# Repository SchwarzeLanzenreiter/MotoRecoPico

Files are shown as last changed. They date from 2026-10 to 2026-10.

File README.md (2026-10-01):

# MotoRecoPico

二輪車に積む CAN + GPS データロガー。**Raspberry Pi Pico 2 (RP2350)** を載せた自作基板で、
車両の CAN バスと GPS を microSD に記録する。記録したファイルは
[MotoRecoViewer](https://github.com/SchwarzeLanzenreiter/MotoRecoViewer) でそのまま開ける。

Raspberry Pi + HAT で動かしていた [MotoRecoLogger](https://github.com/SchwarzeLanzenreiter/MotoRecoLogger)
を、基板1枚に置き換えたもの。記録フォーマットは互換なので、過去のログも新しいログも同じツールで読める。

## リポジトリ構成

| ディレクトリ | 内容 |
|---|---|
| [`firmware/`](firmware/) | Pico 2 用ファームウェア（C / pico-sdk）。詳細は [firmware/README.md](firmware/README.md) |
| `cad/kicad/` | KiCad 10 プロジェクト、製造データ、生成・検査スクリプト |
| `cad/electronics/` | 旧 EAGLE 版（参考。現役は KiCad 側）|
| [`docs/`](docs/) | 設計ドキュメント。**[netlist.md](docs/netlist.md) が回路の正典** |

## ハードウェア

| 項目 | 内容 |
|---|---|
| 基板 | 4層、21 × 61 mm、部品 41点。リード部品は J1・Y1・Pico ヘッダのみ |
| MCU | Raspberry Pi Pico 2 (RP2350)。2×20 ソケットで交換可能。v4.2 で裏面実装 |
| CAN | Microchip MCP25625（コントローラ＋トランシーバ一体）を SPI1 で駆動 |
| GPS | YIC GT-502MGG-N。UART0 / 9600bps で NMEA を受ける |
| 保存 | microSD（Hirose DM3AT-SF-PEJM5）を SPI0 で駆動 |
| 車両I/F | TE MQS .63 8極。常時12V / IG / CAN High / CAN Low / GND の5本だけ使う |
| 電源 | 12V → AP63205 バックコンバータ → 5V。3.3V 系は Pico の 3V3(OUT) から |

**キーOFF 後も約 0.55 秒（実測）電源を保持する。** C13 が高側スイッチのゲート電荷を保つ仕組みで、
この猶予にファームウェアがログを閉じる。契約は [netlist.md](docs/netlist.md) §4.7。

設計の経緯（なぜ4層なのか、なぜこの配置なのか、各リビジョンで何を直したのか）は
[netlist.md](docs/netlist.md) と [hardware-design.md](docs/hardware-design.md) に残してある。
部品の購入先は [parts-sourcing.md](docs/parts-sourcing.md)。

## ファームウェア

- **単一ループ**で動く。割込みは CAN 受信と GPS UART の2つだけ
- CAN 受信は割込みでリングバッファへ退避。SD の書き込みが数百 ms 止まっても、
  コントローラの2段 FIFO を溢れさせない
- NMEA は自前でパース（Pi 版の gpsd の代替）。RTC が無いので GPS 時刻を単調時計に紐付ける
- FatFs R0.16 を同梱。SD の SPI ブロックドライバは自作
- ログの確定は **IG OFF 検出のみ**。車種依存を持ち込まないため、CAN 回転数は使わない
- タイムゾーンは microSD の隠しファイル `MOTORECO.CFG` で設定（再ビルド不要）
- ハードウェアに依存しない部分（NMEA・符号化・設定・IG 判定・時計）は
  **素の Pico 2 でも PC でもテストを実行できる**

ビルド方法・ログの読み方・トラブルシュートは [firmware/README.md](firmware/README.md) に。

## 記録フォーマット（`.dat`）

16バイト固定長レコードの連続。ヘッダも区切りも無く、すべてリトルエンディアン。

| オフセット | 型 | 内容 |
|---|---|---|
| 0 | `uint32` | ログ開始からの経過秒 |
| 4 | `uint16` | 同ミリ秒 |
| 6 | `uint16` | CAN ID（標準 11bit）|
| 8 | `uint8[8]` | ペイロード（DLC が 8 未満ならゼロ埋め）|

GPS は実在しない CAN ID に固定小数点で載せる。**`0x7FF`** が経度・緯度、
**`0x7FE`** が標高・速度。こうすると CAN と GPS が同じ1本の時系列に収まる。

> この形式は MotoRecoLogger（Pi 版）と MotoRecoViewer と**共有している契約**で、
> 変更すると3つのリポジトリすべてに影響する。

ファイル名は `YYYYMMDD_HHMMSS.dat`（キーOFF 時刻、ローカル時間）。GPS が測位するまでは
日付が分からないため `TMPnnnnn.DAT` で記録を始め、測位後に開始時刻の名前へ変える。

## 状態

- **実車で CAN・GPS ともに記録を確認済み**（2026-09）
- 基板は v4.2。実動作を確認したのは v4.1 の実基板（v4.2 は部品・ネット・GPIO 割当とも不変）
- 未確認: 記録した `.dat` を MotoRecoViewer で開く通しの確認

## 関連リポジトリ

- [MotoRecoLogger](https://github.com/SchwarzeLanzenreiter/MotoRecoLogger) — Raspberry Pi 版のロガーデーモン。本ファームウェアの移植元
- [MotoRecoViewer](https://github.com/SchwarzeLanzenreiter/MotoRecoViewer) — 記録した `.dat` を閲覧する Windows アプリ

## ライセンス

MIT License（[LICENSE](LICENSE)）。

同梱している ChaN FatFs は独自のライセンスに従う
（[firmware/third_party/fatfs/LICENSE.txt](firmware/third_party/fatfs/LICENSE.txt)）。

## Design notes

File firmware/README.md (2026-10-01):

# MotoRecoPico ファームウェア

Raspberry Pi 版ロガー（`MotoRecoLogger/mrlogger.c`）の Pico 2 (RP2350) 移植。
**`.dat` は Pi 版とバイナリ互換**で、MotoRecoViewer がそのまま開ける。

ピン割当・回路は [`../docs/netlist.md`](../docs/netlist.md) が正典。本書はソフト側だけを扱う。

## ビルド

pico-sdk と arm-none-eabi-gcc が必要。FatFs（R0.16）は
[`third_party/fatfs/`](third_party/fatfs/README.md) に同梱済み。

VS Code の Pico 拡張が入っている環境では、SDK もツールチェーンも `~/.pico-sdk` にある。
**`picotool_DIR` を渡すこと**（渡さないと SDK が picotool をソースから作ろうとし、
ホスト用 C コンパイラが無い環境では失敗する）:

```bash
cmake -B build -G Ninja -DPICO_BOARD=pico2 -Dpicotool_DIR=$HOME/.pico-sdk/picotool/2.2.0-a4/picotool
cmake --build build
```

`build/motorecopico.uf2` を BOOTSEL 起動した Pico にコピーする。

CAN バスなしでドライバを確かめたいときは `-DCAN_SELF_TEST=ON`。
MCP25625 をループバックにして、送信したフレームが戻るかを起動時に1回試す。

## テスト

ハードウェアに触らない部分（NMEA パーサ・レコード符号化・設定ファイル・IG 判定・壁時計）を検証する。
**実機（素の Pico 2 でよい。MotoRecoPico 基板は不要）でも PC でも走る。**

実機で走らせる場合 — `build/motorecopico_tests.uf2` を書き込み、USB シリアルを開く:

```
MotoRecoPico tests
checksum
GGA
...
<n> checks, 0 failures
ALL TESTS PASSED (0 failures).
```

**このテストはまだ一度も実行されていない**（開発機にホスト用 C コンパイラが無く、
Pico も接続されていないため）。コンパイルは両ビルドで通っている。最初に実機へ書き込んだ際、
失敗が出たらそれはテスト側の想定値の誤りかもしれない — 実装と突き合わせて判断すること。

実機で走らせる意味は結果だけではない。**`struct CANData` が arm で本当に16バイトに並ぶか**は
PC 上のテストでは確かめられない（`motoreco.h` の `static_assert` が実機ビルドで効く）。

PC で走らせる場合は `cd test && ./build.ps1`（MSVC）か `make`（gcc/clang）。

### 実機で確かめた数字

| 項目 | 実測 | 出所 |
|---|---|---|
| IG OFF 後の保持時間 | **約 0.55〜0.6秒** | 2026-09-04 の走行。`power still up 550ms` が最後の行で 600ms は書けなかった。§4.7 の「保証0.4秒・典型0.5秒」を裏付ける |
| 全 CAN のレコード数 | 約 1160/秒（約 18.5KB/秒）、33 ID | 実走ログ 1611秒の解析 |

シャットダウン処理（フラッシュ→sync→Close→リネーム）はこの 0.55秒に収める必要がある。
デバッグログ1行の書き込みは実測で数 ms 未満だった（生存ログの行がきっちり 50ms 刻みで並んだ）。

## 構成

| ファイル | 役割 |
|---|---|
| `src/main.c` | 初期化と単一ループ。CAN と GPS UART だけが割込み駆動 |
| `src/config.h` | ピン割当と全定数。設定ファイルの既定値もここ |
| `src/settings.c` | 設定ファイルのパース（純粋。PC でテスト可能）|
| `src/settings_file.c` | 同・FatFs 側（読み込み／既定値での生成／隠し属性）|
| `src/motoreco.h` | `struct CANData`。Pi 版と同一レイアウト（16バイト固定・LE）|
| `src/mcp25625.c` | CAN コントローラ。受信は割込みでリングバッファへ |
| `src/sd_spi.c` | SD の SPI ブロックドライバ |
| `src/diskio.c` / `src/ffconf.h` | FatFs との接続。`get_fattime()` は GPS 時刻を返す |
| `src/nmea.c` | GGA / RMC パーサ。gpsd の代わり |
| `src/wallclock.c` | GPS 時刻を単調時計に紐付けた壁時計 |
| `src/record.c` | `.dat` レコードの生成と GPS の固定小数点符号化 |
| `src/logger.c` | ファイルのライフサイクル、`f_sync`、デバッグログ |
| `src/led.c` | 緑LED の点滅パターン |
| `src/power.c` | IG OFF 判定の状態機械（純粋。PC でテスト可能）|

## Pi 版との違い

| | Raspberry Pi 版 | Pico 版 |
|---|---|---|
| CAN | SocketCAN (`can0`) | MCP25625 を SPI1 で直接。受信は割込み |
| GPS | gpsd | UART0 の NMEA を自前でパース |
| 保存 | ext4 上の `fopen`/`fwrite` | FatFs + 自作 SD SPI ドライバ |
| 時刻 | NTP 同期済みの system clock | GPS 時刻（RTC もバックアップも無い）|
| キーON/OFF | GPIO 27 を3回デバウンス | **GP28 の IG 検出**。0.55秒の猶予で確定する |
| 他プロセス連携 | System V 共有メモリ | 無し（Pico に相当物が無い）|
| デバッグログ | `canlogger.log` | `motoreco.log` ＋ USB シリアル |

## ログファイルの扱い

```
電源ON（＝IG ON）      TMPnnnnn.DAT を作って即記録開始
最初の GPS 測位        閉じて「開始時刻」の名前にリネームし、追記で開き直す
IG OFF（キーOFF）      フラッシュ → sync → Close → 「終了時刻」にリネーム → アイドル
異常断電               直前の f_sync までが確実に残る（最大1秒分の損失）
```

## ログの確定は IG OFF ただ1つ

**トリガは IG OFF だけ。** 以前は CAN の回転数低下でも確定していたが、CAN ID と
デコード式が車種ごとに違い、閾値も1台の実走データ由来だった。**イグニッション線は
どのバイクでも同じことを言う**ので、車種依存を持ち込まずに済むこちらへ一本化した。

デバッグログを `trigger:` で grep すれば確定の記録が出る:

```
[20260904 154302.233] trigger: ignition off (65mV). log closed and renamed as '20260904_154302.dat'
```

結果は成否だけでなく**何が起きたか**を出す（`logger_finalize_text()`）:

| 結果 | 意味 |
|---|---|
| `log closed and renamed as '...'` | 同期してリネームまで完了 |
| `log synced but not renamed, no gps time yet` | データは安全。GPS 未測位で名前が付けられない |
| `no log was open` | カード無し等 |
| `the card refused` | 書き込み失敗 |

**キーONのままエンジンが止まってもログは閉じない**（信号待ちのエンスト、休憩でエンジンだけ
切る等）。データ保全は毎秒の `f_sync` が担保し、確定は IG OFF で行われる。
回転数そのものは、これまでどおり CAN フレームとして `.dat` に記録される。

## IG OFF 検出（GP28）

**基板は IGN OFF 後 0.4秒（typ 0.5秒）だけ生き続ける**（C13 が Q2 のゲート電荷を保持し、
R1 経由でゆっくり放電するため）。この猶予でログを確定させるのがファームウェアの責務で、
契約は [`docs/netlist.md`](../docs/netlist.md) §4.7 に定義されている。

| 契約 | 実装 |
|---|---|
| GP28 を 50ms 以下の周期でポーリング | **10ms 周期のタイマ割込み**（`IG_POLL_INTERVAL_MS`）|
| 0.35V を下回ったら フラッシュ→Close→リネーム→アイドル | `logger_shutdown()`。**sync を最優先**し、リネームは後 |
| 猶予は保証 0.4秒（SD ストール最悪 250ms 込み）| 検出に使うのは 20ms（`IG_OFF_SAMPLES` 2回一致）|

**メインループではなくタイマ割込みで読む理由**は、SD の書き込みが数百 ms メインループを
止めることがあるためです。そこで検出まで遅れると猶予を食い潰します。
割込みは検出だけを行い、実際のファイル操作はメインループが担当します（FatFs は再入不可）。

### GP28 は電圧計ではない（v3 での変更）

**この基板では電池電圧は測れません。** v3 で R15(10k) が Q1 のベースノードに接続され、
そのノードは Q1 のベース・エミッタ接合によって**約0.65V にクランプ**されます。
つまり読めるのは **IG ON（≈650mV）/ OFF（0V）だけ**です。
0.65V はデジタル入力の VIH（約2V）未満なので、**ADC で読む必要があります**。

| 状態 | GP28 |
|---|---|
| IG ON | 約 650mV |
| IG OFF | 0mV |
| 閾値 | `IG_OFF_MV` 350mV / 復帰 `IG_ON_MV` 500mV |

status 行の `ig:` はこの**生のピン電圧**で、電池電圧ではありません:

```
status: rx:412033 records:398211 ig:651mV(on) | gps fix:1 ...
```

### 保持時間の実測（診断用・既定 OFF）

IG OFF 後、電源が尽きるまで 50ms ごとにログを書き続ける機能がある。
**カードに残った最後の行が実測値**で、2026-09-04 の走行で測った結果が以下:

```
[20260904 154302.233] trigger: ignition off (65mV). log closed and renamed as '20260904_154302.dat'
[20260904 154302.264] power still up 50ms after ignition off
[20260904 154302.314] power still up 100ms after ignition off
...
[20260904 154302.764] power still up 550ms after ignition off   ← ここで途切れた
```

**保持時間は約 0.55〜0.6秒**で、§4.7 の「保証0.4秒」に対し余裕がある。測定は済んだので
`config.h` の `IG_OFF_SURVIVAL_LOG` は **既定 0**。C13 や負荷を変えて測り直したくなったら
1 に戻す。電源が落ちかけている最中にデバッグログへ書き続けるため、その1ファイルが
chkdsk を要する形で壊れる可能性がある（**トリップログはこの時点で既に閉じて同期済み**）。

### 動作

- **一度 IG ON を観測するまで発火しない**（`armed`）。USB 給電のベンチで GP28 が 0V のまま
  でも誤ってシャットダウンしない
- **IG が戻ったら新しいログを開く**（USB 給電中にキーを戻した場合など）。閉じたファイルは
  閉じたまま、次のトリップは別ファイルになる
- アイドル中は **LED 消灯**（`LED_IDLE`）。「カード異常＝高速点滅」と紛らわしくないように
- アイドル中は 5秒ごとのカード再マウントも止める（せっかく閉じたログを開き直さないため）

## 設定ファイル `MOTORECO.CFG`

SDカードのルートに置く**隠しファイル**。無ければ起動時に既定値で自動生成する。
`#` で始まる行はコメント。テキストエディタで編集できる。

```ini
# MotoRecoPico settings
#
# Lines starting with '#' are comments. Edit with any text editor.
# This file is hidden; enable "show hidden files" to see it.
#
# timezone: offset from UTC, used for the .dat file names and the debug log.
#           whole hours (+8, -5) or with minutes (+5:30).
timezone = +9
```

| キー | 内容 | 既定 |
|---|---|---|
| `timezone` | UTC からのオフセット。`+9` / `-5` / `+5:30` / `+5.5` を受け付ける。`.dat` のファイル名とデバッグログの時刻に効く | `+9`（JST）|

- `key = value` でも `key value` でも通る。キーは**大文字小文字を区別しない**
- 読めない行は**その行だけ**無視してデバッグログに残す。ファイル全体を捨てたりはしない
- 正常時のログ: `settings: timezone +09:00`
- カードを差し替えると、その**カードの設定ファイルが読み直される**（マウントのたびに読む）

### 廃止された `vehicle` キー

以前はエンジン回転数のデコード規則（車種）を選ぶ `vehicle` キーがあった。
回転数によるログ確定をやめたので不要になっている。**古いファームで書かれたカードには
この行が残っている**ため、パーサは `vehicle` を「廃止済み」として黙って読み飛ばす。
手で消さなくても、起動のたびに警告が出ることはない。

## ピン割当（基板 v4.1）

正典は [`docs/netlist.md`](../docs/netlist.md) 3.7節。`src/config.h` がこれに追従する。

| 機能 | GPIO | 備考 |
|---|---|---|
| microSD | GP2/3/4/5 | **SPI0** SCK/MOSI/MISO/CS |
| SD カード検出 | GP7 | 外部プルアップ R13 |
| GPS UART0 | GP0（TX）/ GP1（RX）| GP1 にモジュールの TXD（オレンジ）|
| GPS PPS | GP6 | 未使用（入力のまま）|
| LED 緑 | GP8 | Low で点灯 |
| CAN MCP25625 | GP10/11/12/13 | **SPI1** SCK/MOSI/MISO/CS |
| CAN INT / STBY / RESET | GP9 / GP20 / GP21 | |
| IG 検出 | GP28 (ADC2) | 回転で変わらず。**ON/OFF のみ**で電池電圧は測れない |

**GP14〜GP19・GP22・GP26・GP27 は基板上で GND に落ちている。絶対に出力にしないこと。**

v4 からの差分は Pico の 180° 回転によるもので、**SPI インスタンスも入れ替わっている**
（SD が SPI1→**SPI0**、CAN が SPI0→**SPI1**）。ピンだけ直して SPI を直し忘れる事故を防ぐため、
`sd_spi.c` と `mcp25625.c` に「そのピンが本当にそのインスタンスの SCK/TX/RX か」を
`_Static_assert` で検査してある（RP2350 は 8ピンごとにインスタンス、4ピンごとに機能が巡回する）。

**stdio を UART に出してはいけない。** GP0/GP1 は SDK の stdio UART の既定ピンでもあるため、
有効にすると printf が GPS モジュールの受信端子に流れ込む。デバッグ出力は USB CDC のみ。

## LED（緑・GP8、Low で点灯）

| 表示 | 意味 |
|---|---|
| 点灯 | 記録中 |
| 1Hz 点滅 | 記録中だが GPS 未測位 |
| 高速点滅 | カードが使えない（応答なし／マウント失敗／書き込みエラー）。5秒ごとに再試行中 |
| 消灯 | IG OFF を検出してログを閉じた後（通常は直後に電源が落ちる）|

## GPS の状態ログ

測位に時間がかかるとき、原因は「配線・ボーレートが違って一切受信していない」「アンテナが空を見ていない」
「単にコールドスタート中」のどれかで、**どれも「未測位」としか見えない**。区別できるよう、
受信機自身の見え方をログに出す。

未測位の間は `GPS_REPORT_INTERVAL_MS`（既定10秒）ごとに:

```
gps searching after 30s: quality:0 mode:1D sats used:0 view:9 tracked:4 best snr:28 hdop:0.0 sentences:301 bad:0
```

読み方:

| 症状 | 出力 | 意味 |
|---|---|---|
| 何も受信していない | `gps silent: nothing received on uart0 in 30s...` | 配線・電源。モジュールは測位前から喋るので、無音は受信の問題ではない |
| 受信しているが壊れている | `sentences:0 bad:250` が増え続ける | ボーレート違い（文字化けでチェックサム不一致）|
| `view:0 tracked:0` のまま | 衛星が1個も見えない | アンテナ面が空を向いていない、金属ケース内、モジュール不良 |
| `view:9 tracked:1 best snr:15` | 見えてはいるが信号が弱い | 遮蔽（ビル・屋内・タンク下）。SNR 30以上が数個ないと測位しない |
| `view:9 tracked:5 snr:30+` で待ち | 正常な取得中 | あと数十秒待てば入る（下記のコールドスタート）|

測位した瞬間と失った瞬間にも1行ずつ出る（`gps fixed after 42s: ...` / `gps fix lost after ...`）。
最初の1文を受信した時点でも `gps talking: first sentence '$GNGGA' at 9600 baud` を出すので、
**配線とボーレートが合っているかは起動直後に確定できる**。

### 実機で確定した配線（2026-08-14）

**ボーレートは 9600bps**（`GPS_UART_BAUD` の既定値どおり）。線色と J3 パッドの対応:

| J3 パッド | シルク | 繋ぐ線 | 色 |
|---|---|---|---|
| 1 | V | VCC | 赤 |
| 2 | G | GND | 黒 |
| 3 | T | **RXD** | **緑** |
| 4 | R | **TXD** | **オレンジ** |
| 5 | P | PPS | 茶 |

**シルクの T / R は基板側から見た名前で、モジュールのピン名とは逆になる。**
UART は交差するので、`T`（基板が送信）にはモジュールの **RXD（緑）** が付く。
「TXD（オレンジ）を T に」と読んで配線すると出力どうしが衝突し、1バイトも受信できない
（実際にこれが起きた）。正典は [`docs/netlist.md`](../docs/netlist.md) 3.5節。

### 測位が遅いこと自体の原因

**J3 はバックアップ電源を持たない**（`docs/netlist.md` の J3 は VCC / GND / TXD / RXD / PPS の5線のみ）。
つまり**キーOFF のたびに軌道暦を失い、毎回コールドスタートになる**。
一般的な受信機のコールドスタートは晴天・見晴らしの良い場所で 30〜45秒、
条件が悪ければ数分かかる。ホットスタートなら1〜2秒で入るので、この差は大きい。

改善するならハードウェア側の変更になる:
- GT-502MGG-N にバックアップ端子があるなら、常時12V系からそこへ給電する（データシート 2.1節を要確認）
- あるいは J3.VCC を常時電源にする（受信機が待機電流を食い続けるためバッテリー上がりとの兼ね合い）

**現状のログはこの判断材料を出すためのもの**で、`gps fixed after Ns` の N が毎回30〜45秒なら
コールドスタートそのもの、毎回数分なら遮蔽かアンテナの問題、という切り分けができる。

## カード検出（GP7）の扱い

**カード検出ピン（GP7）は判断材料であって判断者ではない。** カードの有無は「SPI で応答するか」で決める
（[`sd_spi.c`](src/sd_spi.c) の `sd_init()` は検出線を見ずに必ず試す）。理由は3つ:

- 検出スイッチはソケットで**最も小さいパッド2枚（9番と10番）**に載っており、はんだ不良の確率が高い
- 接点が「挿入で閉」なのか「挿入で開」なのかは **DM3AT の図面に明記がない**（`SD_CD_INSERTED_LEVEL` は仮定）
- 二輪の振動でチャタれば、正常なカードを切り離してしまう

`SD_CD_INSERTED_LEVEL` を間違えていても**記録は普通に動く**。失うのは「走行中の抜去を早期に検出する」機能だけで、
それも実際に抜かれれば次の書き込み失敗で検出される。

走行中の抜去チェックは、**一度でも「検出線が挿入と言っている状態で実際にカードが応答した」場合にのみ**有効になる
（`sd_detect_reliable()`）。食い違ったまま動いた場合は起動時に一度だけ警告を出す:

```
note: card detect (GP7) reads empty with a working card. ignoring it.
      check pad 9/10 solder, or flip SD_CD_INSERTED_LEVEL
```

## データ量の目安（同じ実走ログより）

全 CAN で **約 1160 レコード/秒（約 18.5 KB/秒）**、33 種類の ID。
27分の走行で 30MB。受信リング 4096 レコードはこのレートで **約 3.5 秒分**にあたり、
SD カードの書き込みが数百 ms 詰まっても溢れない。

## 実機で最初に確認すること

1. USB シリアルに `MotoRecoPico starting` → `logging to '...'` → `can controller ready` が出るか
2. CAN が1フレームも来ない場合: `config.h` の `CAN_BITRATE`（既定 500kbps）と、
   終端抵抗 R8（`docs/netlist.md` の「CAN 終端は常時有効」）を疑う
3. カードが使えない場合、USB シリアルのメッセージで切り分ける:
   - `no card: the slot reads empty and nothing answered on the card spi` → SPI 配線（MISO/MOSI/CS）、
     カードの挿し込み不足、3V3 の供給
   - `a card is in the slot but no log file could be opened...` → **まず exFAT を疑う**。
     32GB超のカードは工場出荷時 exFAT で、`FF_FS_EXFAT 0` のため弾かれる。FAT32 で再フォーマット
   - `note: card detect (GP7) reads empty with a working card` → 記録は動いている。
     パッド 9/10 のはんだと `SD_CD_INSERTED_LEVEL` の極性を後で確認すればよい
4. GPS のボーレート（`GPS_UART_BAUD`、既定 9600）
5. キーOFF で `trigger: ignition off (...)` が出て、ファイル名が終了時刻になっているか
6. 記録した `.dat` を MotoRecoViewer で開き、Pi 版のログと同じように描けるか

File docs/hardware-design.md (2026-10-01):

# MotoRecoPico ハードウェア設計仕様

Raspberry Pi Pico 2 ベース CAN ロガー（二輪車搭載）

- 対象: 車両12V電源のみ、MQS 8極コネクタ直結、MicroSD 基板実装
- 基板: 4層、21 × 61 mm。チップ部品は 1608（JLCPCB 実装）

> **回路の詳細（部品表・ネットリスト・電源アーキテクチャ・ピン割当）は
> [netlist.md](netlist.md) が正典。** 本書はコネクタ／フットプリントの一次資料からの
> 導出根拠と基板レイアウトのみを扱う。
>
> 旧版にあった LM2596 / GPS用LDO / ラッチング電源 / 赤LED / GPSスルーホールの
> 記述は設計変更により無効。削除済み。

---

## 1. 部品構成（確定分）

| 部品 | 型番 | パッケージ | 備考 |
|---|---|---|---|
| MCU | Raspberry Pi Pico 2 (RP2350) | 2×20 2.54mm ヘッダ | ソケット実装で交換可能に |
| CAN | MCP25625T-E/SS | SSOP-28 (0.65mm) | コントローラ＋トランシーバ一体 |
| GPS | GT-502MGG-N | 外付け（1.5m 先バラ5線） | 片面 SMD パッドに直付け |
| 保存 | Hirose DM3AT-SF-PEJM5 | SMD ライトアングル | プッシュプッシュ式、カード検出付 |
| 車両I/F | TE 1-967658-1 | MQS .63 8極 2列 4mm ライトアングル TH | 車両カプラー直結 |
| 降圧 | **Diodes AP63205WU-7**（v4） | TSOT-26 + L/C 4点 | 3.8〜32V入力 / 5V固定 2A 同期整流。最背は L1 の 3mm |
| 高側スイッチ | **Diodes ZXMP6A17E6Q** | SOT-26 | −60V / −3A / AEC-Q101 |

### MQS コネクタ ピン割当（ユーザー指定）

| ピン | 信号 |
|---|---|
| 3 | IG ON 時 12V |
| 4 | GND |
| 5 | CAN Low |
| 6 | CAN High |
| 8 | 12V 常時 |

未使用: 1, 2, 7

### MQS コネクタ フットプリント（図面 967658 Rev.C3 より確定）

原点はコネクタ前面基準線上の中心 ¢。+X は右、+Y は基板端（嵌合方向）。
穴は基準線から Y マイナス方向（基板内側）へ。

| ピン | X [mm] | Y [mm] | 列 |
|---|---|---|---|
| 1 | +7.0 | −3.76 | 前列（下段コンタクト） |
| 2 | +3.0 | −3.76 | 前列 |
| 3 | −1.0 | −3.76 | 前列 |
| 4 | −5.0 | −3.76 | 前列 |
| 5 | +5.0 | −6.30 | 後列（上段コンタクト） |
| 6 | +1.0 | −6.30 | 後列 |
| 7 | −3.0 | −6.30 | 後列 |
| 8 | −7.0 | −6.30 | 後列 |

| 項目 | 値 |
|---|---|
| 穴径 | ⌀1.0mm 以上（8ヶ所）→ ドリル 1.1mm、パッド ⌀1.8mm 推奨 |
| 列内ピッチ | 4.0 ±0.1mm |
| 列間ピッチ | 2.54 ±0.1mm |
| 列間の水平オフセット | 2.0mm（千鳥配置） |
| 基準線→前列 | 3.76mm（= 6.3 − 2.54） |
| 基準線→後列 | 6.30 −0.1mm |
| ハウジング幅 | max 19.6mm |
| ハウジング全高 | 18.1 ±0.15mm |
| テール突出量 | 3 ±0.25mm |
| 位置度公差 | ⌀0.3 (8ヶ所) |

**ピン番号の導出根拠**: 嵌合面視では下段が左から 1・2・3・4、上段が左から 5・6・7・8。
断面図 G-M より、上段コンタクトのテールは嵌合面から遠い側（後列）、下段は近い側（前列）に降りる
（上段テールの垂直部が下段コンタクトの水平部と干渉しないため、必然的にこうなる）。
嵌合面視の左右は基板上面視と反転するため、上表の X 座標になる。

材質: ハウジング PBT-GF20 (Ultradur B4300-G4) 黒 / コンタクト CuFe2 錫めっき
相手側ハウジング: AMP 1534229（8極）　製品仕様書: 108-18568

図面の注記 7 に「この領域は全周シール面（Ra 0.7µm）」とあり、
**相手側ハウジングと組んだ状態ではシール構造を持つ**。当初「MQS は非防水」と記載したが誤りだった。
ただしケース貫通部のシールは別途必要。

---

## 6.1 基板レイアウト

外形 **21 × 61 mm（12.8cm²）**、**4層**。設計データは `cad/kicad/` の KiCad 10 プロジェクト。

| 面 | 部品 |
|---|---|
| 表 | 26点。**J1（v4で移動）**、U2、J2、1608 チップ23点すべて。**v4.2 で Pico が裏面に移り、J1 以外は全て低背で露出** |
| 裏（Pico側）| 15点。**U3(Pico ソケット、v4.2)**、Y1、J3、バック一式（U4/L1/C14-C16）と SOT/SOD/SMA（**1608 は無し**）。Pico の下の最背は 3mm |

### 層構成

| 層 | 用途 | 実配線長 |
|---|---|---|
| F.Cu | 信号 | 227mm |
| In1.Cu | **GND プレーン** | 158mm |
| In2.Cu | **3V3 プレーン** | 145mm |
| B.Cu | 信号 | 196mm |

**2層は二度試し、二度とも採らなかった。** v1 では 0.127mm（工程下限）を要したうえ
GND ベタが8分断・7浮き。v2 で部品が3点減った際に再試行したが、配線は通っても
**サーマルスポークが届かない GND パッドが 2〜6点残り**（5シード×ギャップ3種の全組合せ）、
サーマル接続という v2 の目的と両立しなかった。4層は 0.15mm・スポーク全数到達で成立する。
基板代は5枚で $2.10 → $7.10（+$5.00、送料込み総額で +17%）。

**内層にも信号が乗っている。** ルータには内層をプレーンとして渡したが、
Freerouting は必要に応じてその上も通す。
それでも In1 の GND 銅箔は **1領域が全体の100%**（v4.2: 972.2mm²、分断ゼロ。In2 の 3V3 も 1 領域 881.1mm²）で、
プレーンとしては分断されていない。この配線密度でしか 0.15mm 線幅が成立しないため、
分断されない範囲での内層使用は許容している。

**外層のベタは配線後に流す。** 配線前に F.Cu / B.Cu へ GND を流し込むと、
Freerouting が信号層を使いきれず未配線が残った。GND を運ぶのは内層プレーンなので、
外層は配線が終わってからベタにしている。

**1608 チップは全数（23点）を表面に集約**してある（v3。実装とリワークを片面に限定するため）。
それより大きい部品は両面に分かれる。

### 外形寸法が決まる理由

**長さ61mm は幾何的な下限に近い。** MQS の穴は Pico のヘッダー穴列と X 方向で 1.89mm しか
離れず、⌀1.8mm パッドでは隙間 0.09mm となり製造不可能。よって MQS はヘッダー格子の
外側に自分の帯を必要とする。

MQS ハウジングは基板上に 8.0mm せり出す。ユーザー指定によりヘッダーとの隙間は
**0.57mm** としてある。v4.2 で Pico ソケットが裏面に移ったため、MQS のテール（裏面ではんだ付け）と
ソケット本体が同じ面で 0.1mm まで近づく。**MQS を先にはんだ付けし、ソケットを後から立てる組立順**が前提。

**幅21mm は Pico のフットプリント幅そのもの。** ヘッダー穴列が x=1.61 / 19.39 にあるため、
使える領域は列の間の 15.2mm しかない。側面発光LEDと GPS パッドは長辺に置けず、
LED は短辺（y=61）へ、GPS パッドは裏面中央へ回した。

| 辺 | 実装 |
|---|---|
| 短辺 y=0 | J1（**表面**（v4）、嵌合口が基板外を向く。穴パターンは v3.1 の鏡像）|
| 短辺 y=61 | J2 MicroSD（表面、挿抜口が基板端の内側約1mm）、D6 サイドビューLED（裏面）、**Pico の USB ポート（v4.1 で y=61 端へ、v4.2 で裏面側・ソケット高 +8.5mm の位置）** |

**LED・カードスロット・USB が同じ短辺に集まるため、ケースの開口はこの端面に集約できる。**
y=0 端は MQS カプラのみ。

**Pico は裏面に載せてある（v4.2）。** 面反転はフットプリントの x 鏡像なので穴は1つも動かず、
ピン1〜20 の列が左（x=1.61）に、21〜40 が右に入れ替わるだけ。v4.1 の GPIO 割当は y 方向の
近さで決めてあり鏡像で保たれるため、**再割当もファームウェア変更も無い**。狙いは表面を
J1 以外すべて低背部品（U2・J2・1608 チップ）にして、Pico を外さずに実装・リワーク・
プロービングできるようにすること。裏面の電源ポケット・Y1・J3 は Pico の下（ソケット高 8.5mm、
部品最背 3mm）に入る。**J3 の GPS 配線は Pico を抜いてはんだ付けする。**

**Pico は 180° 回転してある（v4.1）。** v4 で J1 が表面に来た結果、USB コネクタが
18.1mm の MQS ハウジングの 0.6mm 隣を向き、ケーブルが物理的に挿せなかった。
2×20 ヘッダー格子は 180° 回転対称なので**穴は 1 つも動かず**、各穴に入るピンが
対角（k ↔ k+20）に入れ替わるだけ。GND ピン 8 本は対称位置どうしが共に GND のため
バレルの役割も不変。ただし信号ピンの物理位置は全て裏返るため、
**GPIO 割当は回転後の距離で再導出した**（SPI0↔SPI1 の役割交換が鍵。
正規の表は netlist.md §3.7。ファームウェアのピン定義変更が必要）。

### 配置で守った設計上の要件

**U2 を 90° 回転してある。** 回転前は SSOP-28 の2列が長辺を向き、28ピンすべてが
幅 3.1mm の側方通路へ脱出しようとしていた。物理的に通らない。

**U2 のデカップリングは IC の左右（脱出領域の外）に置いた。** 上下に置くと
28ピンの扇形展開を塞ぐ。チップは 90° 立てて側方の隙間に収めている。

**裏面の大物2点（Y1・J3）は 90° 回転して右側に縦積み。** 寝かせると幅12mm 前後で
15.2mm の帯を横断し、裏面が分断されて縦方向に何も通らなくなる。

**Y1（水晶）は裏面。** HC-49/S はスルーホール品なので、差し込む面＝本体が乗る面。
v4.1 までは Pico が表面を占有するため裏面から挿していた。v4.2 で Pico も裏面に来たが、
HC-49/S の高さ（3.5〜4.7mm）はソケット高 8.5mm の下に収まるのでそのまま。パッドは両面にあるのでビアは不要。

**C7/C8（水晶負荷）は表面で Y1 の両バレルを挟む明示配置（v3）。**
Y1 のスルーホールが XTAL ネットを表面へ運ぶため、コンデンサはビアなしでバレル直結できる。
v2 では左端ゾーン任せで 11.1 / 9.0mm 離れ、XTAL1 が In1 プレーンの中を 8.5mm 通っていた。
v4.2 実測: C7 2.24mm / C8 2.77mm、XTAL1 9.7mm（ビア0・内層0）/ XTAL2 14.6mm（ビア0・内層0）。
ゾーン任せでは他ゾーンのスピルに枠を奪われるため EXPLICIT で固定してある。
C8 の回転は 270°（90° だとピン1が遠い側を向く）。

**電源部品は電気の流れ順に一列。** J1 → F1 → D1 → Q2 → U4(バック) を、給電ピンの位置から
素直につながる順序で裏面に並べてある。**v4 で J1 の面反転に伴い列全体を左右鏡像化**した
（12V の入口が x17.5 → x3.5 に移ったため。左から右へ F1 → D1 → Q2、バックは直下）。

| 区間 | ピン間距離 |
|---|---|
| V12_RAW（J1.8 → F1.1）| 3.47mm |
| V12_FUSED（F1.2 → D1.2）| 1.85mm |
| V12P（D1.1 → Q2.4）| 3.40mm（v4.2、Q2 立て置き）|
| V12_SW（Q2 → U4.VIN）| 6.40mm |
| **合計** | **15.12mm**（v4.2。v4 は 14.83mm）|
| SW ノード（U4.SW → L1）| 3.99mm（v4.2、L1 回転。v4 は 2.09mm）|
| 入力コンデンサ（U4.VIN ↔ C14）| 2.90mm |
| 出力コンデンサ（L1 ↔ C15）| 3.07mm |
| ブートストラップ（U4.BST ↔ C16）| 4.03mm |

見直し前は同じ経路が **36.1mm** あった。12V が J1 の右端（x=17.5）から入るのに
F1 が 17mm 下の中央にあり、そこから左端 → 上 → 右へ戻る「コの字」を描いていた
（第1区間だけで 17.4mm）。DC 100mA 程度なので機能上の問題ではないが、
入力側の電流ループを締めるのと、レイアウトを追える状態にしておくために直した。

**Q2 は U4 と同じ手はんだ用ランドで 90° 立てて配置（v4.2）。** v4.1 の標準 SOT-23-6 ランドは
パッドが短く、実基板でゲートリードの未はんだが起きた。2.0×0.65mm パッドにすると幅 6mm になり
F1/D1 の列に入らないため、右列に立てて S/G を D1 側、ドレインを基板端側に向けてある。
パッド番号は JEDEC 順のままなので、G=3 / S=4 のビルド毎 assert はそのまま効いている。

**L1 はパッドを外側へ 1mm 延長した自作ランドで 90° 回転（v4.2）。** 標準ランドは 4×4 本体の外に
こて先を置く銅箔がなく、U4 の SW パッドとも近接していた。延長ランド（`L_4030_HandSolder`）を
±y 向きに置き、SW 側パッドを U4 の SW 列の横（4.0mm）、V5 側を直下の C15（3.1mm）に繋いでいる。

**裏面左端の電源スタックは Pico 左列パッドから 2.5mm 離してある（v4.2）。** 面反転で CAN の
SPI 4 本が左列から出て U2 上段右端の SPI ピンへ向かうため、左端に 1.3mm しか残さない詰め方では
CAN_MISO が 20 シード中 19 で未配線になった。L1 左端 x4.9、D2/Q1/D3 左端 x4.0 に寄せている。

**バック一式（U4・L1・C14〜C16）は U1 が空けた裏面ポケット（y13〜21）に収めた（v4）。**
v4 では U4 と L1 を SW パッド同士が向き合う回転で明示配置した（逆向きだと SW ノードが 8.5mm に伸びる）。
C14（入力 10µF/50V）は U4 の VIN 列の右隣 — 初回は U4 の手はんだ用コートヤード内に
置いてしまい DRC が短絡を検出したため、ブロック全体を 2.4mm 左に詰めて確保した。
v4.2 では Q2 の立て置きと L1 の回転に合わせて、U4 を 1mm 下げ、C14 を Q2 の下、C16 を U4 の下、
C15 を L1 の V5 パッド直下に組み替えてある（いずれも `mrp_brd.py` の EXPLICIT で固定）。

**C2 は右フランクに単独の枠を持つ。** チップがまだ 1005 だった頃、耐圧の都合で
C2 だけを 1608 に上げた。すると自動配置が面積の大きい順に詰めるため C2 が分圧抵抗の
ゾーンの左端を取り、**R1〜R4 が 2.75mm 右へずれた**。それだけで SD_CD が J2 の脇を
抜ける通路を失い、どのルータ設定でも1本残った（`-oit` と `-mp` を6通り試して全て1本）。
C2 に専用枠を与えて分圧抵抗の列を元に戻したところ、1回目で未配線0になった。

その後チップは全数 1608 になり C2 は特別な大きさではなくなったが、
**この枠は検証済みの配置なので残してある**。

**R8（CAN 終端 120Ω）は U2 の南側、CANH/CANL が出るパッドの直下。**
当初これを U2 の西側（x 2.9〜5.6）に置いていたところ、U2 の北西角から
Pico 左列へ回り込む唯一の通路を塞ぎ、CAN_RESET が最後まで配線できなかった。
本来ここにあるべき部品で、移して未配線 0 になった。

### 検証済み項目

| 項目 | 結果 |
|---|---|
| 部品配置 | 41点、表26 / 裏15（v4.2: Pico が裏面）|
| チップ部品（1608）| 23点すべて表面（自動検査を C1608 まで拡大）|
| 同一面での部品重なり | なし |
| 他部品の穴の上に本体が乗っていないか | なし（自動検査）|
| 基板外形からのはみ出し | なし（J1 のみ設計どおり y=0 辺を越える）|
| 回路図とのネット一致 | 40ネット すべて一致 |
| 配線 | 全数完了。328トラック / ビア182本（うち GND 137本）。XTAL 内層0はシード選定で自動保証（xtal_check）|
| DRC 違反 | 0件 |
| 未接続パッド | 0個 |
| 浮き銅片（ビアもパッドも無いベタ領域）| 0個（全6領域を実測）|
| 電源チェーン長 | 14.83mm（v1 初版 36.1mm）|

**GND パッドは全数サーマル接続（v2）。** スポーク 0.4mm / ギャップ 0.3mm / 最小スポーク数 1。
v1 のベタ直結は手はんだ時の熱逃げが酷く、実基板で許容できないと判断して改めた。
スポークが全パッドに到達していることは DRC の未接続0で担保している。

配線は Freerouting で実施。GND は F.Cu / In1.Cu / B.Cu の3層に流し、
スティッチングビアで4層を結合してある。スティッチングビアは全パッド・全ビアとの
間隔に加えて **ドリル穴どうしの間隔 0.25mm** も満たすよう配置前に検査している
（同ネットどうしはクリアランス規則が消えるが、**ドリル間隔規則は残る**。
これを見落として GND ビアを障害物から外し、配線ビアの穴に食い込ませたことがある）。

**スティッチングビアは、他ネットのスルーホールから 2.2mm の堀（moat）を保つ（v4.1）。**
貫通ビアは内層プレーン両方にクリアランスの空洞を開けるため、1mm 格子のビア群が
他ネットの PTH パッドを囲むと、そのパッドがプレーンから受けるべきサーマルスポークを
全方向で塞ぐことがある。v4.1 の Pico 回転で 3V3 ピン（パッド36、In2 プレーンから給電）が
J2 の GND パッド近傍圏に入り、ビアの檻に包囲されて**全 8 シードで未接続 1** という
決定論的な失敗になった。ネットを持つ非 GND の PTH パッドの周囲 2.2mm を除外することで、
パッドのサーマル空洞の外側に 0.5mm 以上のフィルの環が常に残り、スポークが成立する。

製造データは `cad/kicad/fab/`。ガーバーは4層分（`.gtl` / `.g1` / `.g2` / `.gbl`）を
出力し、`MotoRecoPico-gerber.zip` にまとめてある。ドリルは PTH / NPTH 分割。

---

## 7. 参考資料

- [MCP25625 データシート (DS20005282B)](https://akizukidenshi.com/goodsaffix/mcp25625.pdf) — ピン配置 Table 1-1 (p.4)、参考回路 Figure 1-2 (p.5)
- [GT-502MGG データシート](https://akizukidenshi.com/goodsaffix/GT-502MGG.pdf) — ピン説明 2.1 節 (p.7)、DC特性 1.3 節 (p.6)
- [DM3AT-SF-PEJM5 2D図面 ADC-325165-00-01](https://www.hirose.com/ja/product/p/CL0609-0031-0-00) — 推奨基板パターン（実装面側）
- [M78AR05-0.5 データシート](https://akizukidenshi.com/goodsaffix/m78a.pdf) — 機構寸法 p.3、Note 6/7 p.2
- [LP812-010(T) データシート](https://akizukidenshi.com/goodsaffix/lp812-010(t).pdf) — 推奨はんだ付けパターン p.3
- [Raspberry Pi Pico 2 データシート](https://datasheets.raspberrypi.com/pico/pico-2-datasheet.pdf) — 3V3(OUT) 負荷上限、VSYS 給電方法
- [TE 1-967658-1 製品ページ](https://www.te.com/en/product-1-967658-1.html)
- [ZXMP6A17E6Q データシート](https://www.diodes.com/datasheet/download/ZXMP6A17E6Q.pdf)

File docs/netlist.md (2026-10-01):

# MotoRecoPico 部品表・ネットリスト

[hardware-design.md](hardware-design.md) の設計を、リファレンス記号と定数まで落としたもの。
回路図はこの内容をそのまま描画する。

**小型化のため大幅に簡素化した版。部品 58点 → 38点（v2 で 35点）。リファレンス記号は振り直した。**

v4.2（2026-08-23、v4.1 実基板の手はんだ経験を受けた改訂）:
- **Pico を裏面へ**（面を反転。穴位置・GPIO 割当・ファームウェアは不変。§4.11）
- **Q2 を U4 と同じ手はんだ用ランド**（パッド 2.0×0.65mm）に変更し、90° 立てて配置
- **L1 のパッドを外側へ 1mm 延長**した自作ランドにし、90° 回転して U4 の SW パッドから離す
- 部品・定数は完全不変

v4.1（2026-08-14）:
- **Pico を面はそのまま 180° 回転**（USB ポートが microSD 側 y=61 端を向く。§4.10）
- **GPIO を回転後の位置で再割当**（SD=SPI0 GP2〜5、CAN=SPI1 GP10〜13、GPS=UART0 GP0/1。
  **ファームウェアのピン定義変更が必要**。IG_SENSE は GP28 のまま）
- 穴位置は 1 つも変わらない（2×20 グリッドは 180° 回転対称。部品構成も完全不変）

v4（2026-08-14）:
- **5V 電源を M78AR05（SIP、10.2mm高）→ AP63205WU-7（TSOT-26 同期整流バック＋L/C 4点、最背3mm）に**（§4.9）
- **J1 を表面実装に反転**（車両カプラが Pico 側から刺さる。穴パターンは鏡像化）
- **GPS シルクの T/R を修正**（v1 で逆だった。パッド3=R、パッド4=T）
- 副次効果: 最低入力 3.8V となり**クランキング時リセットの残課題が解消**

v3.1（2026-08-13、**重要な不具合修正**）:
- **Q2 のパッド対応が実部品と鏡像だった問題を修正**（v1〜v3 全てに影響。§4.8）

v3（2026-08-09、ソフト電源OFF ほか）:
- **IGN OFF 遅延を追加**（C13: Q2 ゲート遅延 約0.4〜0.5s、R15: GP28 への IG 検知。§4.7）
- **C7/C8 を Y1 の直近に移設**（2.2/2.8mm。XTAL の内層通過を解消）
- **C6・C11 を表面へ移動し、1608 チップ23点を全数表面に集約**

v2（2026-08-08、v1 実基板の実装経験を受けた改訂）:
- **IG 電圧センシングを廃止**（R5・D4・C12 と GP28 接続を削除。IG 検出スイッチは存続）
- **GND パッドをベタ直結 → サーマル接続に**（手はんだ性。スポーク 0.4mm / ギャップ 0.3mm）
- 2層化を試行したが不成立（下記 §4.6）。**4層を継続**

v1 の主な変更:
- 降圧を LM2596 + 外付け4点 → **M78AR05-0.5**（インダクタ・コンデンサ内蔵）1点に
- GPS 用 LDO を廃止し **Pico の 3V3(OUT) から供給**
- ラッチング電源を廃止し **IG 信号(J1.3)で駆動する高側スイッチ**に
- 12V センスを1系統に統合、ラジアル部品を全廃
- U1 の入力コンデンサ C1 を削除（入力上限 32V→28V、D2 を SMAJ16A に）
- CAN 終端をスプリット（R8+R9+C9+JP1）から **120Ω 1本**に。**D5 (PESD1CAN) も廃止**
- Pico の GPIO 割当を基板配置に合わせて再割当（CAN=SPI0、SD=SPI1、GPS=UART0）

> **この文書が正典。** KiCad の回路図と基板はこの内容から生成している。
> 生成物と食い違いを見つけた場合は、この文書の側を実データと突き合わせて直すこと。

---

## 1. 部品表（BOM）

### 1.1 コネクタ・モジュール

| 記号 | 部品 | 型番 | パッケージ | 備考 |
|---|---|---|---|---|
| J1 | 車両I/Fコネクタ | TE 1-967658-1 | MQS .63 8極 RA THT | Mouser。**表面実装（v4）** |
| J2 | MicroSDソケット | Hirose DM3AT-SF-PEJM5 | SMD RA | 秋月 102395 |
| J3 | GPS配線パッド | GT-502MGG-N 用 | **SMD パッド × 5（片面）** | スルーホール無し |
| U4 | 降圧DCDC | **Diodes AP63205WU-7** | TSOT-26 | 3.8〜32V入力 / 5V固定 2A 同期整流。裏面実装（v4）|
| U2 | CANコントローラ | Microchip MCP25625T-E/SS | SSOP-28 | 秋月 112663 |
| U3 | MCU モジュール | Raspberry Pi Pico 2 | 2×20 ソケット | 表面実装 |

### 1.2 半導体

| 記号 | 部品 | 型番 | パッケージ | 目的 |
|---|---|---|---|---|
| Q1 | NPN | MMBT3904 | SOT-23 | IG検出でQ2ゲートを引き下げ |
| Q2 | Pch MOSFET | **Diodes ZXMP6A17E6Q** | SOT-26（**v4.2: U4 と同じ手はんだ用ランド**）| 高側スイッチ。−60V / −3A / AEC-Q101 |
| D1 | ショットキー | **B5819W（1A/40V）** LCSC C8598 | **SOD-123** | 逆接保護（直列）。JLC Basic |
| D2 | TVS | **SMAJ16A（400W）** | **SMA** | 入力サージのクランプ。**クランプ26.0V < U1の28V上限** |
| D3 | ショットキー | **B5819W（1A/40V）** LCSC C8598 | **SOD-123** | VSYS給電。USBとのダイオードOR。JLC Basic |
| D6 | LED 緑（側面発光）| KODENSHI LP812-010(T) | サイドビュー 2812 | 秋月 116854。基板端。**唯一の表示** |

**CAN バスの ESD 保護素子は無い。** MCP25625 自身のバス耐圧（±14V）と ESD 耐性に依存する。
車両ハーネス直結でサージが入る経路であることは意識しておくこと。

### 1.3 抵抗（全て **1608** = 1.6×0.8mm / 0603）

| 記号 | 値 | 目的 |
|---|---|---|
| R1 | 100k | Q2 ゲート → ソース プルアップ（既定OFF） |
| R2 | 100k | Q2 ゲート → Q1 コレクタ（**Vgs = 電源の1/2 に制限**） |
| R3 | 100k | IG → Q1 ベース。ベース電流制限（サージ時も 1mA 未満）|
| R4 | 22k | Q1 ベース → GND。IG 浮遊時にベースを確実に落とす |
| R6 | 10k | MCP25625 RESET プルアップ |
| R7 | 10k | MCP25625 **TxnRTS 3本の共通**プルアップ |
| R8 | **120Ω** | CAN 終端。CANH–CANL 間に1本 |
| R10 | 10k | SD CD_DAT3(CS) プルアップ |
| R11 | 10k | SD DAT0(MISO) プルアップ |
| R12 | 10k | SD **DAT1/DAT2 共通**プルアップ |
| R13 | 10k | SD カード検出 プルアップ |
| R14 | 1k | LED 電流制限（5Vから約2.0mA）|
| R15 | 10k | **v3** IG検知。Q1 ベースノード → GP28 (ADC2) の直列保護 |

### 1.4 コンデンサ（全て **1608** = 1.6×0.8mm / 0603）

100nF は全数 **50V** 品。1608 なら 50V が JLCPCB の Basic 部品にあるため
（1005 だと 16V しか無く、C2 だけ別扱いにする必要があった）。

| 記号 | 値 | 目的 |
|---|---|---|
| C2 | 100nF / 50V | **V12P（常時12V）のバイパス。D2 のサージ電流ループをローカルに閉じる** |
| C3 | 100nF | MCP25625 VIO |
| C4 | 100nF | MCP25625 VDD |
| C5 | 100nF | MCP25625 VDDA |
| C6 | 10µF | MCP25625 VDDA バルク |
| C7 | 22pF | 水晶 負荷容量 |
| C8 | 22pF | 水晶 負荷容量 |
| C10 | 100nF | SD VDD |
| C11 | 10µF | SD バルク（書き込みピーク）|
| C13 | 10µF / **25V** | **v3** Q2 ゲート–ソース間（R1 と並列）。IGN OFF 遅延 約0.4〜0.5s |
| C14 | 10µF / **50V**（**3216**）| **v4** バック入力。クランプ26Vを直接見るため50V必須 |
| C15 | 22µF / 16V（**2012**）| **v4** バック出力（V5 バルク）|
| C16 | 100nF / 50V（**2012**）| **v4** ブートストラップ（BST–SW間）。1608片面規則を守るため2012 |

### 1.5 その他

| 記号 | 部品 | パッケージ | 備考 |
|---|---|---|---|
| F1 | PTC ヒューズ 1A hold | 1206 | U1 データシートの推奨（5V品は1Aスローブロー）|
| Y1 | 水晶 16MHz | HC-49S | **裏面実装** |
| L1 | インダクタ 6.8µH | 4030（4×4×3mm）| **v4** バック用。ASPI-4030S-6R8M 等、飽和 ≥1.5A。**v4.2: パッドを外側に 1mm 延長した自作ランド** |

**合計 41点。リード部品は J1・Y1・Pico ヘッダのみ。** 表面の背高部品は J1（18.1mm、v4 で表面へ）のみ。裏面は v4.2 で Pico（ソケット 8.5mm ＋ 本体）が乗り、その下の部品の最背は L1 の 3mm。
（v2 で R5・D4・C12 削除、v3 で C13・R15 追加、v4 で U1 → U4/L1/C14/C15/C16。§4.6〜§4.9 参照）

### CAN 終端は常時有効

R8 の 120Ω が CANH–CANL 間に固定で入る。切り離す手段は無い。

**二輪車の CAN バスは通常すでに両端が終端されている。** そこへ本機を割り込ませると
バス全体が 120Ω ∥ 120Ω = 60Ω（既存2本と合わせて 40Ω）になり、通信が成立しない可能性がある。
バス端に単独で接続する場合や、ベンチ試験でのみ妥当な構成。
実車で通信できない場合は、まず R8 を外して確認すること。

### ~~U1 入力コンデンサを削除したことによる定格変更~~（v4 で U1 廃止・記録として残す）

M78AR05 の入力上限は **32V → 28V** になる（データシート Note 7 の
「入力に 22µF/50V があれば 32V まで許容」という条件が外れるため）。
モジュールは内部にフィルタコンデンサを持つので、動作そのものには外付けは不要。

これに合わせて **D2 を SMAJ18A から SMAJ16A に変更**した。

| | SMAJ18A | SMAJ16A |
|---|---|---|
| スタンドオフ | 18V | 16V（充電電圧14.4Vより上）|
| **クランプ電圧** | 29.2V（**28V超過**）| **26.0V** ✓ |

**SMAJ18A に戻してはいけない。** クランプ 29.2V が U1 の入力上限 28V を超える。

---

## 2. 電源アーキテクチャ

```
J1.8 (常時12V) ─ F1(1A PTC) ─ D1(SOD-123) ─┬─ D2(SMAJ16A TVS)
                                            ├─ C2(100nF)
                                            ├─ R1(100k) ─┐
                                            │            │
                                            └─ Q2.S      │
                                                 Q2.G ───┤
                                                 Q2.D    │
                                                  │   R2(100k)
                                                  │      │
                                                  │   Q1.C
J1.3 (IG信号) ─ R3(100k) ─┬─ Q1.B                       Q1.E ─ GND
                          ├─ R4(22k) ─ GND
                          └─ R15(10k) ─ U3.GP28 (ADC2。IG検知、v3)

（v3）C13(10µF) が Q2 の G–S 間に入り、IGN OFF 後も Q2 が約0.4〜0.5s 導通を保つ

Q2.D ─┬─ C14(10µF/50V) ─ GND
       ├─ U4.EN
       └─ U4.VIN ⇒ U4.SW ─ L1(6.8µH) ─┬─ V5 ─┬─ U2.VDDA (MCP25625)
（AP63205: BST–SW間に C16、V5 に C15/22µF と U4.FB）│
                                                  ├─ D3 ─ U3.VSYS (Picoへ。USBとOR)
                                                  └─ R14 ─ D6 LED緑

U3.3V3OUT ─ V3V3 ─┬─ U2.VIO / U2.VDD
                   ├─ J2 (MicroSD)
                   ├─ J3.VCC (GPS 50mA)
                   └─ 各プルアップ
```

**IGN OFF 後、電源は約0.4〜0.5秒だけ保持される（v3）。** C13 が Q2 のゲート放電を
R1 経由に限定するため。ファームウェアは GP28 で IG 消失を検知し、この時間内に
フラッシュ → Close → リネームを完了させる（契約の詳細は §4.7）。
ハードウェアのラッチは無く、ファームウェアが暴走しても電源は物理的に落ちる。

**3番ピンの負荷は 98µA のみ**（100k+22k）。信号線から電流は取らない。

### 電流見積り

| 負荷 | 電流 | 5V換算 |
|---|---|---|
| MCP25625 VDDA（送信時最大）| 70mA @5V | 70mA |
| Pico 本体 20mA / GPS 50mA / MCP25625 VDD・VIO 10mA / SD書込ピーク100mA | 180mA @3.3V | 132mA |
| **合計** | | **約202mA** |

U1 は 500mA 定格なので 2.5倍の余裕。3V3(OUT) の外部負荷は 160mA で推奨上限 300mA 内。

---

## 3. ネットリスト

### 3.1 電源

| ネット | 接続 |
|---|---|
| `V12_RAW` | J1.8, F1.1 |
| `V12_FUSED` | F1.2, D1.A |
| `V12P` | D1.K, D2.K, C2.1, R1.1, Q2.S, C13.2 |
| `V12_SW` | Q2.D, U4.VIN, U4.EN, C14.1 |
| `V5` | L1.2, C15.1, U4.FB, U2.VDDA, C5.1, C6.1, D3.A, R14.1 |
| `SW_5V` | U4.SW, L1.1, C16.1 |
| `BST_5V` | U4.BST, C16.2 |
| `VSYS` | D3.K, U3.VSYS |
| `V3V3` | U3.3V3OUT, U2.VIO, C3.1, U2.VDD, C4.1, J2.VDD, C10.1, C11.1, J3.VCC, R6.2, R7.2, R10.2, R11.2, R12.2, R13.2 |

**GND**: J1.4, D2.A, C2.2, C3.2, C4.2, C5.2, C6.2, C7.2, C8.2,
C10.2, C11.2, C14.2, C15.2, U2.GND, U2.VSS, R4.2, Q1.E, U4.GND,
U3.GND1〜GND7, U3.AGND, J2.VSS, **J2.TR**, J2.L1, J2.L2, J2.L3, J2.BR, J3.GND

### 3.2 高側スイッチ／IG検出

| ネット | 接続 |
|---|---|
| `IG_RAW` | J1.3, R3.1 |
| `Q1_B` | R3.2, R4.1, Q1.B, R15.1 |
| `IG_SENSE` | R15.2, U3.GP28_ADC2 |
| `Q2_G` | R1.2, R2.1, Q2.G, C13.1 |
| `Q1_C` | R2.2, Q1.C |

### 3.3 CAN

| ネット | 接続 |
|---|---|
| `CANH` | J1.6, U2.CANH, R8.1 |
| `CANL` | J1.5, U2.CANL, R8.2 |
| `TXCAN` | U2.TXCAN, U2.TXD |
| `RXCAN` | U2.RXCAN, U2.RXD |
| `CAN_SCK` | U3.GP10, U2.SCK |
| `CAN_MOSI` | U3.GP11, U2.SI |
| `CAN_MISO` | U3.GP12, U2.SO |
| `CAN_CS` | U3.GP13, U2.CS |
| `CAN_INT` | U3.GP9, U2.INT |
| `CAN_STBY` | U3.GP20, U2.STBY |
| `CAN_RESET` | U3.GP21, U2.RESET, R6.1 |
| `XTAL1` | U2.OSC1, Y1.1, C7.1 |
| `XTAL2` | U2.OSC2, Y1.2, C8.1 |
| `TXNRTS` | U2.TX0RTS, U2.TX1RTS, U2.TX2RTS, R7.1 |

`TXCAN`/`RXCAN` はコントローラ部とトランシーバ部を基板上で繋ぐ配線。**忘れると一切通信できない。**

`TXNRTS` は未使用の入力3本を1本のプルアップにまとめたもの。MCP25625 の TxnRTS は
入力専用なので短絡の危険はないが、抵抗1本を介して誤設定時の保護を残している。

### 3.4 MicroSD

| ネット | 接続 |
|---|---|
| `SD_CS` | U3.GP5, J2.CD_DAT3, R10.1 |
| `SD_MOSI` | U3.GP3, J2.CMD |
| `SD_SCK` | U3.GP2, J2.CLK |
| `SD_MISO` | U3.GP4, J2.DAT0, R11.1 |
| `SD_DAT12` | J2.DAT1, J2.DAT2, R12.1 |
| `SD_CD` | U3.GP7, **J2.TL**, R13.1 |

`SD_MOSI` のプルアップは削除（MCU が常時駆動するため不要）。
`SD_DAT12` は SPI で未使用の2本を1本のプルアップにまとめたもの。

**カード検出は J2.TL（KiCad 公式フットプリントのパッド 9）。確定済み。**
当初は TR/BR を検出スイッチと推定していたが誤りだった。KiCad 公式の
`microSD_HC_Hirose_DM3AT-SF-PEJM5` フットプリントと自作フットプリントは
14パッド中13パッドが 0.001mm 単位で一致し、公式側は検出スイッチ対を
パッド 9・10 と番号付けしている（本書の TL・L2 に対応）。
シンボル `Connector:Micro_SD_Card_Det_Hirose_DM3AT` も pin 9 = `DET_B`、
pin 10 = `DET_A` と明示しており、2つの独立した資料で裏付けが取れた。
TR・L1・L3・BR はカバーの GND 脚。

旧版はスイッチの両端（TL と L2）をともに GND に落とし、検出信号を GND 脚である
TR から取っていたため、**カードの有無に関わらず「挿入済み」と読める状態だった。**

### 3.5 GPS・表示（LED 1個）

| ネット | 接続 |
|---|---|
| `GPS_RX` | U3.GP1, **J3 パッド4**（GPS モジュールの **TXD** を繋ぐ）|
| `GPS_TX` | U3.GP0, **J3 パッド3**（GPS モジュールの **RXD** を繋ぐ）|
| `GPS_PPS` | U3.GP6, J3 パッド5 |
| `LED_A` | R14.2, D6.A |
| `LED_STATUS` | D6.K, U3.GP8 |

### J3 の結線（実機で確定、2026-08-14）

GT-502MGG-N は 1.5m のバラ5線で出ている。**線色はデータシートに記載が無く、実機で確定した。**

| J3 パッド | シルク | ネット | Pico | 繋ぐ線 | 色 | 向き |
|---|---|---|---|---|---|---|
| 1 | V | `V3V3` | 3V3(OUT) | VCC | **赤** | — |
| 2 | G | `GND` | GND | GND | **黒** | — |
| 3 | R | `GPS_TX` | GP0 (UART0 TX)＜v4.1。旧 GP16＞ | **RXD** | **緑** | Pico → モジュール |
| 4 | T | `GPS_RX` | GP1 (UART0 RX)＜v4.1。旧 GP17＞ | **TXD** | **オレンジ** | モジュール → Pico |
| 5 | P | `GPS_PPS` | GP6＜v4.1。旧 GP18＞ | PPS | **茶** | モジュール → Pico |

> **v4 でシルクをモジュール側の名前に改めた（並びは V G R T P）。**
> `R` にはモジュールの RXD（緑）、`T` にはモジュールの TXD（オレンジ）と、
> **線のラベルとシルクが一致する**ように直読みで配線できる。
> v1 のシルクは基板側視点（パッド3=T / パッド4=R）で、「TXD（オレンジ）を T に」と
> 読んで出力どうしが衝突する誤配線が実際に発生した（2026-08-14）。
> ネットの割当自体は v1 から正しい。

**LED は 5V からのローサイド駆動。GPIO を Low にして点灯（論理反転）。**
3.3V では緑の VF（typ 3.0V）に対し余裕が 0.3V しかなく成立しない。

**表示は緑1個のみ。** エラーや状態の区別は点滅パターンで表現する
（例: 常時点灯=ログ中、1Hz点滅=GPS未測位、高速点滅=SDエラー）。
赤LED（D7）と R15 は削除し、GP5 は予備に戻した。

### 3.6 未接続（意図的）

| 部品 | ピン | 理由 |
|---|---|---|
| J1 | 1, 2, 7 | 車両側で未使用 |
| U2 | 2, 25 (NC) | メーカー指定の未接続ピン |
| U2 | 11 Rx1BF, 12 Rx0BF, 22 CLKOUT | 出力。SPIで代替可能なため開放（出力なのでフローティング可）|
| U3 | GP14〜GP19, GP22, GP26, GP27 | 予備（v4.1 で再割当後）|
| U3 | RUN, ADC_VREF, 3V3_EN, VBUS | 未使用 |

**U2 の TxnRTS は入力なので開放禁止**（R7 でプルアップ）。Rx0BF/Rx1BF は出力なので開放可。

**ADC_VREF は未接続で正常。** Pico 基板上でフィルタ済み 3V3 に内部接続されている。

回路図には未接続 21ピンすべてに No-Connect を明示してある（ERC 通過済み）。

### 3.7 Pico GPIO 割当（v4.1）

**基板配置に合わせて割り当ててある。** 論理的な整理で決めた当初案は物理配置の逆で、
CAN の SPI が microSD 側の端に載って配線不能になった（v1 で距離基準に再割当して解決）。
**v4.1 で Pico を 180° 回転**したため各ピンが対角位置（ピン k ↔ k+20）へ移り、
同じ距離基準で全面的に再割当した。**SPI0 と SPI1 の役割交換**
（SD=SPI0、CAN=SPI1）が、回転後の位置で合法かつ最近傍になる組み合わせの鍵。

| ブロック | ヘッダピン | GPIO | ペリフェラル |
|---|---|---|---|
| microSD（右列、J2 接点の真横）| 4,5,6,7 | GP2〜GP5 | **SPI0** SCK/TX/RX/CSn |
| 　同上 | 10 | GP7 | CD |
| CAN（右列、U2 の脇）| 14,15,16,17 | GP10〜GP13 | **SPI1** SCK/TX/RX/CSn |
| 　同上 | 12 | GP9 | INT |
| 　同上（左列、U2 の反対フランク）| 26,27 | GP20, GP21 | STBY / RESET |
| GPS（右列最下段、J3 の直上）| 1,2 | GP0, GP1 | **UART0** TX/RX |
| 　同上 | 9 | GP6 | PPS |
| LED（右列）| 11 | GP8 | GPIO（ローサイド、Low で点灯）|
| IG 検知（左列）| 34 | GP28 | **ADC2**（v4.1 でも不変。デジタル入力では読めない — §4.7）|

**ファームウェアはこの割当に従うこと。** v4 以前のファームからの差分:
SD が SPI1→**SPI0**、CAN が SPI0→**SPI1** に入れ替わり、UART0 が GP16/17→**GP0/1**、
CD/INT/STBY/RESET/PPS/LED の GPIO 番号も上表に変更。**GP28 の ADC 設定だけは無変更。**
基板側の検査: `mrp_brd.py` がビルド毎に全 17 ピンの「パッド→ネット」対応・
GND 8 穴・USB 端の向きを assert している。

---

## 4. 削除した部品と理由

| 旧記号 | 部品 | 削除理由 |
|---|---|---|
| L1, C3, C4, D3 | 100µH、220µF、100nF、SS34 | M78AR05 が内蔵 |
| U2, C7, C8 | AMS1117-3.3 と入出力容量 | GPS を Pico の 3V3 から供給 |
| Q1, R1, R2, R3, D4, R9 | ラッチング電源（BAT54C 等）| IG 直結スイッチに変更 |
| R6, R7, R8, D8, C6 | 12V センス2系統目 | IG ライン電圧の1系統に統合 |
| D12 | 5.6V ツェナー | M78AR05 が短絡保護・サーマルシャットダウン・1A出力制限を内蔵 |
| C1 | 22µF/50V 電解 | ユーザー判断で削除。入力上限が32V→28Vになるため D2 を SMAJ16A に変更 |
| D13 | 12V ツェナー | Q2 ゲートを 100k/100k 分圧にして Vgs を電源の1/2に制限 |
| R12, R13 | TxnRTS プルアップ2本 | 3ピンを1本のプルアップに統合 |
| R16, R18 | SD の CMD と DAT1/DAT2 プルアップ | CMD は不要、DAT1/DAT2 は1本に統合 |
| R9, C9, JP1 | CAN スプリット終端（60Ω×2 + 4.7nF + 切離しジャンパ）| ユーザー判断で 120Ω 1本に簡素化 |
| D5 | PESD1CAN（CAN用TVS）| ユーザー判断で削除。**結線も誤っていた**（下記）|

### D5 の結線誤り（削除により解消）

Nexperia データシート Rev.04 の Table 2 では、PESD1CAN の
**pin 3 が common cathode**、pin 1・2 が保護対象ラインである
（特性表の脚注も "Measured from pin 1 to 3 or 2 to 3"、Fig 8 の応用回路も
CANH→1・CANL→2・3→SPLIT）。

旧設計は **pin 2 を GND、pin 3 を CANL** に繋いでいた。共通端子とライン端子が
入れ替わっており、CANH–CANL 間に保護素子が直列に入って GND へ抜ける経路が無い状態だった。
部品ごと削除したため、この誤りは解消している。

### D1/D3 の型番とパッケージの不整合（B5819W に変更して解消）

**SS14 は SMA（DO-214AC）にしか存在しない。** 基板のランドは SOD-123 なので、
旧記述の「SS14 または B140」のうち SS14 を発注すると物理的に載らなかった。
JLCPCB の在庫も SS14 は SMA のみ（C2480）。

**B5819W（LCSC C8598）に変更した。** 40V / 1A の SOD-123 で、旧記述の要求
「1A/40V・SOD-123」をそのまま満たす。順方向電圧は 1A で 0.6V max、実使用の
約100mA では 0.3V 程度なので、クランキング時の電圧降下の見積り（下記「残課題」）は
変わらない。JLCPCB の Basic 部品でもあるため、フィーダー費も不要になる。

### チップ部品を全数 1005 → 1608 に変更

きっかけは C2 の耐圧だった。C2 は V12P に載って D2 のクランプ電圧 26V まで上がるが、
JLCPCB の Basic 部品にある 100nF 0402 は **16V 品しかない**。
当初は C2 だけ 1608 に上げて対処した。

その後、**チップ21点すべてを 1608 にしても成立するか**を実測して確認し、採用した
（詳細は [study-1608-chips.md](study-1608-chips.md)）。

| | 1005 | **1608（採用）** |
|---|---|---|
| チップ合計占有面積 | 37.8mm² | 91.0mm² |
| 板サイズ | 21×61mm | **変わらず** |
| 未配線 / DRC / 未接続 | 0 / 0 / 0 | **0 / 0 / 0** |
| デカップリング距離 合計 | 101.0mm | **84.7mm** |

面積が2.4倍になってもレイアウトは成立し、**バイパスコンデンサはむしろ IC に近くなった**。
加えて 100nF が全数 50V になり、手はんだ・リワークも容易になる。
C2 だけを例外扱いする処理は不要になった。

### JP1 の機能不全（削除により解消）

旧記述では「CAN終端の切離し。既定は閉」としていたが、実回路では JP1 は C9 と直列に
入っているだけで、開いても R8+R9 の 120Ω はバス間に残った。文書どおりの機能を持っていなかった。

---

## 4.5 JLCPCB 実装用の部品区分

実装を依頼するのは**表面実装 34点のみ**。スルーホールの
**J1・U1・U3・Y1** は手付けで、`fab/MotoRecoPico-bom-tht.csv` に分けてある。

| 区分 | 点数 | 部品 |
|---|---|---|
| **Basic**（フィーダー費 $0）| 26 | 抵抗13点、コンデンサ10点（全て 1608）、Q1、**D1/D3** |
| **Extended**（$3/点）| 6 | D2、D4、F1、J2、Q2、U2 |
| **JLC 在庫なし** | 2 | D6（サイドビューLED）、J3（GPSモジュール）— 手付けまたは支給 |

**1608 化で C2 が Extended から Basic に移った**（1608 の 100nF は 50V が Basic）。

Basic 品の LCSC 番号（すべて 0603 / 1608）:

| 値 | LCSC |
|---|---|
| 100kΩ | C25803 |
| 22kΩ | C31850 |
| 10kΩ | C25804 |
| 120Ω | C22787 |
| 1kΩ | C21190 |
| 100nF 50V | C14663 |
| 22pF 50V | C1653 |
| 10µF 10V | C19702 |
| MMBT3904 | C20526 |
| B5819W | C8598 |

**Basic 化できなかったものの理由**

| 部品 | 理由 |
|---|---|
| Q2 | Basic の Pch は AO3401A（SOT-23-3 / 30V / **Vgs ±12V**）。ゲートは 100k/100k 分圧で Vgs = V12P/2 なので、D2 クランプ時 **13V となり定格超過**。パッケージも違う |
| U2 | Basic には MCP2515（SOIC-18）+ TJA1051（SOIC-8）の2チップ構成しかない。SOIC-18 は 300mil 幅で**基板を10mm前後伸ばす**必要があり、$3 のために再設計する価値がない。MCP25625-E/SS（**C184944**）は Extended で在庫あり |
| D2 | Basic の TVS は P6SMB6.8CA（SMB / 6.8V）のみ。16V スタンドオフの SMA 品なし |
| D4 | Basic は ZMM3V3（**LL-34 MELF**）のみ。SOD-123 のツェナーなし。LL-34 に変えれば Basic 化可能 |
| F1・J2 | Basic にリセッタブルヒューズもコネクタも**1点もない** |
| ~~C2~~ | 全チップの 1608 化で Basic に移動。**解消済み** |

照合に使った Basic リストはコミュニティ公開のスナップショット（691点）で、
JLC 現行の「Basic & Promotional Extended」は 1,586点。
上記 Extended の一部は現在フィーダー費が無料になっている可能性があるため、
発注画面でバッジを確認すること。

---

## 4.6 v2 改訂の記録（2026-08-08）

v1 実基板の手はんだ実装を受けた2点の変更と、それに伴う再検証。

### IG 電圧センシングの廃止

Pico の ADC（GP28）による IG ライン電圧測定をやめた。削除したのは
**ADC のためだけに存在していた部品**: D4（ADC 保護ツェナー）、C12（ADC フィルタ）、
R5（ADC タップと Q1 ベースの分離抵抗）。

**IG 検出スイッチ（キーONで電源投入）は存続。** Q1 のベースは R3/R4 の分圧点に直結した:
- R3（100k）がベース電流を制限（IG は TVS 非搭載の線だが、100V サージでもベースへは 1mA 未満）
- R4（22k）が IG 浮遊時にベースを GND へ落とす
- 14V 時のベース駆動 約100µA に対し、Q2 ゲート負荷は約70µA。hFE 3 以上で飽和し、
  MMBT3904（hFE 30〜300）に対し余裕2桁

**失った機能**: 電圧ログと、充電電圧低下（14.4V→12.6V）によるエンジン停止検知。
キーOFF 前のログ閉鎖はバス情報か逐次フラッシュ設計で担保すること（§2 参照）。

### GND パッドのサーマル接続化

v1 は全 GND パッドがベタ直結で、手はんだ時に熱がプレーンへ逃げて作業性が悪かった
（設計時に想定し文書化していたトレードオフだが、実基板で許容できないと判断）。
v2 は**全ゾーンをサーマル接続（スポーク 0.4mm / ギャップ 0.3mm、最小スポーク数 1）**にした。

スポーク 0.4mm の許容電流はこの基板の最大ピン電流（約200mA）に対し十分。

### 2層化の試行と不成立

部品が3点減ったため 2層で成立するか実測で確認した。結果は**不成立**。

| 条件 | 結果 |
|---|---|
| 2層 / 0.15mm | 未配線3本（CAN_SCK・CAN_MOSI・LED_A、20回全て）|
| 2層 / 0.127mm（工程下限）| **配線は全数通る**が、GND のサーマルスポークが届かないパッドが**2〜6点**残る（5シード × ギャップ 0.3/0.25/0.2 の全組合せ）|
| **4層 / 0.15mm** | **1回目で成立**。違反0・未接続0・浮き銅片0 |

2層でスポークが届かないのは、外層ベタが配線で細切れになりパッド周囲に銅が残らないため。
v1 で「サーマルにすると Pico の GND ピンが繋がらない」と記録した問題そのもので、
部品を減らしても解消しなかった。**ベタ直結に戻せば 2層は成立する**が、
今回の変更目的（手はんだ性）と矛盾するため採らず、4層を継続する。

なお配置起因の教訓を1件追加: R5 削除後、分圧の R3/R4 が自動配置で行を跨いで離れ、
その2パッド間（Q1_B）だけが 20回全てで配線不能になった。ゾーン内の詰め順を
`R1,R3,R4,R2` に変えて隣接させることで解消（`mrp_brd.py` にコメントあり）。

---

## 4.7 v3 改訂の記録（2026-08-09）

### IGN OFF 遅延（ソフト電源OFF）

v2 では IG OFF から数ミリ秒で断電し、ログを閉じる猶予が無かった。
v3 は2部品で「**保証0.4秒・典型0.5秒**」の猶予を作る。

**C13（10µF/25V、Q2 の G–S 間 = R1 と完全並列）**
IG OFF で Q1 が切れた後、ゲートは R1(100k) 経由でしか放電できない。
Vgs は −7V から τ = R1×C13 で減衰し、|Vgs| > 3.5V の間 Q2 は導通を保つ。
MLCC の DC バイアス減衰（実効 6〜7µF）込みで t = 0.69τ ≈ **0.4〜0.5s**。

| 副作用 | 評価 |
|---|---|
| 電源ON遅延 ≈ 0.2〜0.3s | 起動シーケンスに埋没。実害なし |
| キー接点チャタリング | RC が吸収（改善）|
| Q2 のリニア領域通過 | 遷移時 ≤1W を 0.1〜0.3s。SOT-26 の過渡熱で許容 |

**フェイルセーフ**: ラッチング電源と違い、ファームウェアが暴走しても物理的に断電する。
電池を空にするモードが存在しない。

**R15（10k、Q1 ベースノード → GP28）**
Q1 のベースは自身の B-E 接合で**常に約0.7V 以下にクランプ**される
（サージも R3 100k が制限）ため、ツェナー・分圧・フィルタが一切不要。
IG ON で約0.65V、OFF で 0V。

> **必ず ADC で読むこと（閾値 0.35V 推奨）。** 0.7V は VIH（約2V）未満なので
> デジタル入力では読めない。読めるのは ON/OFF のみで、v1 の電池電圧ロギングは戻らない。

### ファームウェア契約

1. GP28 (ADC2) を **50ms 以下の周期**でポーリング
2. 0.35V を下回ったら: フラッシュ → Close → リネーム → アイドル
3. 使える時間は**保証 0.4秒**（SD の書き込みストール最悪値 〜250ms 込みで収まる）
4. 猶予を伸ばす場合は C13 を並列追加（10µF ごとに約 +0.4s）。**R1 は変えない**
   （Vgs 分圧比が崩れ、ロードダンプ時のゲートが ±20V 定格に近づく）

### C7/C8 を Y1 の直近へ移設

v2 の実測で C7/C8 が水晶から 11.1 / 9.0mm 離れ、**XTAL1 が In1（GND プレーン層）の
中を 8.5mm 通っていた**。機能上は許容（周波数偏差は数十ppm、CAN 許容の 1/100）だが、
16MHz の恒常アグレッサがプレーンに溝を掘る形は EMI 上筋が悪い。

Y1 はスルーホールで表面にもランドがあるため、表面の Y1 両バレルの左右
（x13.15 / x16.85）に**明示配置**した。結果:

| | v2 | **v3** |
|---|---|---|
| C7 ↔ Y1 | 11.12mm | **2.24mm** |
| C8 ↔ Y1 | 8.96mm | **2.77mm** |
| XTAL1 | 21.2mm・内層 8.5mm | **9.7mm・ビア0・内層0** |
| XTAL2 | 17.1mm・ビア1 | 10.5mm・ビア1・内層0 |

ゾーン任せでは C6 のスピルに枠を奪われ2回失敗したため、EXPLICIT 配置にしてある
（`mrp_brd.py` 参照。C8 は回転 270° — 90° だとピン1が遠い側を向き 4.1mm になる）。

### C6・C11 の表面移動（1608 の片面集約）

裏面に残っていた 1608 の2点を表面ゾーンへ編入し、**1608 チップ 23点が全数表面**になった。
「チップ全数表面」の自動検査も C1608 まで拡大済み。裏面は SOT/SOD/SMA/THT のみ。

| | v2 | v3 |
|---|---|---|
| C6 ↔ U2.VDDA | 11.52mm（裏面・ビア経由）| **3.85mm（同一面）** |
| C11 ↔ J2.VDD | 4.55mm(裏面・ビア経由) | 7.36mm（同一面）|

C11 は数値上悪化したが、SD の高周波分は C10（4.74mm）と In2 の 3V3 プレーンが受け持ち、
バルクの 10µF は数mm の差に鈍感なので許容した。

---

## 4.8 v3.1: Q2 フットプリントの G/S 鏡像不具合の修正（2026-08-13）

**v1〜v3 のすべてで、Q2（ZXMP6A17E6Q）のパッド対応が実部品と鏡像になっていた。**
EAGLE ライブラリ作成時に混入した誤りで、v1 実基板のベンチ試験で発覚した。

### データシートとの照合

Diodes DS36685 Rev 3-2 p.1「Pin Out - Top View」（2026-08-13 に PDF を直接検証）:

| ピン | 1 | 2 | **3** | **4** | 5 | 6 |
|---|---|---|---|---|---|---|
| 実部品 | D | D | **G** | **S** | D | D |
| 旧ライブラリ（誤）| G | D | D | D | D | S |

G/S ペアの位置が鏡像のため、**実部品をどの向きで載せても成立しない**:

| 取り付け向き | 何が起きるか | ベンチでの症状 |
|---|---|---|
| 向きA | 共通ドレイン金属が V12P・V12_SW・Q2_G を短絡 | **IG と無関係に V12_SW = 13.8V（常時ON）** |
| 向きB（Aの180°）| G が V12P、S が分圧ノードに載り FET は永久 OFF | **V12_SW が一切上がらない** |

両症状とも v1 基板で実測され、この照合で根本原因が確定した。

### 修正内容（v3.1）

- `mrp_design.py` の PADMAP に SOT26 の振替を追加（G→3、S→4、D→1,2,5,6）
- カスタムシンボル `MotoRecoPico:ZXMP6A17E6Q` のピン番号を同じ対応に振り直し
- `mrp_brd.py` に**恒久検査**を追加: Q2 のパッド→ネット対応がデータシートと
  一致しなければビルドが失敗する
- 再配線・全検証済み（DRC 0/0、38ネット一致、XTAL 内層0、C7/C8 ≤2.8mm 維持）。
  副産物として 12V チェーンが 13.81 → **12.53mm** に短縮（S パッドが D1 側に移ったため）

### v1 実基板の応急処置（記録）

G/S の2本だけ入れ替えれば成立する。マーキング読める向き（ドット左下）で**右端の2本**が
G（手前）/S（奥）。この端を U1 側に向けて D の4本を通常はんだ、G/S の2本は足を浮かせ、
部品S → V12P パッド（D1 カソードと導通が鳴る側）、部品G → もう一方のパッドへ
クロスジャンパ。動作確認: IG ON/OFF で Q2_G が 7V ⇔ 13.8V、V12_SW が 13.8V ⇔ 0V。

## 4.9 v4 改訂の記録（2026-08-14）

### 5V 電源の小型化: M78AR05 → AP63205WU-7

U1（SIP-3、高さ10.2mm、定格500mA）は負荷 約200mA に対して過大で、基板2番目の背高部品だった。
AP63205WU-7（TSOT-26、3.8〜32V→5V固定、2A同期整流、1.1MHz、スペクトラム拡散EMI対策、Iq 22µA）
＋ L1/C14/C15/C16 に置換。**ピン配置（1=FB 2=EN 3=VIN 4=GND 5=SW 6=BST）は KiCad 公式
シンボルと DS41326 p.1 の両方で照合**（Q2 の教訓）。ビルド毎の自動検査も追加済み。

| 実測 | 値 |
|---|---|
| SW ノード（U4.5↔L1.1）| 2.09mm |
| 入力コンデンサ（U4.3↔C14.1）| 3.04mm |
| ブートストラップ（U4.6↔C16.2）| 4.00mm |
| 12V チェーン合計 | 14.83mm |

**最低入力 3.8V** により、クランキング時リセットの残課題が構造的に解消。
入力上限 32V はクランプ 26V に対し余裕 6V。

### J1 の表面実装化

車両カプラの差し込みを基板の反対側（Pico 側）に変更。MQS の千鳥格子は左右非対称のため、
面反転で**穴パターンごと鏡像化**した（12V 入口が x17.5 → x3.5 に移動）。
これに伴い電源列（F1→D1→Q2→バック）も左右鏡像に組み替え、流れ順を維持した。
ピン→ネット対応はフットプリントに追従するため自動的に正しい。
**筐体の前提が反転**: 表面 = J1 18.1mm + Pico、裏面 = 最背 3mm。

### GPS シルクの T/R 修正

v1 のシルクは パッド3=T / パッド4=R だったが、パッド3には Pico の UART TX が配線されており、
モジュール視点では R（モジュールの RXD 線を繋ぐ）が正しい。実機での配線時に発覚。
mrp_fp.py の生成文字列を "VGTRP" → "VGRTP" に修正した。

### 配線シードの XTAL ガード

v4 の再配線で、シードによっては XTAL2 が In1（GND プレーン）内を 5〜7mm 通ることが判明。
xtal_check.py を新設し、**シード選定ループが「XTAL 両ネット内層0・ビア≤1」を
満たさない解を自動棄却**するようにした（try_thermal.ps1 に組込み）。

---

## 4.10 v4.1 改訂の記録（2026-08-14）

**変更は Pico の向きと GPIO 割当のみ。部品構成・定数・穴位置は完全に不変。**

### Pico の 180° 回転（面はそのまま）

v4 で J1 が表面に来た結果、Pico の USB コネクタが 18.1mm の MQS ハウジングの
0.6mm 隣（y=0 側）を向き、USB ケーブルが挿せなかった。ユーザー要望により
表裏は変えず上下 180° 回転し、**USB を microSD・LED と同じ y=61 端**へ向けた。

回転が安価に済む理由（2つの対称性）:
- 2×20 ヘッダー格子は 180° 回転対称 → **穴は1つも動かない**（v4 ドリルファイルと
  座標一致を確認済み）。各穴に入るピンが対角（k ↔ k+20）に入れ替わるだけ
- GND ピン（3/8/13/18 ↔ 23/28/33/38）は対称位置どうしが共に GND →
  全 GND バレルの役割も不変

### GPIO の再割当（ファームウェア変更が必要）

ピン位置が全て裏返るため、v1 と同じ「距離＋RP2350 ピン多重化の合法性」基準で
再導出した。**SPI0 ↔ SPI1 の役割交換**が、回転後の位置で最近傍かつ合法になる鍵。
正規の対応表は §3.7。要点: **SD=SPI0 (GP2〜5)、CAN=SPI1 (GP10〜13)、
GPS=UART0 (GP0/1)、IG_SENSE=GP28 (ADC2) は不変。**
`mrp_brd.py` がビルド毎に USB 端の向き・GND 8穴・全17ペリフェラルピンを assert する。

### スティッチングビアの moat 規則（副産物の恒久修正）

回転後、3V3 ピン（パッド36、In2 プレーンから給電される唯一の穴）が J2 の
GND パッド近傍圏に入り、1mm 格子の GND スティッチングビアに四方を包囲されて
**In2 のサーマルスポークが全方向で塞がれ、全8シードで未接続1**という決定論的
失敗になった。gnd_stitch.py に「**ネットを持つ非 GND のスルーホールから 2.2mm
以内にはステッチを置かない**」moat 規則を追加して解消。以後の全リビジョンに効く。

### 検証結果

- Freerouting 全数配線、DRC 違反0・未接続0（seed 3、サーマルギャップ 0.3mm）
- compare_net 40/40 一致（回路図はネット定義から自動追従）
- XTAL1 10.2mm（ビア0・内層0）/ XTAL2 10.4mm（ビア1・内層0）、C7 2.24 / C8 2.77mm 維持
- In1 GND プレーン 1領域 100%（992.3mm²）、In2 3V3 プレーン 1領域、浮き銅0
- 電源チェーン 14.83mm・バックループ各距離は v4 と同値（部品無変更）
- 317トラック / ビア186本（うち GND 149本）

### 組立後の受入チェック（v4.1 実基板、2026-08-14）

初回通電で **IG 開放のまま 5V が出た**。Q2 のゲート（パッド3）を GND 基準で測ると 0V。
原因は **Q2 ゲートリードの未はんだ（浮き）**。PMOS はゲートが浮くと漏れ電流と
容量結合で ON 側に寄り、テスターの入力抵抗が浮いたリードを 0V に引いて見えていた
（パッド側は R1 経由で V12P）。再はんだで正常化。

設計で検出できない組立不良なので、完成後は必ず次を確認する:

| 条件 | 期待値 |
|---|---|
| IG 開放、V12_RAW=12V | Q2 ゲート＝ソース（≈ V12P、差 0.1V 以内）、**V12_SW ≈ 0V、5V 出ない** |
| IG に 12V | Q2 ゲート ≈ V12P/2、V12_SW ≈ V12P、5V 出る |
| IG を切る | 0.4〜0.5s 後に 5V が落ちる（C13 の遅延） |

ゲートが 0V まで落ちている場合は短絡ではなく**ゲート浮き**もまず疑うこと
（Q1 完全短絡でも R1/R2 分圧で V12P/2 止まりで、0V にはならない）。

---

## 4.11 v4.2 改訂の記録（2026-08-23）

**v4.1 実基板の手はんだ経験を受けた改訂。部品・定数・ネット・GPIO 割当は完全に不変。**

### Pico を裏面へ

面反転はフットプリントを x=10.5 で鏡像化するだけなので、**穴は1つも動かず**、
ピン1〜20 の列が左（x=1.61）、21〜40 が右に入れ替わる。v4.1 の GPIO 割当は
y 方向の近さで選んであり（U2 も J2 も x 対称）、鏡像でも距離関係は保たれるため
**再割当なし＝ファームウェア変更なし**。USB は引き続き y=61 端。
GPS（J3、裏面右 x15）だけは GP0/1 が左列に移って約 13mm 離れるが、9600bps の
UART 3本で問題にならず、J3 を動かすより配線の左レーンを空けておく方を優先した。

効果: 表面は J1 以外すべて低背部品（U2・J2・1608 チップ 23点）になり、
**実装・リワーク・プロービングが Pico を外さずにできる**。
裏面の電源ポケット・Y1・J3 は Pico の下（ソケット高 8.5mm）に入る。
**J3 の GPS 配線はんだ付けは Pico を抜いて行う**こと。

### Q2 の手はんだ用ランド

v4.1 の SOT-23-6 標準ランド（1.3×0.6mm）はパッドが短く、ゲートリードの未はんだ
（§4.10 受入チェック）を招いた。**U4 と同一の TSOT-23-6_HandSoldering
（2.0×0.65mm、外側に 0.6mm 長い）** に変更。幅 6mm になり F1/D1 の列に
収まらないため、右列に 90° 立てて配置（S/G が D1 側の列、ドレインが基板端側）。
パッド番号は JEDEC 順のまま → `PADMAP['SOT26']` と **G=3 / S=4 のビルド毎 assert はそのまま有効**。

### L1 の自作ランド

ASPI-4030S の標準ランド（1.1×3.4mm、外縁 2.05）は 4×4 本体の外に銅箔がほぼ無く、
U4 の SW パッドとも近接していた。`mrp_fp.py` で**各パッドを外側へ 1.0mm 延長**
（2.1×3.4mm、外縁 3.05）した `L_4030_HandSolder` を生成し、**90° 回転**して
パッドが ±y を向くようにした。SW 側パッドは U4 の SW 列の横（4.1mm）、V5 側は
その下の C15 に直結（3.1mm）。

### 裏面ポケットの組み替え

Q2 の立て置きと L1 の回転で幅を取るため、U4 を 1mm 下げ、C14 を Q2 の下、
C16 を U4 の下、C15 を L1 の V5 パッド直下に並べ替え、D2・Q1・D3 のゾーンを
3〜4mm 下へずらした。配置は全て `mrp_brd.py` の EXPLICIT／ZONES に記録。

**R15 は CAN 終端バンドの左端（x≈3.2、Q1 の真裏）へ。** v4.1 では左列にあった GP28 に
寄せて x≈10〜12.8 に置いていたが、そこは U2.OSC2（10.8, 29.5）→ Y1.2（15.0, 32.6）の
直線上で、最初の 8 シードは XTAL2 が In1 プレーンに潜るか未配線が残るかで全滅した。
GP28 は面反転で右列（x19.39）に移り中央に置く理由が消えたので、左端へ退避して
XTAL2 の表面通路を空けた（IG_SENSE は DC の ADC 線なので基板を一度横切っても問題ない）。

**裏面左端の電源スタック（L1・C15・D2・Q1・D3）は Pico 左列パッドから 2.5mm 離す。**
面反転で CAN の SPI 4 本は**左列**（パッド14〜17、y17〜25）から出るのに、U2 の SPI ピンは
上段の**右端**（x≈13〜14.7）にある。表側は U2 上の 1608 デカップリング列が壁、裏側は
左端スタックが隙間 0.5mm の縦壁になり、Pico パッドとの間に 1.3mm しか残らず
**CAN_MISO が 20 シード中 19 で未配線**になった。スタック全体を 1.2mm 右へ寄せて
（L1 左端 x4.9、D2/Q1/D3 左端 x4.0）2.5mm のレーンを確保した。

| 区間 | v4.1 | **v4.2** |
|---|---|---|
| 電源チェーン合計（J1.8 → U4.VIN）| 14.83mm | 15.12mm |
| SW ノード（U4.SW ↔ L1）| 2.09mm | 3.99mm |
| 入力コンデンサ（U4.VIN ↔ C14）| 3.04mm | 2.90mm |
| 出力コンデンサ（L1 ↔ C15）| 4.10mm | 3.07mm |
| ブートストラップ（U4.BST ↔ C16）| 4.00mm | 4.03mm |

SW ノードは 2mm 伸びたが、1.1MHz・0.2A の用途では許容（パッドが広がった分、
はんだ付け品質のほうが効く）。

### 回路図の手配置レイアウトへの刷新（2026-08-26）

見づらさの指摘を受け、回路図の生成を `gen_ksch3.py`（1ブロック1列＋帯状自動配線）から
**`gen_ksch4.py`（全部品・全配線を手書き座標で配置）** に置き換えた。採った作法は
定石どおり: 信号は左→右（J1 → 電源部 → MCU → SD/GPS/LED）、電位は上→下
（12V レール上・GND シンボル下向き）、高側スイッチは縦描き、プルアップ・パスコンは
縦置き、ブロック内は実配線・ブロック間はラベル、電源シンボルの `#PWR` 参照名は非表示。
**結線の正しさはレイアウトに依存しない**: 生成毎に内部のショート/接続検査が走り、
さらに kicad-cli のネットリスト → compare_net で mrp_design.NETS と 40/40 一致、
ERC は既知の U3 ピンタイプ注記 1 件のみであることを確認済み。A3 1枚。

### 検証結果

- Freerouting 全数配線、DRC 違反0・未接続0（seed 8／12、サーマルギャップ 0.3mm。
  最初の 20 シードは R15 と左端スタックの問題で全滅 → 上記2点の修正後に成立）
- compare_net 40/40 一致、ERC は既知の U3 ピンタイプ注記 1 件のみ
- U3 の 40 穴の座標は v4 / v4.1 と完全一致（ドリルファイル比較）
- XTAL1 9.7mm（ビア0・内層0）/ XTAL2 14.6mm（**ビア0**・内層0）、C7 2.24 / C8 2.77mm 維持
- In1 GND プレーン 1領域 100%（972.2mm²）、In2 3V3 プレーン 1領域（881.1mm²）、浮き銅0
  （island_check にパッド接触判定を追加 — U3 パッド3 に繋がる 0.3mm² のスポーク断片を誤検出していた）
- 電源チェーン 15.12mm、SW 3.99 / 入力 2.90 / 出力 3.07 / BST 4.03mm
- 328トラック / ビア182本（うち GND 137本）。内層の信号: In1 158mm / In2 145mm
  （v4.1 の 120 / 50mm から増。Pico 裏面化で左右列の役割が入れ替わり、配線が厳しくなったぶん
  ルータが内層を使った。プレーンはどちらも 1 領域 100% で分断なし）
- 製造データ: BOM 38 SMT + 3 THT（J1・U3・Y1）、CPL 38、クロスチェック一致。
  **BOM は毎回回路図から再生成する**（fab_all.ps1）。手で追記した行（`Ver4.1`）は消えるので、
  JLC 用の注記は別ファイルに

---

## 5. 残課題

| 項目 | 内容 |
|---|---|
| 車両3番ピン | 98µA の負荷で問題ないか、車種の回路図で確認 |
| CAN 終端 | R8 の 120Ω は常時有効。既に終端されたバスに割り込むと通信不良の恐れ（上記「CAN 終端は常時有効」参照）|
| 負方向サージ | D1（B5819W）の逆耐圧は 40V。D2 は D1 の後ろにあり入力側の負サージを見ない。ISO 7637-2 相当まで見るなら D1 の高耐圧化か D2 の双方向化＋前置が必要 |

**判断済み**（リスクを認識したうえで現状のまま進めるもの）

| 項目 | 判断 |
|---|---|
| **F1 の耐圧 16V** | 1206 で 1.1A hold の PPTC は **16V が上限**（他は 6V・8V）。しかも F1 は **D2（TVS）より前段**（J1.8 → F1 → D1 → D2）にあり、車両側サージをクランプされずに直接受ける唯一の部品。24V/30V 品は 1812 などサイズアップが必要で基板変更を伴うため、**ユーザー判断で 16V のまま進める**（2026-07-31）。Littelfuse **1206L110/16WR** を想定 |

**解決済み**（旧・残課題）

| 項目 | 結果 |
|---|---|
| **J3 のシルク T / R** | **v4 で解消。** シルクをモジュール側視点（パッド3=R / パッド4=T、並び V G R T P）に改め、線のラベルと直読みで一致するようにした（3.5節参照）。v1 基板は基板側視点のため引き続き注意 |
| **GPS 線色** | 実機で確定（2026-08-14）。**赤=VCC / 黒=GND / オレンジ=TXD / 緑=RXD / 茶=PPS**。J3 への割当は 3.5節の表を参照 |
| **GPS のボーレート** | 実機で確定（2026-08-14）。**9600bps**。ファームの既定値どおり |
| クランキング時の電圧降下 | **v4 で解消。** AP63205 の最低入力は 3.8V。F1+D1 の約0.4V を引いても、電池が 4.2V まで落ちない限り 5V 系は動き続ける（〜5.6V 以下では出力が入力に追従）|
| DM3AT 補助パッドの役割 | KiCad 公式フットプリントとシンボルで確定。検出スイッチは TL・L2（公式のパッド 9・10）|
| DM3AT パターン禁止領域 | KiCad 公式フットプリントが禁止領域5個を保持しており、DRC で検証済み |
| ケース | v4.2 時点: 表面 = J1（18.1mm）のみ（U2・J2・1608 チップは露出）、裏面 = Pico（ソケット 8.5mm ＋ 本体、USB は y=61 端）とその下の部品（最背 3mm）。開口は y=61 端面に SD（表面）・USB（裏面）・LED を集約、y=0 端は MQS のみ |

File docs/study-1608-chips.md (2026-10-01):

# 検討: チップ部品を 1005 → 1608 にした場合

> **2026-07-31 採用済み。** 本書は判断の根拠を残すための記録。
> 現行設計はチップ21点すべてが 1608。`mrp_design.py` の既定が `CHIP='1608'`。

現行設計は 20点のチップ（抵抗13・コンデンサ7）を **1005（0402インチ）**で実装している。
これを **1608（0603インチ）**にしたときに成立するかを、実際にパイプラインを回して確認した。

**結論: 成立する。** 板サイズ 21×61mm のまま、全数配置・全数配線・DRC違反0・未接続0。
デカップリング距離はむしろ短くなる。

## 実測比較

| 項目 | 1005（現行） | **1608** |
|---|---|---|
| チップ点数 | 20 | 20 |
| 1点あたりキープアウト | 1.91 × 0.99 mm | 3.01 × 1.51 mm |
| 合計占有面積 | 37.8 mm² | **91.0 mm²**（+53.2） |
| 板サイズ | 21 × 61 mm | **21 × 61 mm**（変更なし） |
| 全数配置 | ○ | **○** |
| 未配線 | 0 | **0**（1回目で成立） |
| DRC 違反 / 未接続 | 0 / 0 | **0 / 0** |
| In1.Cu GND プレーン | 1領域 100% | 1領域 100% |
| 配線長 | 694 mm | 664 mm |
| ビア | 233 | 248 |
| ゾーンからのはみ出し | 2点 | 9点 |

## デカップリング距離（パッド間、同一ネット）

**面積が増えたのに、むしろ改善している。**
自動配置がパックし直した結果で、1608 の系統的な優位ではないが、少なくとも悪化しない。

| コンデンサ | 用途 | 1005 | **1608** |
|---|---|---|---|
| C3 | MCP25625 VIO | 8.88 mm | 8.69 mm |
| C4 | MCP25625 VDD | 5.80 mm | 4.45 mm |
| C5 | MCP25625 VDDA | 11.68 mm | **5.66 mm** |
| C6 | VDDA バルク（裏面） | 11.52 mm | 11.52 mm |
| C10 | microSD VDD | 8.18 mm | 6.50 mm |
| C11 | microSD バルク（裏面） | 4.55 mm | 4.55 mm |
| C7 | 水晶負荷（裏面 Y1） | 11.40 mm | 11.12 mm |
| C8 | 水晶負荷（裏面 Y1） | 9.90 mm | 8.96 mm |
| C12 | ADC フィルタ | 20.37 mm | **14.52 mm** |
| C2 | V12P バイパス | 8.74 mm | 8.74 mm |
| **合計** | | **101.01 mm** | **84.72 mm** |

なお「ゾーンからのはみ出し」は 2点 → 9点に増えるが、
これは自動配置が定義した矩形からどれだけ離れたかという内部指標にすぎず、
実際の電気的な距離は上表のとおり改善している。**この指標は誤解を招くため判断に使わないこと。**

## JLCPCB 部品区分への影響

**1608 化すると Basic 部品の状況が良くなる。**

| 値 | 1005 の Basic | 1608 の Basic |
|---|---|---|
| 100kΩ | C25741 | C25803 |
| 22kΩ | C25768 | C31850 |
| 10kΩ | C25744 | C25804 |
| 120Ω | C25079 | C22787 |
| 1kΩ | C11702 | C21190 |
| 22pF | C1555（50V） | C1653（50V） |
| **100nF** | C1525（**16V のみ**） | C14663（**50V**） |

全値が 1608 でも Basic にある。しかも **100nF が 50V になる**ため、
C2 のためだけに 1608 へ上げた例外処理（`mrp_design.py` の `PKG_OVERRIDE`）が不要になる。

## 手実装のしやすさ

1608 は 1.6 × 0.8mm、1005 は 1.0 × 0.5mm。面積で 2.4倍、辺長で 1.6倍。
**手はんだ・リワークの容易さは大きく違う。** JLCPCB に実装を任せる前提なら差は無いが、
自分で直す可能性を考えるなら 1608 が有利。

## 実施する場合の手順

`mrp_design.py` に環境変数のスイッチを入れてある。

```
MRP_CHIP=1608  →  R_0603_1608Metric / C_0603_1608Metric（既定）
MRP_CHIP=1005  →  R_0402_1005Metric / C_0402_1005Metric（比較用）
```

**実施済みの付随変更**

- `mrp_design.py` の C2 用 `PKG_OVERRIDE` は `CHIP=='1005'` のときだけ効くようにした
  （1608 なら全 100nF が 50V なので不要）
- `netlist.md` §1.3 / §1.4 / §4.5、`hardware-design.md` の記述を 1608 に更新
- `mrp_brd.py` の `eagle_pkg(r) == 'C1005'` は **EAGLE 側のパッケージ名**なのでそのまま。
  1608 に変わるのは KiCad フットプリントだけで、「チップは全数表面」の検査は生きている

## 採用後の実測値（1608 の最終盤面）

| 項目 | 値 |
|---|---|
| 未配線 | 0（1回目で成立）|
| DRC 違反 / 未接続 | 0 / 0 |
| 配線 | 329トラック / ビア251本（うち GND 207本）|
| 層別配線長 | F.Cu 232 / In1 158 / In2 108 / B.Cu 170 mm |
| In1.Cu GND プレーン | 1領域が100%（992.3mm² / 次点 3.0mm²）|
| 浮き銅片 | 0（全6領域） |
| 回路図とのネット一致 | 38/38 |
| 電源チェーン長 | 13.81mm（変化なし）|

---

## 検討中に判明した問題: 配線結果が再現しない

`mrp_brd.py` で基板を作り直すと、**ネット内のピンの並び順が変わる**。
KiCad の DSN 出力はパッドの内部順序をそのまま書き出しており、
その順序は毎回生成し直される UUID に依存するため。

同一の配置（38点すべて座標・回転・面が一致することを確認済み）から作った
2つの DSN はサイズこそ同じ 58,074 バイトだが、24行が異なり、その中身は
`(pins U3-19 R13-1 J2-9)` のようなピンの並びだけだった。

**この違いで Freerouting の結果が変わる。** 検証済みの盤面は1回目で未配線0だったが、
同じ配置を作り直したものは4回連続で SD_CS が2本残った。

対策として、**配線済みの基板ファイルそのものを成果物として保持すること**。
`mrp_brd.py` から作り直せば同じ結果になる、と考えてはいけない。
今回の検討でも一度上書きしてしまい、バックアップ
（`MotoRecoPico_backup_20260731-1400`）から復旧している。

---

*2026-07-31 実測。現行の出荷データは 1005 のまま変更していない。*

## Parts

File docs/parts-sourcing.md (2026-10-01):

# 部品調達先（全41点・手はんだ前提）

全部品を手はんだする前提の購入先一覧。リンクは**実在を確認したページのみ**記載する。
空欄は「そのベンダーで確認できなかった」という意味で、無いとは限らない。

designator は41点（v4）。値が同じものをまとめると **25品目**。
**v2 で R5・D4・C12 削除**、**v3 で C13/R15 追加**、**v4（2026-08-14）で U1（M78AR05）を廃止し U4/L1/C14/C15/C16 を追加**した。
D4 の行は既に買った在庫の記録として残す。

---

## 先に結論: 秋月＋マルツの2社で全部揃う

**マルツエレックは DigiKey の国内唯一の正規代理店**で、DigiKey 取扱いの
**600万点以上を1個から、DigiKey と同価格で**買える。送料は全国一律 ¥240
（**¥3,000 以上で無料**）、国内発送・国内決済。

つまり **下表の DigiKey 欄にあるものは、ほぼそのままマルツで買える**。
海外発注・国際送料・通関を避けたいなら、

> **秋月電子（国内在庫の安い部品）＋ マルツ（DigiKey 経由の海外部品）**

の2社で完結する。マルツの型番検索はこの形式:

```
https://www.marutsu.co.jp/GoodsListNavi.jsp?q=＜型番＞
```

マルツは[秋月電子通商の製品も一部取り扱っている](https://www.marutsu.co.jp/MakerCategoryList.jsp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)が、
品揃えは秋月本体に及ばない。

---

## 1. 抵抗（1608 / 0603、全13点・5品目）

| 値 | 使用箇所 | 秋月電子 | マルツ / Mouser / DigiKey |
|---|---|---|---|
| **100kΩ** ×3 | R1, R2, R3 | [1/10W 100個入（130357）](https://akizukidenshi.com/catalog/g/g130357/) | `RC0603FR-07100KL` 等 |
| **22kΩ** ×1 | R4 | ✗（小分けなし） | `RC0603FR-0722KL` 等 |
| **10kΩ** ×7 | R6, R7, R10-R13, **R15** | [1/10W 100個入（130355）](https://akizukidenshi.com/catalog/g/g130355/) | `RC0603FR-0710KL` 等 |
| **120Ω** ×1 | R8（CAN終端） | △ [5000個リール ¥980（130332）](https://akizukidenshi.com/catalog/g/g130332/) | `RC0603FR-07120RL` 等 |
| **1kΩ** ×1 | R14 | △ [5000個リール ¥980（114122）](https://akizukidenshi.com/catalog/g/g114122/) | `RC0603FR-071KL` 等 |

**秋月の1608小分けは 10kΩ と 100kΩ しか無い。** 22kΩ・120Ω・1kΩ は5000個リール（¥980）に
なるので、この3点はマルツで単品購入する方が現実的（Yageo RC0603 系が1本 ¥5〜10）。

どうしても秋月1社で済ませたいなら
[1608 チップ抵抗サンプルブック E24（115657）](https://akizukidenshi.com/catalog/g/g115657/)
が E24 全値 各50本入りで ¥8,900。5品目のためだけには高い。

## 2. コンデンサ（1608 / 0603、全10点・3品目）

| 値 | 使用箇所 | 秋月電子 | マルツ / Mouser / DigiKey |
|---|---|---|---|
| **100nF / 50V** ×5 | C2, C3, C4, C5, C10 | **[0.1µF 100V X7R（114559）](https://akizukidenshi.com/catalog/g/g114559/)** ← 推奨 | `CC0603KRX7R9BB104` 等 |
| | | [0.1µF 50V X8L（116143）](https://akizukidenshi.com/catalog/g/g116143/) も可 | |
| **22pF / 50V** ×2 | C7, C8（水晶負荷） | [22pF 50V CH 40個入（P-11626）](https://www.akizukidenshi.com/catalog/g/gP-11626/) | `CC0603JRNPO9BN220` 等 |
| **10µF** ×3 | C6（V5）, C11（3V3）, **C13（G–S間・要25V）** | [10µF 35V X5R（113161）](https://akizukidenshi.com/catalog/g/g113161/) / [10µF 16V X5R（117202）](https://akizukidenshi.com/catalog/g/g117202/) | [GRM188R61E106KA73D（Mouser）](https://www.mouser.com/ProductDetail/Murata-Electronics/GRM188R61E106KA73D?qs=5aG0NVq1C4z8ebxPkQZf9A%3D%3D) / [同（DigiKey）](https://www.digikey.com/en/products/detail/murata-electronics/GRM188R61E106KA73D/9867922) |

> **秋月の [0.1µF 50V「F特性」（113374）](https://akizukidenshi.com/catalog/g/g113374/) は買わないこと。**
> JIS の F 特性は Y5V 相当で、温度で **+22%／−82%** も動く。デカップリングには使えない。
> **X7R か X8L** を選ぶこと。上表の 114559（100V X7R）が耐圧にも余裕があって一番安全。

> 22pF（P-11626）は調査時点で**在庫切れ表示**だった。入手できない場合は
> C0G / NP0 特性の 1608 22pF なら何でもよい。

> **C13 は 25V 以上を選ぶこと（v3）。** ロードダンプ時に |Vgs| が最大約13V かかるため
> 16V 品（117202）は不可。秋月なら 35V 品（113161）、海外なら GRM188R61E106（25V）。
> C6・C11 も同じ 35V/25V 品で統一すれば1品目で済む。

## 3. 半導体・ダイオード（7品目）

| Ref | 部品 | 秋月電子 | **マルツ** | Mouser | DigiKey |
|---|---|---|---|---|---|
| **D1, D3** | ショットキー 40V/1A **SOD-123** | ✗（後述） | [`1N5819HW-7-F` で検索](https://www.marutsu.co.jp/GoodsListNavi.jsp?q=1N5819HW-7-F) | [1N5819HW-7-F](https://www.mouser.com/ProductDetail/Diodes-Incorporated/1N5819HW-7-F?qs=NQ47qNm99eDyWTEd07miYA%3D%3D) | [1N5819HW-7-F](https://www.digikey.com/product-detail/en/1N5819HW-7-F/1N5819HW-FDICT-ND/815283) |
| **D2** | SMAJ16A（SMA / 400W） | ✗ | **[SMAJ16A（Littelfuse）](https://www.marutsu.co.jp/pc/i/2079887/)** | `SMAJ16A` で検索 | [SMAJ16A](https://www.digikey.com/en/products/detail/littelfuse-inc/SMAJ16A/762278) |
| ~~D4~~ | ツェナー 3.3V（**v2で廃止**・購入不要） | △ [UDZV3.6B **3.6V**（107435）](https://akizukidenshi.com/catalog/g/g107435/) | [`BZT52C3V3` で検索](https://www.marutsu.co.jp/GoodsListNavi.jsp?q=BZT52C3V3) | [BZT52C3V3-HF](https://www.mouser.com/ProductDetail/Comchip-Technology/BZT52C3V3-HF?qs=sPbYRqrBIVmXM9SVNdMgcA%3D%3D) | [BZT52C3V3-7-F](https://www.digikey.com/en/products/detail/diodes-incorporated/BZT52C3V3-7-F/717854) |
| **D6** | サイドビュー緑LED | **[LP812-010(T)（116854）](https://akizukidenshi.com/catalog/g/g116854/)** ← ここだけ | ✗ | ✗ | ✗ |
| **F1** | PPTC 1A hold 1206 | ✗ | [`1206L110/16WR` で検索](https://www.marutsu.co.jp/GoodsListNavi.jsp?q=1206L110) | `1206L110` で検索 | [1206L110/16WR](https://www.digikey.com/en/products/detail/littelfuse-inc/1206L110-16WR/3997167) |
| **Q1** | MMBT3904 SOT-23 | [20個入 ¥100（105969）](https://akizukidenshi.com/catalog/g/g105969/) | [`MMBT3904` で検索](https://www.marutsu.co.jp/GoodsListNavi.jsp?q=MMBT3904) | [onsemi MMBT3904](https://www.mouser.com/ProductDetail/onsemi/MMBT3904?qs=UMEuL5FsraCg3xKjS4uBJQ%3D%3D) | [onsemi MMBT3904](https://www.digikey.com/en/products/detail/onsemi/MMBT3904/458868) |
| **Q2** | ZXMP6A17E6Q SOT-23-6 | ✗ | [`ZXMP6A17E6QTA` で検索](https://www.marutsu.co.jp/GoodsListNavi.jsp?q=ZXMP6A17E6QTA) | [ZXMP6A17E6QTA](https://www.mouser.com/ProductDetail/Diodes-Incorporated/ZXMP6A17E6QTA?qs=JtunSoW0QGE6mLYIV79weA%3D%3D) | [ZXMP6A17E6QTA](https://www.digikey.com/en/products/detail/diodes-incorporated/ZXMP6A17E6QTA/4810942) |

## 4. IC・モジュール（3品目）

| Ref | 部品 | 秋月電子 | **マルツ** | Mouser / DigiKey |
|---|---|---|---|---|
| ~~U1~~ | M78AR05-0.5（**v4で廃止**・購入不要） | [¥580（107179）](https://akizukidenshi.com/catalog/g/g107179/) | — | — |
| **U4** | **AP63205WU-7**（TSOT-26、5V/2A バック） | ✗ | [`AP63205WU-7` で検索](https://www.marutsu.co.jp/GoodsListNavi.jsp?q=AP63205WU-7) | [Mouser](https://www.mouser.com/ProductDetail/Diodes-Incorporated/AP63205WU-7?qs=u16ybLDytRZtkj8PzdWCOw%3D%3D) / [DigiKey](https://www.digikey.com/en/products/detail/diodes-incorporated/AP63205WU-7/9858424) |
| **L1** | 6.8µH 4030 飽和≥1.5A | ✗ | [`ASPI-4030S-6R8M` で検索](https://www.marutsu.co.jp/GoodsListNavi.jsp?q=ASPI-4030S-6R8M) | [ASPI-4030S-6R8M-T（Mouser）](https://www.mouser.com/ProductDetail/ABRACON/ASPI-4030S-6R8M-T?qs=BLmuIjeT3qE8jeo8oUT4Iw%3D%3D) |
| **C14** | 10µF/**50V** 3216(1206) X7R | ✗ | `GRM31CR71H106KA12` で検索 | 同型番で検索（Murata 1206 50V）|
| **C15** | 22µF/16V 2012(0805) | ✗ | `GRM21BR61C226ME44` で検索 | 同型番で検索 |
| **C16** | 100nF/50V 2012(0805) | ✗ | `0805 100nF 50V X7R` で検索 | 任意メーカー可 |
| **U2** | MCP25625T-E/SS（SSOP-28） | **[¥400（112663）](https://akizukidenshi.com/catalog/g/g112663/)** ← 最安 | [`MCP25625` で検索](https://www.marutsu.co.jp/GoodsListNavi.jsp?q=MCP25625) | [Mouser](https://www.mouser.com/ProductDetail/Microchip-Technology/MCP25625T-E-SS?qs=YlpJWyuQ3PP8xO0AA8P3ZQ%3D%3D) / [DigiKey](https://www.digikey.com/en/products/detail/microchip-technology/MCP25625T-E-SS/4860100) |
| **U3** | Raspberry Pi Pico 2 | [Pico 2（129604）](https://akizukidenshi.com/catalog/g/g129604/) / [**Pico 2 H**（ヘッダ実装済、130982）](https://akizukidenshi.com/catalog/g/g130982/) | [`Raspberry Pi Pico 2` で検索](https://www.marutsu.co.jp/GoodsListNavi.jsp?q=Raspberry+Pi+Pico+2) | — |

**U2 は秋月が ¥400 で最安**（DigiKey は $3.38＝約¥500）。回路図の型番 `MCP25625T-E/SS`
と完全一致する。

## 5. コネクタ・その他（4品目）

| Ref | 部品 | 秋月電子 | **マルツ** | Mouser / DigiKey |
|---|---|---|---|---|
| **J1** | TE 1-967658-1（MQS 8極 RA） | ✗ | [`1-967658-1` で検索](https://www.marutsu.co.jp/GoodsListNavi.jsp?q=1-967658-1) | △ [DigiKey Marketplace](https://www.digikey.be/en/products/detail/te-connectivity-amp-connectors/1-967658-1/10478177) ／ [TE 公式](https://www.te.com/en/product-1-967658-1.html) |
| **J2** | DM3AT-SF-PEJM5（microSD） | ✗ | **[ヒロセ DM3AT-SF-PEJM5](https://www.marutsu.co.jp/pc/i/2571574/)**（[別ページ](https://www.marutsu.co.jp/pc/i/238416/)） | [Mouser](https://www.mouser.com/ProductDetail/Hirose-Connector/DM3AT-SF-PEJM5?qs=LZSZKJVF+2WTDKp+R7IYAQ%3D%3D) / [DigiKey](https://www.digikey.com/en/products/detail/hirose-electric-co-ltd/DM3AT-SF-PEJM5/2533565) |
| **J3** | GT-502MGG-N（GPS） | **[¥3,180（117980）](https://akizukidenshi.com/catalog/g/g117980/)** | [`GT-502MGG-N` で検索](https://www.marutsu.co.jp/GoodsListNavi.jsp?q=GT-502MGG-N) | [DigiKey](https://www.digikey.jp/ja/products/detail/yic/GT-502MGG-N/16499054) |
| **Y1** | 16MHz HC-49/S（THT） | [クリスタル 16MHz（108671）](https://akizukidenshi.com/catalog/g/g108671/) | [`16MHz HC-49` で検索](https://www.marutsu.co.jp/GoodsListNavi.jsp?q=16MHz+HC-49) | — |

**J1（MQS コネクタ）が一番入手しにくい。** DigiKey では Marketplace（第三者出品）扱いで、
在庫・納期が通常在庫品と異なる。マルツ・RS コンポーネンツでも型番検索する価値がある。
**発注前に必ず在庫を確認すること。**

## 6. BOM に無いが必要なもの

**Pico をソケット実装する設計**なので、基板側にメスのピンソケットが要る。

| 必要なもの | 数量 | 秋月電子 |
|---|---|---|
| 1×20 メスピンソケット（2.54mm） | 2本 | [分割ロングピンソケット 1×42（105779）](https://akizukidenshi.com/catalog/g/g105779/) を切って使う |
| Pico 側のオスピンヘッダ | 2本 | [Pico 2 H（130982）](https://akizukidenshi.com/catalog/g/g130982/) なら実装済みなので不要 |

---

## 買ってはいけないもの

### D1/D3 に SS14

秋月にも [SS14（113240）](https://akizukidenshi.com/catalog/g/g113240/) があるが、
これは **SMA（DO-214AC）**で、基板のランドは **SOD-123**。物理的に載らない。
**1N5819HW-7-F**（Diodes Inc、40V/1A、SOD-123）を買うこと。

### C2-C5/C10/C12 に「F特性」の 0.1µF

上記のとおり Y5V 相当。**X7R か X8L** を選ぶこと。

### F1 に 6V / 8V 品

`1206L110` 系には 6V（1206L110SLYR）と 8V（1206L110THYR）もある。
12V 車載では使えない。**1206L110/16WR** を指定すること。
秋月の PICOSMDC110S-2 も 6V。

---

## 補足

### F1 の耐圧 16V は許容済み

1206 で 1.1A hold の PPTC は **16V が上限**。しかも F1 は **D2（TVS）より前段**
（J1.8 → F1 → D1 → D2）にあり、車両側サージをクランプされずに直接受ける唯一の部品。
24V/30V 品は 1812 などサイズアップが必要で基板変更を伴うため、
**ユーザー判断で 16V のまま進める**（2026-07-31）。

### ~~D4 を秋月で買う場合は 3.6V になる~~（v2 で D4 廃止）

v2 で IG 電圧センシングごと削除したため D4 は不要になった。
以下は v1 の記録: 秋月の SOD-123 ツェナーは 3.6V と 5.1V で 3.3V が無く、
ADC 絶対最大定格（VDD+0.3 = 3.6V）に対し余裕ゼロの代用だった。

### Y1 の負荷容量

C7/C8 が 22pF なので、**負荷容量 CL = 16〜20pF** の水晶を選ぶこと。
秋月の 108671 は CL=20pF で適合する。CL=12pF や 32pF の品を買わないこと。

### 手はんだの難所

| 部品 | 難度 |
|---|---|
| **U2 MCP25625（SSOP-28、0.65mmピッチ）** | 最難関。フラックスと引きはんだ推奨 |
| **J2 microSD コネクタ** | 端子が細かく、シェル脚は熱容量が大きい |
| **D6 サイドビューLED** | 基板端（y=61）に置くため位置決めがシビア |
| **J3 GPS パッド** | 5パッドに先バラ線を直付け |
| U3 のソケット | 40穴。数が多いだけで v2 では難所ではない |

**v2 で GND パッドは全数サーマル接続に変更した**（スポーク 0.4mm / ギャップ 0.3mm）。
v1 のベタ直結（GND ピンだけ異様に熱を食う）は解消済み。通常のこて先温度で作業できる。

---

*2026-07-31 時点。価格・在庫は変動するため発注時に各ページで確認すること。*

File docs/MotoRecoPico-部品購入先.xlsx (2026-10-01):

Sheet: 購入先一覧
MotoRecoPico 部品購入先一覧
全41点（v4: 5V電源をAP63205化）を値でまとめて25品目＋ソケット。リンクは実在を確認したページのみ。空欄＝そのベンダーで確認できなかった（無いとは限らない）。
マルツは DigiKey の国内唯一の正規代理店。DigiKey 全品を1個から同価格で買え、送料は全国一律 ¥240（¥3,000以上で無料）。秋月＋マルツの2社で全部揃う。
分類 | 型番 / 値 | パッケージ | 数量 | 使用箇所 | 秋月電子 | マルツ | Mouser | DigiKey | 備考 | 発注済
抵抗 | 100kΩ 1/10W | 1608 (0603) | 3 | R1, R2, R3 | 100個入 ¥150 (130357) (https://akizukidenshi.com/catalog/g/g130357/) | RC0603FR-07100KL (https://www.marutsu.co.jp/GoodsListNavi.jsp?q=RC0603FR-07100KL)
抵抗 | 22kΩ 1/10W | 1608 (0603) | 1 | R4 | 小分けなし | RC0603FR-0722KL (https://www.marutsu.co.jp/GoodsListNavi.jsp?q=RC0603FR-0722KL) |  |  | 秋月は1608の22kΩを小分けで扱っていない
抵抗 | 10kΩ 1/10W | 1608 (0603) | 7 | R6, R7, R10-R13, R15 (IG検知) | 100個入 ¥150 (130355) (https://akizukidenshi.com/catalog/g/g130355/) | RC0603FR-0710KL (https://www.marutsu.co.jp/GoodsListNavi.jsp?q=RC0603FR-0710KL)
抵抗 | 120Ω 1/10W | 1608 (0603) | 1 | R8 (CAN終端) | 5000個リール ¥980 (130332) (https://akizukidenshi.com/catalog/g/g130332/) | RC0603FR-07120RL (https://www.marutsu.co.jp/GoodsListNavi.jsp?q=RC0603FR-07120RL) |  |  | 秋月はリールのみ。1本だけ要るのでマルツ推奨
抵抗 | 1kΩ 1/10W | 1608 (0603) | 1 | R14 | 5000個リール ¥980 (114122) (https://akizukidenshi.com/catalog/g/g114122/) | RC0603FR-071KL (https://www.marutsu.co.jp/GoodsListNavi.jsp?q=RC0603FR-071KL) |  |  | 秋月はリールのみ。1本だけ要るのでマルツ推奨
コンデンサ | 100nF / 50V以上 X7R | 1608 (0603) | 5 | C2-C5, C10 | 0.1µF 100V X7R (114559) (https://akizukidenshi.com/catalog/g/g114559/) | CC0603KRX7R9BB104 (https://www.marutsu.co.jp/GoodsListNavi.jsp?q=CC0603KRX7R9BB104) |  |  | ★F特性(113374)は買わないこと。Y5V相当で-82%変動する
コンデンサ | 22pF / 50V C0G(NP0) | 1608 (0603) | 2 | C7, C8 (水晶負荷) | 40個入 ¥100 (P-11626) (https://www.akizukidenshi.com/catalog/g/gP-11626/) | CC0603JRNPO9BN220 (https://www.marutsu.co.jp/GoodsListNavi.jsp?q=CC0603JRNPO9BN220) |  |  | 調査時点で秋月は在庫切れ表示
コンデンサ | 10µF / 25V以上 | 1608 (0603) | 3 | C6, C11, C13 (Q2ゲート遅延) | 35V (113161) / 16V (117202) (https://akizukidenshi.com/catalog/g/g113161/) | GRM188R61E106KA73D (https://www.marutsu.co.jp/GoodsListNavi.jsp?q=GRM188R61E106KA73D) | GRM188R61E106KA73D (https://www.mouser.com/ProductDetail/Murata-Electronics/GRM188R61E106KA73D?qs=5aG0NVq1C4z8ebxPkQZf9A%3D%3D) | GRM188R61E106KA73D (https://www.digikey.com/en/products/detail/murata-electronics/GRM188R61E106KA73D/9867922) | C13はロードダンプ時に約13Vかかるため25V以上必須。3点とも25V/35V品で統一が楽
ダイオード | B5819W (40V/1A ショットキー) | SOD-123 | 2 | D1, D3 | 取扱いなし | 1N5819HW-7-F (https://www.marutsu.co.jp/GoodsListNavi.jsp?q=1N5819HW-7-F) | 1N5819HW-7-F (https://www.mouser.com/ProductDetail/Diodes-Incorporated/1N5819HW-7-F?qs=NQ47qNm99eDyWTEd07miYA%3D%3D) | 1N5819HW-7-F (https://www.digikey.com/product-detail/en/1N5819HW-7-F/1N5819HW-FDICT-ND/815283) | ★秋月のSS14はSMAパッケージで載らない
ダイオード | SMAJ16A (TVS 400W) | SMA (DO-214AC) | 1 | D2 | 取扱いなし | Littelfuse SMAJ16A (https://www.marutsu.co.jp/pc/i/2079887/) | SMAJ16A (https://www.mouser.com/) | Littelfuse SMAJ16A (https://www.digikey.com/en/products/detail/littelfuse-inc/SMAJ16A/762278)
LED | LP812-010(T) 緑 サイドビュー | 2.8×1.2mm | 1 | D6 | 10個入 ¥100 (116854) (https://akizukidenshi.com/catalog/g/g116854/) | 取扱いなし |  |  | ★秋月でしか買えない
回路保護 | PPTC 1.1A hold 16V | 1206 | 1 | F1 | 取扱いなし | 1206L110/16WR (https://www.marutsu.co.jp/GoodsListNavi.jsp?q=1206L110) | 1206L110/16WR (https://www.mouser.com/) | 1206L110/16WR (https://www.digikey.com/en/products/detail/littelfuse-inc/1206L110-16WR/3997167) | ★6V品(SLYR)・8V品(THYR)と間違えないこと
トランジスタ | MMBT3904 (NPN) | SOT-23 | 1 | Q1 | 20個入 ¥100 (105969) (https://akizukidenshi.com/catalog/g/g105969/) | MMBT3904 (https://www.marutsu.co.jp/GoodsListNavi.jsp?q=MMBT3904) | onsemi MMBT3904 (https://www.mouser.com/ProductDetail/onsemi/MMBT3904?qs=UMEuL5FsraCg3xKjS4uBJQ%3D%3D) | onsemi MMBT3904 (https://www.digikey.com/en/products/detail/onsemi/MMBT3904/458868)
MOSFET | ZXMP6A17E6Q (Pch -60V) | SOT-23-6 | 1 | Q2 (高側SW) | 取扱いなし | ZXMP6A17E6QTA (https://www.marutsu.co.jp/GoodsListNavi.jsp?q=ZXMP6A17E6QTA) | ZXMP6A17E6QTA (https://www.mouser.com/ProductDetail/Diodes-Incorporated/ZXMP6A17E6QTA?qs=JtunSoW0QGE6mLYIV79weA%3D%3D) | ZXMP6A17E6QTA (https://www.digikey.com/en/products/detail/diodes-incorporated/ZXMP6A17E6QTA/4810942)
電源IC | AP63205WU-7 (5V固定 2A バック) | TSOT-26 | 1 | U4 (v4) | 取扱いなし | AP63205WU-7 (https://www.marutsu.co.jp/GoodsListNavi.jsp?q=AP63205WU-7) | AP63205WU-7 (https://www.mouser.com/ProductDetail/Diodes-Incorporated/AP63205WU-7?qs=u16ybLDytRZtkj8PzdWCOw%3D%3D) | AP63205WU-7 (https://www.digikey.com/en/products/detail/diodes-incorporated/AP63205WU-7/9858424) | v4でM78AR05を置換。最低入力3.8Vでクランキング問題も解消
インダクタ | 6.8µH 4030 飽和≥1.5A | 4×4×3mm | 1 | L1 (v4) | 取扱いなし | ASPI-4030S-6R8M (https://www.marutsu.co.jp/GoodsListNavi.jsp?q=ASPI-4030S-6R8M) | ASPI-4030S-6R8M-T (https://www.mouser.com/ProductDetail/ABRACON/ASPI-4030S-6R8M-T?qs=BLmuIjeT3qE8jeo8oUT4Iw%3D%3D) |  | シールド品推奨。基板裏面の最背部品(3mm)
コンデンサ | 10µF / 50V X7R | 3216 (1206) | 1 | C14 バック入力 (v4) | 取扱いなし | GRM31CR71H106KA12 (https://www.marutsu.co.jp/GoodsListNavi.jsp?q=GRM31CR71H106KA12) | 810-CNA5L171H106K160 (https://www.mouser.jp/en/ProductDetail/TDK/CNA5L1X7R1H106K160AE?qs=Y0Uzf4wQF3kvAkifwkQiJA%3D%3D) |  | ★入力はクランプ26Vを直接見るため50V必須。25V品不可
コンデンサ | 22µF / 16V | 2012 (0805) | 1 | C15 バック出力 (v4) | 取扱いなし | GRM21BR61C226ME44 (https://www.marutsu.co.jp/GoodsListNavi.jsp?q=GRM21BR61C226ME44) | 81-GXT21BR61C226ME3L (https://www.mouser.jp/en/ProductDetail/Murata/GXT21BR61C226ME13L?qs=d0WKAl%252BL4Kb74FO4906dbA%3D%3D)
コンデンサ | 100nF / 50V X7R | 2012 (0805) | 1 | C16 ブートストラップ (v4) | 取扱いなし | 0805 100nF 50V (https://www.marutsu.co.jp/GoodsListNavi.jsp?q=GRM21BR71H104KA01) | 581-KAF21BR71H104KM (https://www.mouser.jp/en/ProductDetail/KYOCERA-AVX/KAF21BR71H104KM?qs=Jm2GQyTW%2FbhmrEcuwq3xrw%3D%3D) |  | 1608でなく2012なのは「1608全数表面」規則のため（裏面実装）
IC | MCP25625T-E/SS (CAN) | SSOP-28 0.65mm | 1 | U2 | ¥400 (112663) (https://akizukidenshi.com/catalog/g/g112663/) | MCP25625 (https://www.marutsu.co.jp/GoodsListNavi.jsp?q=MCP25625) | MCP25625T-E/SS (https://www.mouser.com/ProductDetail/Microchip-Technology/MCP25625T-E-SS?qs=YlpJWyuQ3PP8xO0AA8P3ZQ%3D%3D) | MCP25625T-E/SS (https://www.digikey.com/en/products/detail/microchip-technology/MCP25625T-E-SS/4860100) | ★秋月が最安（DigiKeyは$3.38）。手はんだ最難関
マイコン | Raspberry Pi Pico 2 | 2×20 2.54mm | 1 | U3 | Pico 2 H ヘッダ実装済 (130982) (https://akizukidenshi.com/catalog/g/g130982/) | Raspberry Pi Pico 2 (https://www.marutsu.co.jp/GoodsListNavi.jsp?q=Raspberry+Pi+Pico+2) |  |  | ヘッダ無しは (129604)。H版なら自分でヘッダを付けずに済む
コネクタ | TE 1-967658-1 (MQS 8極 RA) | THT ライトアングル | 1 | J1 (車両I/F) | 取扱いなし | 1-967658-1 (https://www.marutsu.co.jp/GoodsListNavi.jsp?q=1-967658-1) | 1-967658-1 (https://www.mouser.jp/en/ProductDetail/TE-Connectivity-AMP/1-967658-1?qs=6Z%252BHCgJKjncTVf7nPH%2FL8g%3D%3D) | DigiKey Marketplace (https://www.digikey.be/en/products/detail/te-connectivity-amp-connectors/1-967658-1/10478177) | ★最も入手しにくい。DigiKeyは第三者出品。発注前に在庫確認
コネクタ | DM3AT-SF-PEJM5 (microSD) | SMD ライトアングル | 1 | J2 | 取扱いなし | ヒロセ DM3AT-SF-PEJM5 (https://www.marutsu.co.jp/pc/i/2571574/) | DM3AT-SF-PEJM5 (https://www.mouser.com/ProductDetail/Hirose-Connector/DM3AT-SF-PEJM5?qs=LZSZKJVF+2WTDKp+R7IYAQ%3D%3D) | DM3AT-SF-PEJM5 (https://www.digikey.com/en/products/detail/hirose-electric-co-ltd/DM3AT-SF-PEJM5/2533565)
モジュール | GT-502MGG-N (GPS) | 先バラ5線 | 1 | J3 | ¥3,180 (117980) (https://akizukidenshi.com/catalog/g/g117980/) | GT-502MGG-N (https://www.marutsu.co.jp/GoodsListNavi.jsp?q=GT-502MGG-N) |  | YIC GT-502MGG-N (https://www.digikey.jp/ja/products/detail/yic/GT-502MGG-N/16499054) | 秋月が最安
水晶 | 16MHz HC-49/S CL=16〜20pF | THT | 1 | Y1 | CL=20pF (108671) (https://akizukidenshi.com/catalog/g/g108671/) | 16MHz HC-49 (https://www.marutsu.co.jp/GoodsListNavi.jsp?q=16MHz+HC-49) |  |  | ★CL=12pFや32pFの品は不可（C7/C8が22pFのため）
【BOM外】 | 1×20 メスピンソケット 2.54mm | THT | 2 | U3 のソケット | 分割ロングピンソケット 1×42 (105779) (https://akizukidenshi.com/catalog/g/g105779/) |  |  |  | Pico をソケット実装する設計のため基板側に必要。1×42を切って使う
 |  | 合計 | 43 | 点（BOM 38点 + ソケット2本）

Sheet: 注意事項
発注・実装時の注意
区分 | 項目 | 内容
買ってはいけない | D1/D3 に SS14 | 秋月のSS14(113240)はSMA(DO-214AC)。基板のランドはSOD-123なので物理的に載らない。1N5819HW-7-F（40V/1A・SOD-123）を買うこと。
買ってはいけない | C2-C5/C10/C12 に「F特性」の0.1µF | 秋月の0.1µF 50V F特性(113374)はJISのF特性＝Y5V相当で、温度により+22%/-82%変動する。デカップリングには使えない。X7R か X8L を選ぶこと。
買ってはいけない | F1 に 6V / 8V 品 | 1206L110系には6V(1206L110SLYR)と8V(1206L110THYR)もある。12V車載では使えない。1206L110/16WR を指定すること。秋月のPICOSMDC110S-2も6V。
仕様の判断 | F1 の耐圧16Vは許容済み | 1206で1.1A holdのPPTCは16Vが上限。しかもF1はD2(TVS)より前段(J1.8→F1→D1→D2)にあり、車両側サージをクランプされずに直接受ける唯一の部品。24V/30V品は1812などサイズアップが必要で基板変更を伴うため、ユーザー判断で16Vのまま進める（2026-07-31）。
v3変更 | C13（10µF/25V）と R15（10k）が増えた | v3（2026-08-09）でIGN OFF遅延を追加。C13はQ2のゲート–ソース間で25V以上必須、R15はQ1ベース→GP28のIG検知用。10µFは3点、10kΩは7点になった。
v2変更 | R5・D4・C12 は購入不要 | v2（2026-08-08）でIG電圧センシングを廃止し、R5（10k 1点）、D4（3.3Vツェナー）、C12（100nF 1点）を削除した。10kΩは6点、100nFは5点に減っている。
仕様の判断 | Y1 の負荷容量 | C7/C8が22pFなので負荷容量CL=16〜20pFの水晶を選ぶこと。秋月の108671はCL=20pFで適合。CL=12pFや32pFの品は不可。
入手性 | J1（MQSコネクタ）が最難関 | DigiKeyではMarketplace（第三者出品）扱いで在庫・納期が通常在庫品と異なる。マルツ・RSコンポーネンツでも型番検索する価値がある。代替の効かない部品なので発注前に必ず在庫を確認すること。
入手性 | 秋月でしか買えないもの | D6（LP812-010(T) サイドビューLED）はKODENSHIの国内向け品で海外流通が無い。J3（GT-502MGG-N）はDigiKeyにもあるが秋月が最安（¥3,180）。
入手性 | 秋月の1608抵抗は小分けが限られる | 10kΩ(130355)と100kΩ(130357)は100個入 ¥150 があるが、22kΩ・120Ω・1kΩは5000個リール(¥980)しかない。この3点はマルツで単品購入する方が現実的。
手はんだ | U2 MCP25625（SSOP-28 0.65mmピッチ） | 最難関。フラックスと引きはんだを推奨。
手はんだ | J2 microSDコネクタ | 端子が細かく、シェル脚は熱容量が大きい。
手はんだ | D6 サイドビューLED | 基板端（y=61）に置くため位置決めがシビア。
v2変更 | GNDパッドはサーマル接続になった | v2で全ゾーンをサーマル接続（スポーク0.4mm/ギャップ0.3mm）に変更。v1のベタ直結（GNDピンだけ異様に熱を食う）は解消済みで、通常のこて先温度で作業できる。
BOM外 | Picoのソケットが要る | Picoをソケット実装する設計なので、基板側に1×20メスピンソケットが2本必要。分割ロングピンソケット1×42(105779)を切って使う。Pico側のオスヘッダはPico 2 H(130982)を買えば実装済みで不要。

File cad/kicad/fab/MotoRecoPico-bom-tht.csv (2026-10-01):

Designator | Comment | Footprint | Qty
J1 | 1-967658-1 | MotoRecoPico:MQS-8-RA-1-967658-1 | 1
U3 | Pico 2 | Module:RaspberryPi_Pico_Common_THT | 1
Y1 | 16MHz | Crystal:Crystal_HC49-4H_Vertical | 1

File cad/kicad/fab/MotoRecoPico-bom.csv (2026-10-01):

Designator | Comment | Footprint | Qty
C2 | 100nF/50V | Capacitor_SMD:C_0603_1608Metric | 1
C3 | 100nF | Capacitor_SMD:C_0603_1608Metric | 1
C4 | 100nF | Capacitor_SMD:C_0603_1608Metric | 1
C5 | 100nF | Capacitor_SMD:C_0603_1608Metric | 1
C6 | 10uF | Capacitor_SMD:C_0603_1608Metric | 1
C7 | 22pF | Capacitor_SMD:C_0603_1608Metric | 1
C8 | 22pF | Capacitor_SMD:C_0603_1608Metric | 1
C10 | 100nF | Capacitor_SMD:C_0603_1608Metric | 1
C11 | 10uF | Capacitor_SMD:C_0603_1608Metric | 1
C13 | 10uF/25V | Capacitor_SMD:C_0603_1608Metric | 1
C14 | 10uF/50V | Capacitor_SMD:C_1206_3216Metric | 1
C15 | 22uF/16V | Capacitor_SMD:C_0805_2012Metric | 1
C16 | 100nF/50V | Capacitor_SMD:C_0805_2012Metric | 1
D1 | B5819W | Diode_SMD:D_SOD-123 | 1
D2 | SMAJ16A | Diode_SMD:D_SMA | 1
D3 | B5819W | Diode_SMD:D_SOD-123 | 1
D6 | GREEN | MotoRecoPico:LED-SideView-2.8x1.2 | 1
F1 | 1A hold | Fuse:Fuse_1206_3216Metric | 1
J2 | DM3AT-SF-PEJM5 | Connector_Card:microSD_HC_Hirose_DM3AT-SF-PEJM5 | 1
J3 | GT-502MGG-N | MotoRecoPico:GPS-5P-SMD-2.54 | 1
L1 | 6.8uH | MotoRecoPico:L_4030_HandSolder | 1
Q1 | MMBT3904 | Package_TO_SOT_SMD:SOT-23 | 1
Q2 | ZXMP6A17E6Q | Package_TO_SOT_SMD:TSOT-23-6_HandSoldering | 1
R1 | 100k | Resistor_SMD:R_0603_1608Metric | 1
R2 | 100k | Resistor_SMD:R_0603_1608Metric | 1
R3 | 100k | Resistor_SMD:R_0603_1608Metric | 1
R4 | 22k | Resistor_SMD:R_0603_1608Metric | 1
R6 | 10k | Resistor_SMD:R_0603_1608Metric | 1
R7 | 10k | Resistor_SMD:R_0603_1608Metric | 1
R8 | 120 | Resistor_SMD:R_0603_1608Metric | 1
R10 | 10k | Resistor_SMD:R_0603_1608Metric | 1
R11 | 10k | Resistor_SMD:R_0603_1608Metric | 1
R12 | 10k | Resistor_SMD:R_0603_1608Metric | 1
R13 | 10k | Resistor_SMD:R_0603_1608Metric | 1
R14 | 1k | Resistor_SMD:R_0603_1608Metric | 1
R15 | 10k | Resistor_SMD:R_0603_1608Metric | 1
U2 | MCP25625 | Package_SO:SSOP-28_5.3x10.2mm_P0.65mm | 1
U4 | AP63205WU-7 | Package_TO_SOT_SMD:TSOT-23-6_HandSoldering | 1

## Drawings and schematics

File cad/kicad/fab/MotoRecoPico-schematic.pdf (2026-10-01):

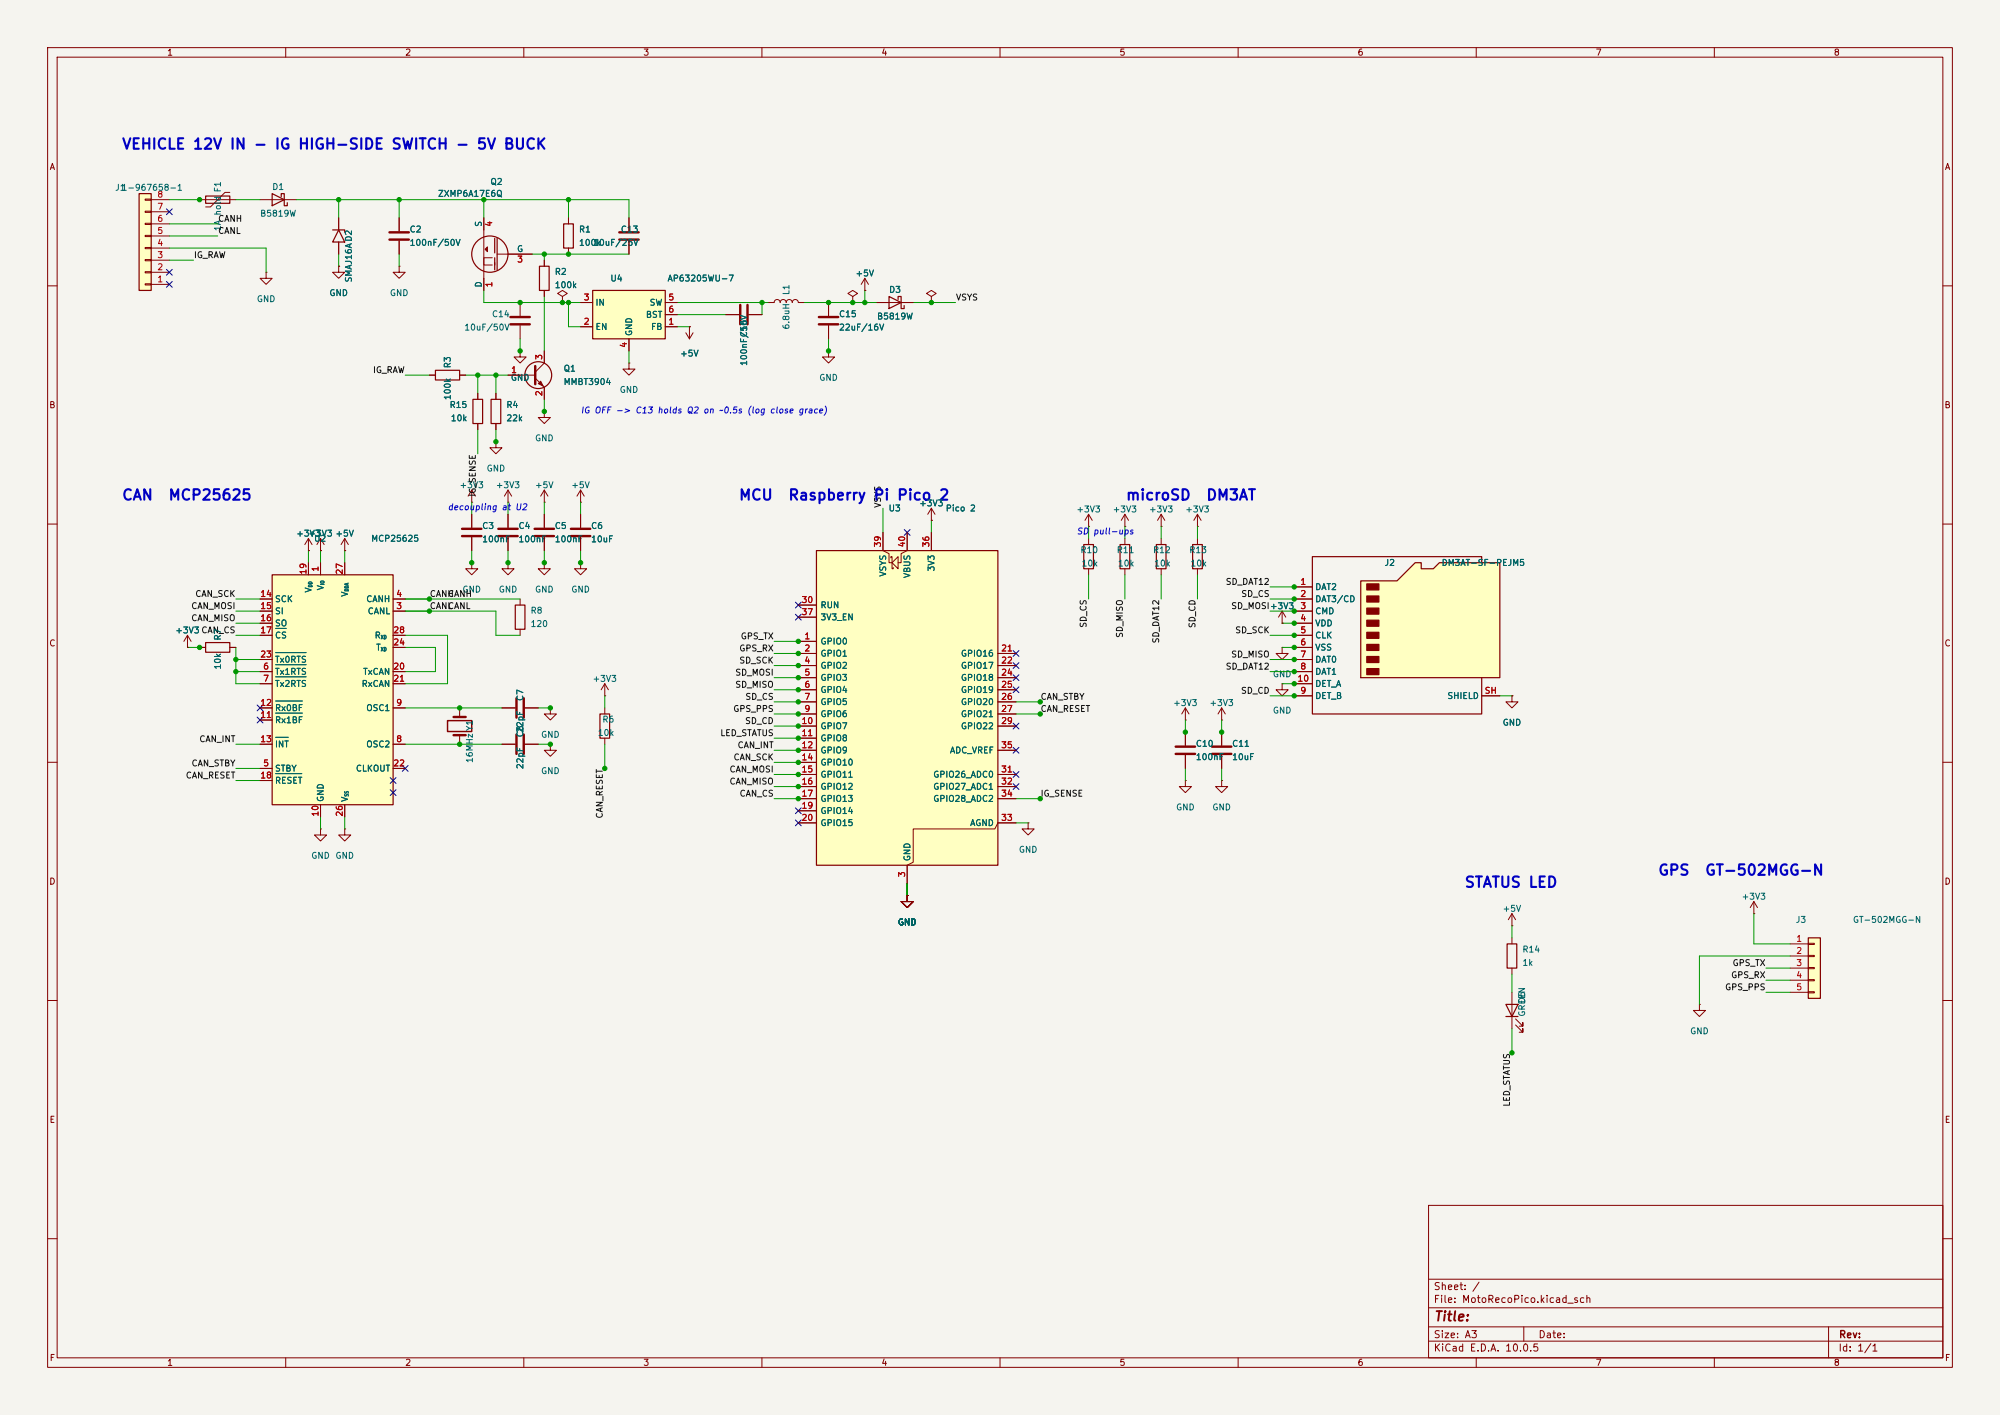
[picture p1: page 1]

VEHICLE 12V IN - IG HIGH-SIDE SWITCH - 5V BUCK

IG OFF -> C13 holds Q2 on ~0.5s (log close grace)

Size: A3 | Rev: | F Date:
KiCad E.D.A. 10.0.5 | Id: 1/1

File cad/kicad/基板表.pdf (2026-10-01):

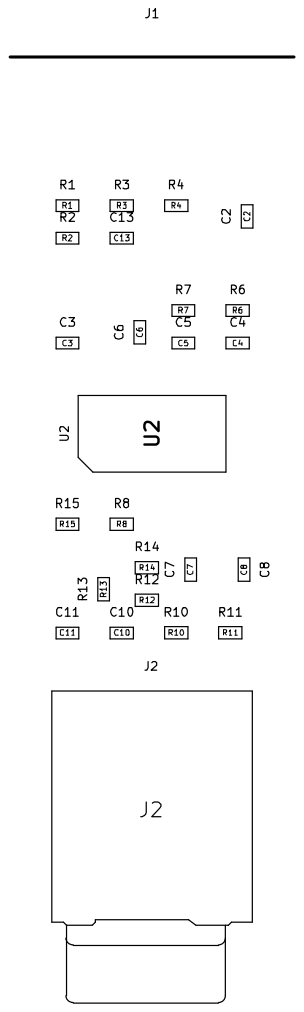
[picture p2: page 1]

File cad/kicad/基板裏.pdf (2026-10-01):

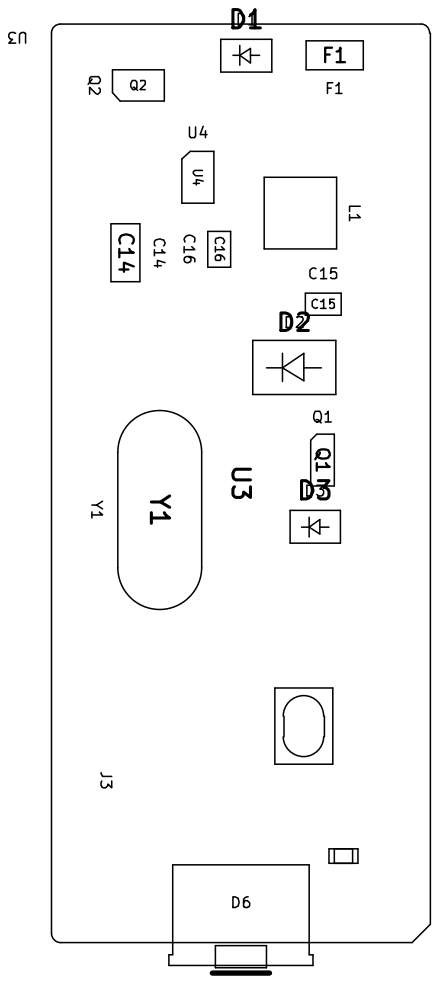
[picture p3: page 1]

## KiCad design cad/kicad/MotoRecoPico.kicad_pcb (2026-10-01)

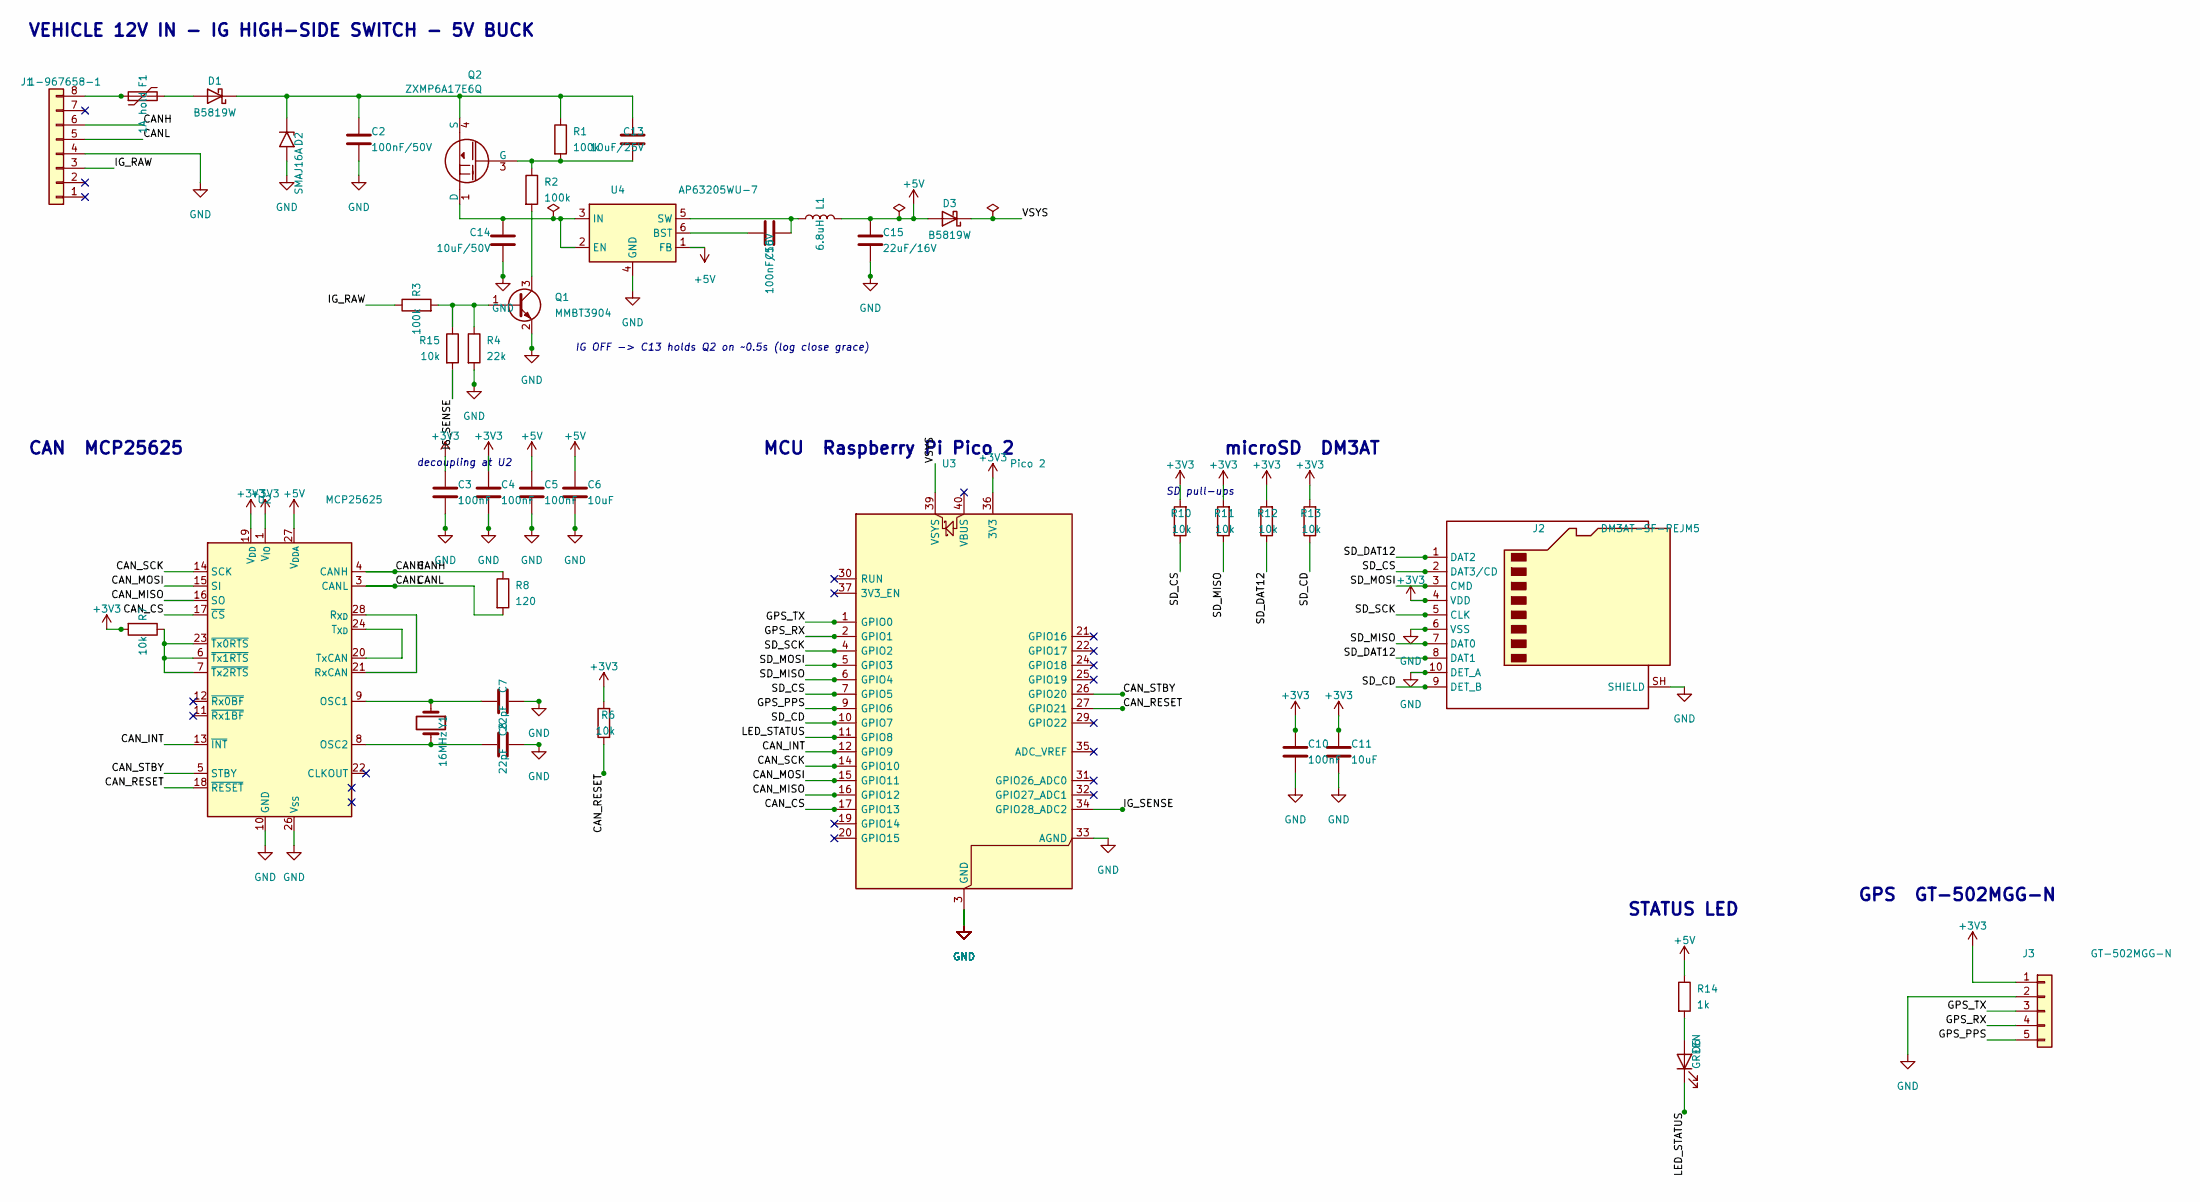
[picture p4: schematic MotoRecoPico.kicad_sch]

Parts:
C2: 100nF/50V; C_0603_1608Metric
C3, C4, C5, C10: 100nF; C_0603_1608Metric
C6, C11: 10uF; C_0603_1608Metric
C7, C8: 22pF; C_0603_1608Metric
C13: 10uF/25V; C_0603_1608Metric
C14: 10uF/50V; C_1206_3216Metric
C15: 22uF/16V; C_0805_2012Metric
C16: 100nF/50V; C_0805_2012Metric
D1, D3: B5819W; D_SOD-123
D2: SMAJ16A; D_SMA
D6: GREEN; LED-SideView-2.8x1.2
F1: 1A hold; Fuse_1206_3216Metric
J1: 1-967658-1; MQS-8-RA-1-967658-1
J2: DM3AT-SF-PEJM5; microSD_HC_Hirose_DM3AT-SF-PEJM5
J3: GT-502MGG-N; GPS-5P-SMD-2.54
L1: 6.8uH; L_4030_HandSolder
Q1: MMBT3904; SOT-23
Q2: ZXMP6A17E6Q; TSOT-23-6_HandSoldering
R1, R2, R3: 100k; R_0603_1608Metric
R4: 22k; R_0603_1608Metric
R6, R7, R10, R11, R12, R13, R15: 10k; R_0603_1608Metric
R8: 120; R_0603_1608Metric
R14: 1k; R_0603_1608Metric
U2: MCP25625; SSOP-28_5.3x10.2mm_P0.65mm
U3: Pico 2; RaspberryPi_Pico_Common_THT
U4: AP63205WU-7; TSOT-23-6_HandSoldering
Y1: 16MHz; Crystal_HC49-4H_Vertical

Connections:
BST_5V: C16.2, U4.6 (BST)
CANH: J1.6, R8.1, U2.4 (CANH)
CANL: J1.5, R8.2, U2.3 (CANL)
CAN_CS: U2.17 (~CS), U3.17 (GPIO13)
CAN_INT: U2.13 (~INT), U3.12 (GPIO9)
CAN_MISO: U2.16 (SO), U3.16 (GPIO12)
CAN_MOSI: U2.15 (SI), U3.15 (GPIO11)
CAN_RESET: R6.1, U2.18 (~RESET), U3.27 (GPIO21)
CAN_SCK: U2.14 (SCK), U3.14 (GPIO10)
CAN_STBY: U2.5 (STBY), U3.26 (GPIO20)
GND: C2.2, C3.2, C4.2, C5.2, C6.2, C7.2, C8.2, C10.2, C11.2, C14.2, C15.2, D2.2 (A2), J1.4, J2.6 (VSS), J2.10 (DET_A), J2.SH (SHIELD), J3.2, Q1.2 (E), R4.2, U2.10 (GND), U2.26 (V_{SS}), U3.3 (GND), U3.8 (GND), U3.13 (GND), U3.18 (GND), U3.23 (GND), U3.28 (GND), U3.33 (AGND), U3.38 (GND), U4.4 (GND)
GPS_PPS: J3.5, U3.9 (GPIO6)
GPS_RX: J3.4, U3.2 (GPIO1)
GPS_TX: J3.3, U3.1 (GPIO0)
IG_RAW: J1.3, R3.1
IG_SENSE: R15.2, U3.34 (GPIO28_ADC2)
LED_A: D6.2 (A), R14.2
LED_STATUS: D6.1 (K), U3.11 (GPIO8)
Q1_B: Q1.1 (B), R3.2, R4.1, R15.1
Q1_C: Q1.3 (C), R2.2
Q2_G: C13.1, Q2.3 (G), R1.2, R2.1
RXCAN: U2.21 (RxCAN), U2.28 (R_{XD})
SD_CD: J2.9 (DET_B), R13.1, U3.10 (GPIO7)
SD_CS: J2.2 (DAT3/CD), R10.1, U3.7 (GPIO5)
SD_DAT12: J2.1 (DAT2), J2.8 (DAT1), R12.1
SD_MISO: J2.7 (DAT0), R11.1, U3.6 (GPIO4)
SD_MOSI: J2.3 (CMD), U3.5 (GPIO3)
SD_SCK: J2.5 (CLK), U3.4 (GPIO2)
SW_5V: C16.1, L1.1, U4.5 (SW)
TXCAN: U2.20 (TxCAN), U2.24 (T_{XD})
TXNRTS: R7.1, U2.6 (~Tx1RTS), U2.7 (~Tx2RTS), U2.23 (~Tx0RTS)
V3V3: C3.1, C4.1, C10.1, C11.1, J2.4 (VDD), J3.1, R6.2, R7.2, R10.2, R11.2, R12.2, R13.2, U2.1 (V_{IO}), U2.19 (V_{DD}), U3.36 (3V3)
V5: C5.1, C6.1, C15.1, D3.2 (A), L1.2, R14.1, U2.27 (V_{DDA}), U4.1 (FB)
V12P: C2.1, C13.2, D1.1 (K), D2.1 (A1), Q2.4 (S), R1.1
V12_FUSED: D1.2 (A), F1.2
V12_RAW: F1.1, J1.8
V12_SW: C14.1, Q2.1 (D), Q2.2 (D), Q2.5 (D), Q2.6 (D), U4.2 (EN), U4.3 (IN)
VSYS: D3.1 (K), U3.39 (VSYS)
XTAL1: C7.1, U2.9 (OSC1), Y1.1
XTAL2: C8.1, U2.8 (OSC2), Y1.2

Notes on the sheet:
VEHICLE 12V IN - IG HIGH-SIDE SWITCH - 5V BUCK
CAN MCP25625
MCU Raspberry Pi Pico 2
microSD DM3AT
GPS GT-502MGG-N
STATUS LED
IG OFF -> C13 holds Q2 on ~0.5s (log close grace)
decoupling at U2
SD pull-ups

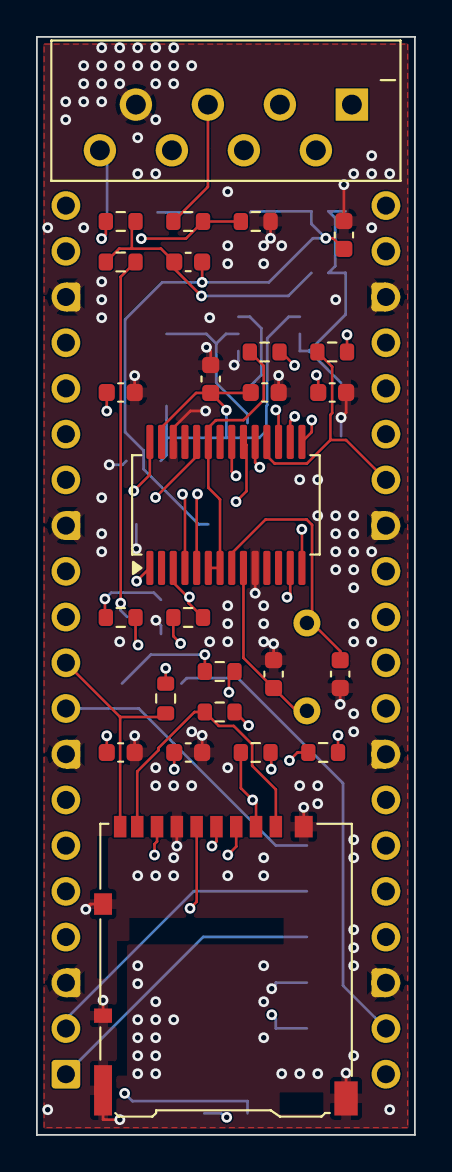
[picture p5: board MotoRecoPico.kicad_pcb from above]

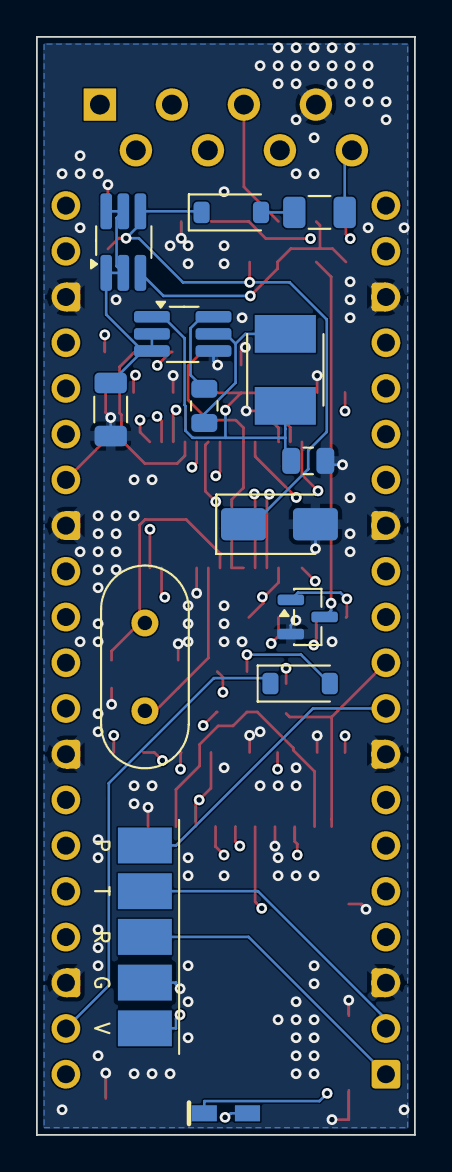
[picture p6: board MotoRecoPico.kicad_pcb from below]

Board: 4 copper layers, 21.0 x 61.0 mm, 41 parts (15 on the bottom side), 40 nets.

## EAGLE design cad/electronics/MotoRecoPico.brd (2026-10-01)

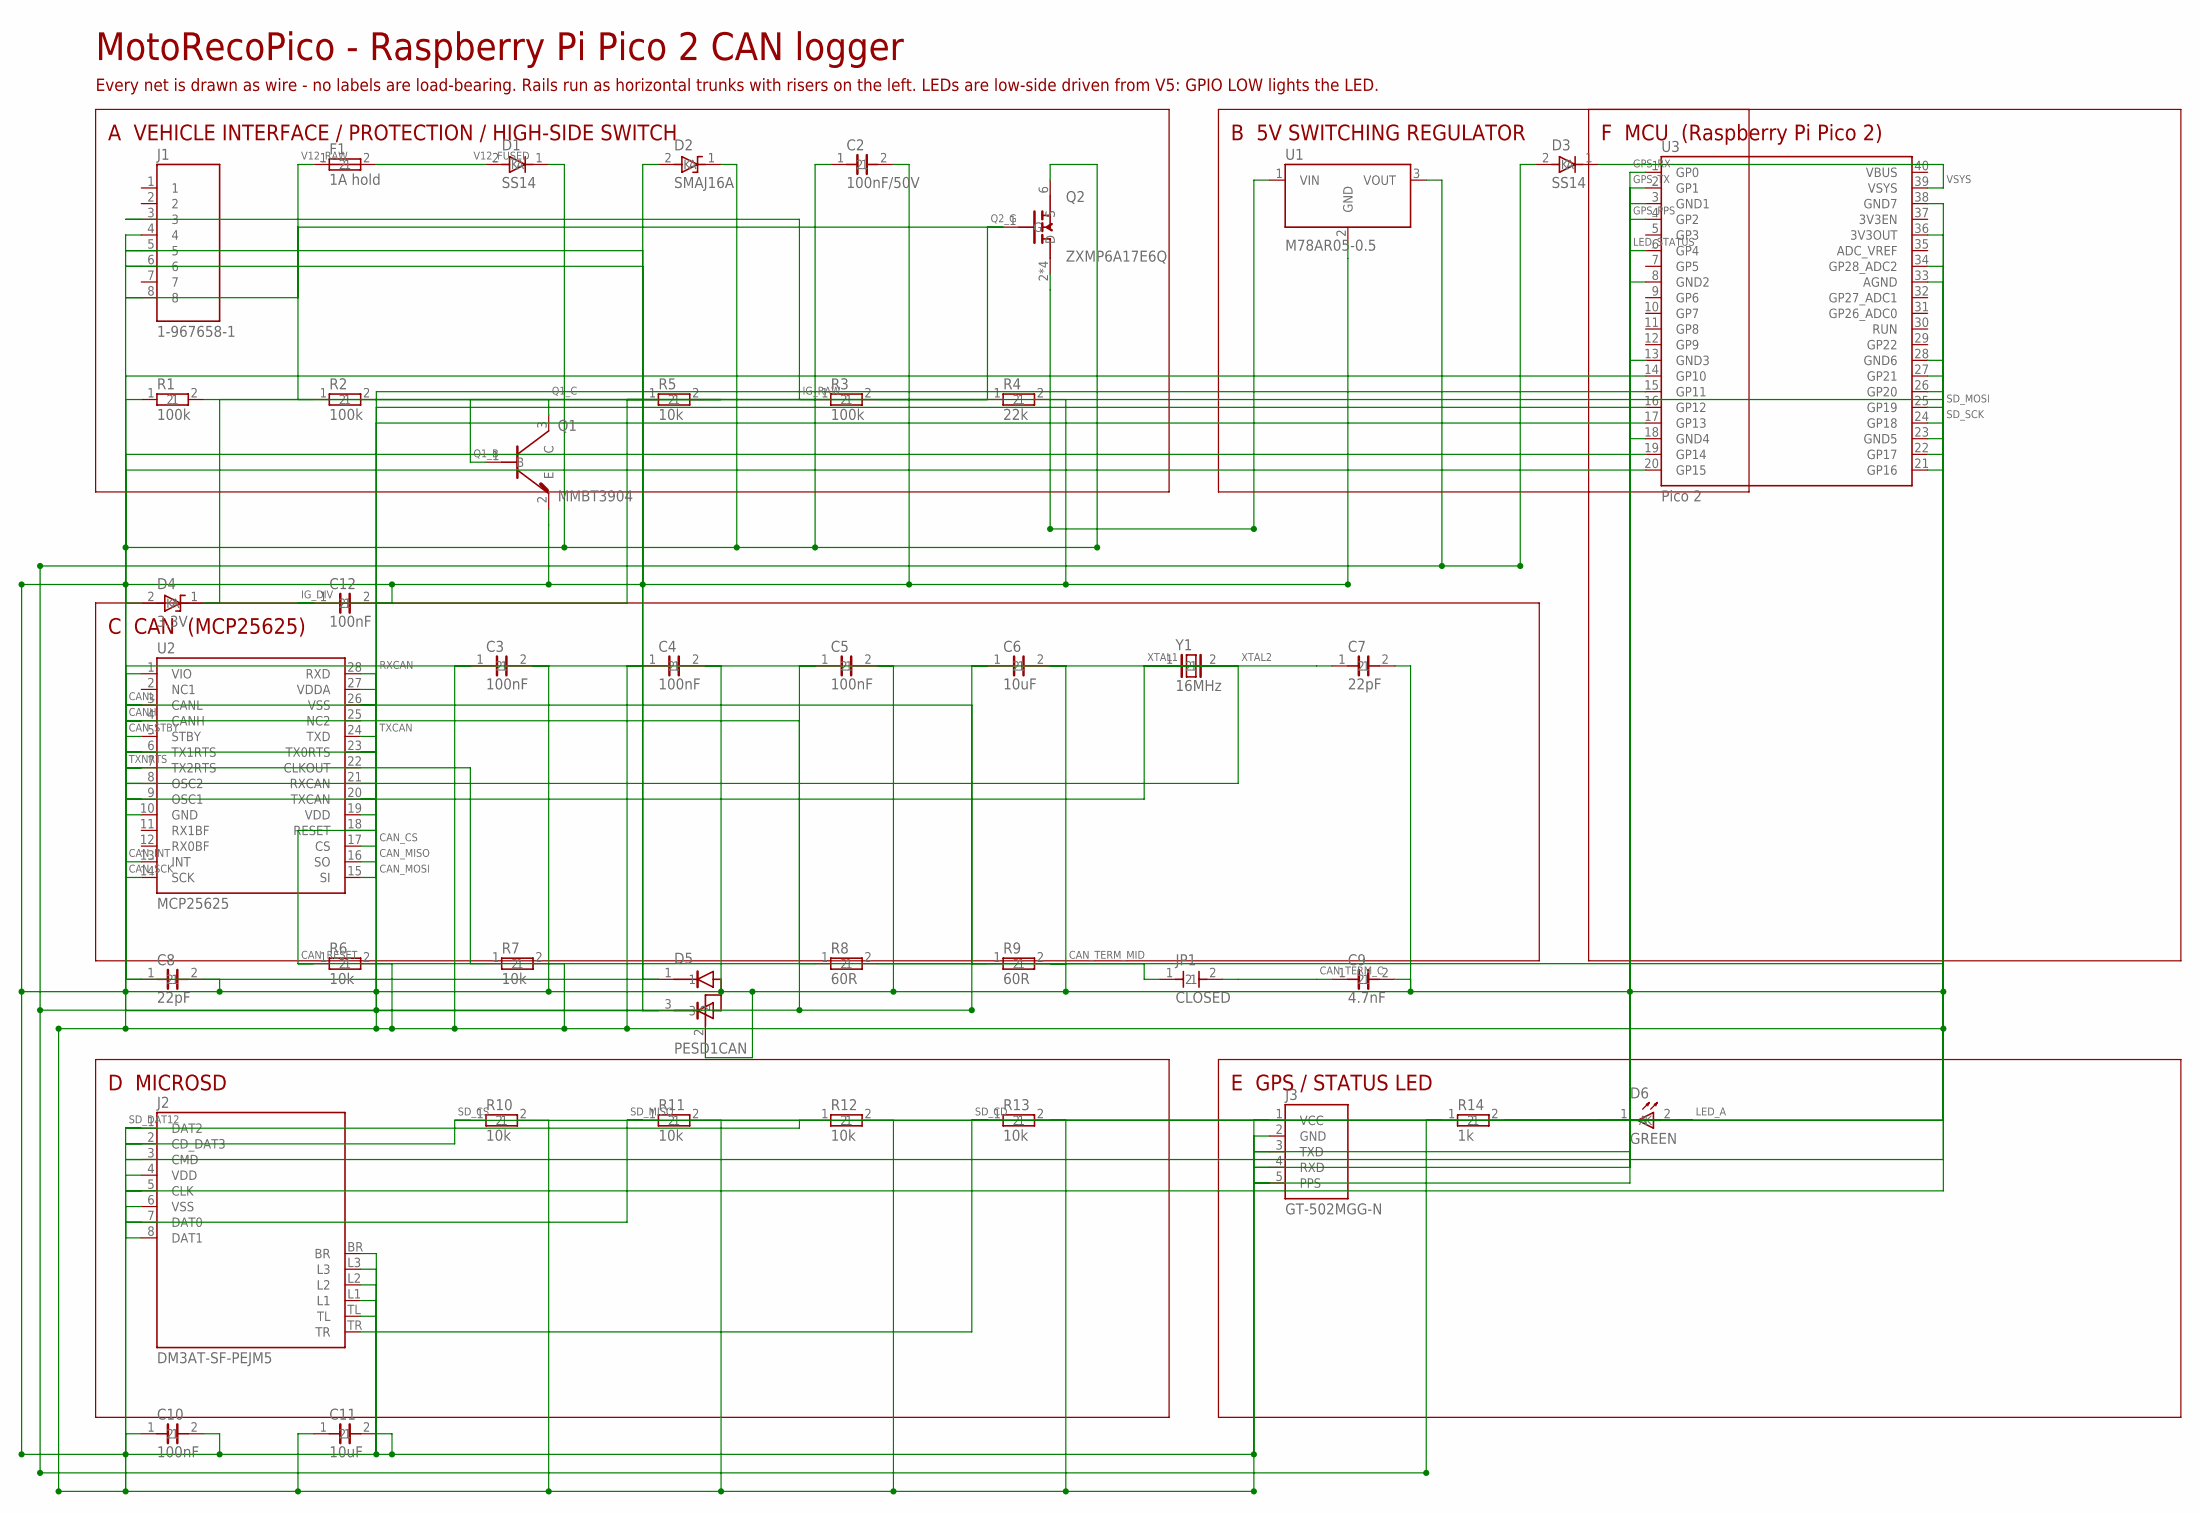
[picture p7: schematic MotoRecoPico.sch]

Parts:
C2: 100nF/50V; C1005
C3, C4, C5, C10, C12: 100nF; C1005
C6, C11: 10uF; C1608
C7, C8: 22pF; C1005
C9: 4.7nF; C1005
D1, D3: SS14; SOD123
D2: SMAJ16A; SMA
D4: 3.3V; SOD123
D5: PESD1CAN; SOT23
D6: GREEN; LED-SIDE-2812
F1: 1A hold; C1206
J1: 1-967658-1; MQS-8-RA-967658
J2: DM3AT-SF-PEJM5; MICROSD-DM3AT
J3: GT-502MGG-N; GPS-5P-SMD
JP1: CLOSED; SJ2
Q1: MMBT3904; SOT23
Q2: ZXMP6A17E6Q; SOT26
R1, R2, R3: 100k; C1005
R4: 22k; C1005
R5, R6, R7, R10, R11, R12, R13: 10k; C1005
R8, R9: 60R; C1005
R14: 1k; C1005
U1: M78AR05-0.5; SIP3-M78AR05
U2: MCP25625; SSOP28
U3: Pico 2; RPI-PICO2-THT
Y1: 16MHz; HC49S

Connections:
CANH: D5.1, J1.6, R8.1, U2.4 (CANH)
CANL: D5.3, J1.5, R9.1, U2.3 (CANL)
CAN_CS: U2.17 (CS), U3.17 (GP13)
CAN_INT: U2.13 (INT), U3.19 (GP14)
CAN_MISO: U2.16 (SO), U3.16 (GP12)
CAN_MOSI: U2.15 (SI), U3.15 (GP11)
CAN_RESET: R6.1, U2.18 (RESET), U3.26 (GP20)
CAN_SCK: U2.14 (SCK), U3.14 (GP10)
CAN_STBY: U2.5 (STBY), U3.20 (GP15)
CAN_TERM_C: C9.1, JP1.2
CAN_TERM_MID: JP1.1, R8.2, R9.2
GND: C2.2, C3.2, C4.2, C5.2, C6.2, C7.2, C8.2, C9.2, C10.2, C11.2, C12.2, D2.2 (A), D4.2 (A), D5.2, J1.4, J2.6 (VSS), J2.BR, J2.L1, J2.L2, J2.L3, J2.TL, J3.2 (GND), Q1.2 (E), R4.2, U1.2 (GND), U2.10 (GND), U2.26 (VSS), U3.3 (GND1), U3.8 (GND2), U3.13 (GND3), U3.18 (GND4), U3.23 (GND5), U3.28 (GND6), U3.33 (AGND), U3.38 (GND7)
GPS_PPS: J3.5 (PPS), U3.4 (GP2)
GPS_RX: J3.4 (RXD), U3.1 (GP0)
GPS_TX: J3.3 (TXD), U3.2 (GP1)
IG_DIV: C12.1, D4.1 (K), R3.2, R4.1, R5.1, U3.34 (GP28_ADC2)
IG_RAW: J1.3, R3.1
LED_A: D6.2 (A), R14.2
LED_STATUS: D6.1 (K), U3.6 (GP4)
Q1_B: Q1.1 (B), R5.2
Q1_C: Q1.3 (C), R2.2
Q2_G: Q2.1 (G), R1.2, R2.1
RXCAN: U2.21 (RXCAN), U2.28 (RXD)
SD_CD: J2.TR, R13.1, U3.27 (GP21)
SD_CS: J2.2 (CD_DAT3), R10.1, U3.22 (GP17)
SD_DAT12: J2.1 (DAT2), J2.8 (DAT1), R12.1
SD_MISO: J2.7 (DAT0), R11.1, U3.21 (GP16)
SD_MOSI: J2.3 (CMD), U3.25 (GP19)
SD_SCK: J2.5 (CLK), U3.24 (GP18)
TXCAN: U2.20 (TXCAN), U2.24 (TXD)
TXNRTS: R7.1, U2.6 (TX1RTS), U2.7 (TX2RTS), U2.23 (TX0RTS)
V3V3: C3.1, C4.1, C10.1, C11.1, J2.4 (VDD), J3.1 (VCC), R6.2, R7.2, R10.2, R11.2, R12.2, R13.2, U2.1 (VIO), U2.19 (VDD), U3.36 (3V3OUT)
V5: C5.1, C6.1, D3.2 (A), R14.1, U1.3 (VOUT), U2.27 (VDDA)
V12P: C2.1, D1.1 (K), D2.1 (K), Q2.6 (S), R1.1
V12_FUSED: D1.2 (A), F1.2
V12_RAW: F1.1, J1.8
V12_SW: Q2.2 (D), Q2.3 (D), Q2.4 (D), Q2.5 (D), U1.1 (VIN)
VSYS: D3.1 (K), U3.39 (VSYS)
XTAL1: C7.1, U2.9 (OSC1), Y1.1
XTAL2: C8.1, U2.8 (OSC2), Y1.2

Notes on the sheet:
A VEHICLE INTERFACE / PROTECTION / HIGH-SIDE SWITCH
B 5V SWITCHING REGULATOR
C CAN (MCP25625)
F MCU (Raspberry Pi Pico 2)
D MICROSD
E GPS / STATUS LED
MotoRecoPico - Raspberry Pi Pico 2 CAN logger
Every net is drawn as wire - no labels are load-bearing. Rails run as horizontal trunks with risers on the left. LEDs are low-side driven from V5: GPIO LOW lights the LED.

Board: 1 copper layer, 42 parts (15 on the bottom side), 40 nets, no tracks yet.

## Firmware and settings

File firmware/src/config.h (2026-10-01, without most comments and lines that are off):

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
#define CONFIG_H
#define PIN_SD_SCK		2
#define PIN_SD_MOSI		3
#define PIN_SD_MISO		4
#define PIN_SD_CS		5	// driven as plain GPIO, not the SPI hardware CSn
#define PIN_SD_CD		7	// card detect switch, external 10k pull up (R13)
#define PIN_GPS_TX		0	// pico -> module RXD (green wire)
#define PIN_GPS_RX		1	// module TXD (orange wire) -> pico
#define PIN_GPS_PPS		6	// not used yet. kept so the pin is not repurposed by accident
#define PIN_LED			8
#define PIN_CAN_INT		9	// active low, open drain on the MCP25625 side
#define PIN_CAN_SCK		10
#define PIN_CAN_MOSI	11
#define PIN_CAN_MISO	12
#define PIN_CAN_CS		13	// driven as plain GPIO, not the SPI hardware CSn
#define PIN_CAN_STBY	20	// high puts the transceiver in standby
#define PIN_CAN_RESET	21	// active low, has a 10k pull up (R6)
#define PIN_IG_SENSE	28
#define IG_ADC_INPUT	2	// GP28 is ADC2
#define SPI_INSTANCE_OF(gpio)	(((gpio) / 8) % 2)	// 0 = spi0, 1 = spi1
#define SPI_FUNC_OF(gpio)		((gpio) % 4)		// 0 = RX, 1 = CSn, 2 = SCK, 3 = TX
#define SPI_FUNC_RX		0
#define SPI_FUNC_CSN	1
#define SPI_FUNC_SCK	2
#define SPI_FUNC_TX		3
#define SD_CD_INSERTED_LEVEL 0
#define CAN_SPI_BAUD		10000000	// 10MHz. MCP25625 allows 10MHz
#define SD_SPI_BAUD_INIT	400000		// the card spec requires <=400kHz until it is initialized
#define SD_SPI_BAUD_RUN		12500000	// raised after initialization
#define GPS_UART_BAUD		9600		// GT-502MGG-N. confirmed against the module on hardware
#define CAN_BITRATE_500K	0
#define CAN_BITRATE_250K	1
#define CAN_BITRATE_125K	2
#define CAN_BITRATE_1M		3
#define CAN_BITRATE		CAN_BITRATE_500K
#define LOG_DIR				""			// root of the card. keep the trailing slash if you set one
#define LOG_TMP_PREFIX		"TMP"		// TMPnnnnn.DAT until GPS gives us a wall clock
#define DEBUG_LOG_FILE		"motoreco.log"
#define DEBUG_LOG_FILE_OLD	"motoreco.log.1"
#define DEBUG_LOG_MAX_BYTES	1048576		// rotate at 1MB, one retained generation, as on the pi
#define LOG_FLUSH_INTERVAL_MS	1000	// f_sync interval. an abnormal power cut costs this much
#define DROP_REPORT_INTERVAL_MS	10000	// rate limit for the receive overflow report
#define SD_RETRY_INTERVAL_MS	5000	// how often a missing or broken card is retried
#define STATUS_INTERVAL_MS		30000	// periodic "still alive" line in the debug log.
#define GPS_REPORT_INTERVAL_MS	10000
#define GPS_SILENT_WARN_MS		5000	// no sentence at all for this long means wiring or baud
#define IG_OFF_MV				350		// 0.35V, the threshold netlist.md section 4.7 recommends
#define IG_ON_MV				500		// hysteresis. the live level is about 650mV
#define IG_POLL_INTERVAL_MS		10
#define IG_OFF_SAMPLES			2		// 20ms of the 400ms budget spent on being sure
#define IG_ON_SAMPLES			2
#define IG_OFF_SURVIVAL_LOG		0
#define IG_OFF_SURVIVAL_STEP_MS	50
#define IG_OFF_SURVIVAL_MAX_MS	1000
#define SETTINGS_FILE		"MOTORECO.CFG"	// hidden, in the root of the card
#define DEFAULT_TZ_TEXT		"+9"		// JST
#define DEFAULT_TZ_OFFSET_SEC	(9 * 3600)	// must match DEFAULT_TZ_TEXT
#define CAN_RING_RECORDS	4096
#define GPS_RING_BYTES		2048	// UART receive ring. one NMEA sentence is at most 82 bytes
#define LED_BLINK_NOFIX_MS	500		// 1Hz: logging, but GPS has no fix yet
#define LED_BLINK_ERROR_MS	100		// fast: no card or the card stopped accepting writes

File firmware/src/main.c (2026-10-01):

// MIT License
//
// Copyright (c) 2026 Schwarze Lanzenreiter
//
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
// MotoRecoPico: the raspberry pi CAN + GPS logger (MotoRecoLogger/mrlogger.c) ported to a
// Pico 2 on the board described in docs/netlist.md. it writes the same .dat format, so the files
// open in MotoRecoViewer unchanged.
//
// everything runs in one loop. only two things are interrupt driven: CAN receive, because the
// controller has just two receive buffers and cannot wait for an SD write to finish, and the GPS
// UART, because 9600 baud does not survive being polled around a card that stalls for 200ms.

#include <stdio.h>
#include <string.h>

#include "hardware/adc.h"
#include "hardware/gpio.h"
#include "hardware/irq.h"
#include "hardware/uart.h"
#include "pico/stdlib.h"

#include "config.h"
#include "led.h"
#include "logger.h"
#include "mcp25625.h"
#include "motoreco.h"
#include "nmea.h"
#include "power.h"
#include "record.h"
#include "sd_spi.h"
#include "settings.h"
#include "settings_file.h"
#include "wallclock.h"

// ---------------------------------------------------------------------------
// GPS serial
// ---------------------------------------------------------------------------

static uint8_t g_gps_ring[GPS_RING_BYTES];
static volatile uint32_t g_gps_head;
static volatile uint32_t g_gps_tail;
static volatile uint32_t g_gps_drops;

static void on_uart_rx(void)
{
	while (uart_is_readable(uart0)) {
		uint8_t c = (uint8_t)uart_getc(uart0);
		uint32_t next = (g_gps_head + 1) % GPS_RING_BYTES;

		if (next == g_gps_tail) {
			g_gps_drops++;
			continue;
		}

		g_gps_ring[g_gps_head] = c;
		g_gps_head = next;
	}
}

static bool gps_pop(uint8_t *out)
{
	uint32_t tail = g_gps_tail;

	if (tail == g_gps_head) {
		return false;
	}

	*out = g_gps_ring[tail];
	g_gps_tail = (tail + 1) % GPS_RING_BYTES;

	return true;
}

static void gps_uart_init(void)
{
	uart_init(uart0, GPS_UART_BAUD);
	gpio_set_function(PIN_GPS_TX, GPIO_FUNC_UART);
	gpio_set_function(PIN_GPS_RX, GPIO_FUNC_UART);
	uart_set_hw_flow(uart0, false, false);
	uart_set_format(uart0, 8, 1, UART_PARITY_NONE);
	uart_set_fifo_enabled(uart0, true);

	irq_set_exclusive_handler(UART0_IRQ, on_uart_rx);
	irq_set_enabled(UART0_IRQ, true);
	uart_set_irq_enables(uart0, true, false);

	// PPS is wired but unused. leave it an input so nothing drives against the module
	gpio_init(PIN_GPS_PPS);
	gpio_set_dir(PIN_GPS_PPS, GPIO_IN);
}

// ---------------------------------------------------------------------------
// state
// ---------------------------------------------------------------------------

static nmea_fix_t g_fix;
static nmea_reader_t g_reader;
static settings_t g_settings;

static uint64_t g_time_base_us;		// monotonic time of the first record in the current file
static bool g_time_base_set;

static int32_t g_lon_prev;			// duplicate suppression, exactly as the pi version did it
static int32_t g_lat_prev;

// one shot reporting flags. these paths are hit on every loop iteration while the condition
// lasts, and an unthrottled debug log would be the slowest thing in the firmware
static bool g_flg_nofix;
static bool g_flg_noalt;
static bool g_flg_nonstd;
static bool g_flg_sd_err;

static uint32_t g_overflow_total;
static uint32_t g_nonstd_dropped;

// GPS diagnostics. a slow fix has several very different causes (nothing on the wire, wrong baud,
// no antenna, no sky, or simply a cold start) and they are indistinguishable from "not fixed yet"
// unless the receiver's own view of the world is recorded
static uint32_t g_gps_sentences;		// well formed sentences, all types
static uint32_t g_gps_bad;				// dropped on framing or checksum
static uint64_t g_gps_last_sentence_us;
static bool g_gps_seen_any;
static bool g_flg_gps_silent;
static uint64_t g_gps_search_start_us;	// when the current search began

static void reset_log_state(void)
{
	// the pi cleared these on every key on, so each trip's file is self contained. a restart at
	// the same spot would otherwise have its first fix suppressed as a duplicate
	g_time_base_set = false;
	g_lon_prev = 0;
	g_lat_prev = 0;
	g_flg_noalt = false;
	g_flg_nonstd = false;

	// g_flg_nofix is deliberately not touched here. it tracks whether the receiver currently has
	// a fix, not whether something was reported, so opening a new file must not disturb it
}

static void stamp_record(struct CANData *rec, uint64_t now_us)
{
	if (!g_time_base_set) {
		g_time_base_set = true;
		g_time_base_us = now_us;
	}

	record_set_elapsed(rec, now_us - g_time_base_us);
}

// ---------------------------------------------------------------------------
// ignition
//
// this is the one deadline in the firmware. the board keeps itself alive for a guaranteed 0.4s
// after the key goes off (docs/netlist.md section 4.7), and the log has to be flushed, closed and
// renamed inside it. sampling therefore runs off a timer rather than the main loop: an SD write
// can stall the loop for a couple of hundred milliseconds, and spending the budget on noticing
// would leave none for acting
// ---------------------------------------------------------------------------

static power_state_t g_power;
static repeating_timer_t g_ig_timer;
static volatile power_event_t g_power_event;	// posted by the timer, consumed by the main loop
static volatile int g_ig_mv;
static bool g_powered_off;		// ignition gone and the log closed. stay idle until it returns

static int read_ig_mv(void)
{
	adc_select_input(IG_ADC_INPUT);

	// 12 bit against the 3.3V reference. no divider maths: since v3 this pin is a clamped 0.65V
	// logic level, not a scaled battery voltage
	return (int)((uint32_t)adc_read() * 3300u / 4095u);
}

static bool ig_sample(repeating_timer_t *timer)
{
	power_event_t event;

	(void)timer;

	g_ig_mv = read_ig_mv();
	event = power_eval(&g_power, g_ig_mv);

	if (event != POWER_EVENT_NONE) {
		g_power_event = event;
	}

	return true;
}

// ---------------------------------------------------------------------------
// CAN
// ---------------------------------------------------------------------------

static bool handle_can_frames(void)
{
	can_frame_t frame;
	struct CANData rec;
	bool ok = true;
	int budget = CAN_RING_RECORDS;

	// bounded, so a bus busy enough to refill the ring as fast as it drains cannot starve the
	// GPS and housekeeping below
	while (budget-- > 0 && mcp25625_pop(&frame)) {
		// struct CANData.id is 16 bits wide and has no room for a 29 bit id or a remote flag.
		// the pi version dropped these rather than truncating them into a wrong standard id
		if (frame.extended || frame.rtr) {
			g_nonstd_dropped++;

			if (!g_flg_nonstd) {
				g_flg_nonstd = true;
				logger_debug("non standard can frame is dropped. id:%08X ext:%d rtr:%d",
					(unsigned int)frame.id, frame.extended, frame.rtr);
			}

			continue;
		}

		stamp_record(&rec, frame.timestamp_us);
		rec.id = (unsigned short int)(frame.id & 0x7FF);

		// no DLC field in the record, so a short frame is zero filled and becomes
		// indistinguishable from a padded one. same as the pi version
		memset(rec.data, 0, sizeof(rec.data));
		memcpy(rec.data, frame.data, (frame.dlc > 8) ? 8 : frame.dlc);

		if (!logger_write(&rec)) {
			ok = false;
		}
	}

	return ok;
}

// ---------------------------------------------------------------------------
// GPS
// ---------------------------------------------------------------------------

// one line describing what the receiver currently sees. used for the periodic search report, the
// moment a fix appears, and the moment one is lost
static void log_gps_state(const char *what, uint64_t now_us)
{
	uint32_t elapsed_s = (uint32_t)((now_us - g_gps_search_start_us) / 1000000ULL);

	logger_debug("gps %s after %us: quality:%d mode:%dD sats used:%d view:%d tracked:%d "
		"best snr:%d hdop:%.1f sentences:%u bad:%u",
		what, (unsigned int)elapsed_s,
		g_fix.quality, g_fix.fix_mode, g_fix.sats_used,
		nmea_sats_in_view(&g_fix), nmea_sats_tracked(&g_fix), nmea_best_snr(&g_fix),
		(double)g_fix.hdop,
		(unsigned int)g_gps_sentences, (unsigned int)g_gps_bad);
}

static bool handle_gps_sentence(const char *sentence, uint64_t now_us)
{
	struct CANData rec;
	int32_t lon, lat;
	bool ok = true;
	int result = nmea_parse(&g_fix, sentence);

	if (result == NMEA_RESULT_INVALID) {
		// a few of these at power up are normal, the receiver may be mid sentence when the UART
		// starts. a steady stream of them means the baud rate is wrong
		g_gps_bad++;
		return true;
	}

	g_gps_sentences++;
	g_gps_last_sentence_us = now_us;
	g_flg_gps_silent = false;

	// the first sentence proves the wiring and the baud rate. worth its own line, because
	// everything that comes after assumes both
	if (!g_gps_seen_any) {
		char head[8];
		size_t i;

		g_gps_seen_any = true;

		for (i = 0; i < sizeof(head) - 1 && sentence[i] != '\0' && sentence[i] != ','; i++) {
			head[i] = sentence[i];
		}

		head[i] = '\0';
		logger_debug("gps talking: first sentence '%s' at %d baud", head, GPS_UART_BAUD);
	}

	if (result == NMEA_RESULT_IGNORED) {
		return true;
	}

	// the receiver is the only clock on the board. re-anchor on every sentence that carries a
	// date, which also corrects the drift of the pico's own oscillator over a long ride
	if (g_fix.has_time) {
		bool was_valid = wallclock_valid();

		wallclock_set(g_fix.unix_time, now_us);

		if (!was_valid) {
			logger_debug("gps time acquired");
		}

		// the trip started before we knew the date, so it is still under a placeholder name
		if (logger_has_temp_name() && logger_name_from_clock()) {
			logger_debug("log renamed to '%s'", logger_filename());
		}
	}

	if (!g_fix.has_fix) {
		// losing a fix mid ride (a tunnel, a bad antenna connection) restarts the search, and the
		// periodic report below then shows whether it is coming back
		if (!g_flg_nofix) {
			g_flg_nofix = true;
			log_gps_state("fix lost", now_us);
			g_gps_search_start_us = now_us;
		}

		return true;
	}

	if (g_flg_nofix) {
		g_flg_nofix = false;
		log_gps_state("fixed", now_us);
	}

	lon = record_encode_lon(g_fix.longitude);
	lat = record_encode_lat(g_fix.latitude);

	// GGA and RMC both carry the position, so a standing bike would otherwise write the same
	// point twice a second forever
	if (lon == g_lon_prev && lat == g_lat_prev) {
		return true;
	}

	g_lon_prev = lon;
	g_lat_prev = lat;

	stamp_record(&rec, now_us);
	record_gps_position(&rec, g_fix.latitude, g_fix.longitude);

	if (!logger_write(&rec)) {
		ok = false;
	}

	// altitude and speed are missing while the fix is 2D only. the pi saw those as NaN from gpsd
	// and skipped this frame rather than logging garbage
	if (!g_fix.has_altitude || !g_fix.has_speed) {
		if (!g_flg_noalt) {
			g_flg_noalt = true;
			logger_debug("altitude or speed is not available. skip GPS data2");
		}

		return ok;
	}

	g_flg_noalt = false;

	stamp_record(&rec, now_us);
	record_gps_alt_speed(&rec, g_fix.altitude, g_fix.speed);

	if (!logger_write(&rec)) {
		ok = false;
	}

	return ok;
}

static bool handle_gps(uint64_t now_us)
{
	uint8_t c;
	bool ok = true;
	int budget = GPS_RING_BYTES;

	while (budget-- > 0 && gps_pop(&c)) {
		const char *sentence = nmea_reader_push(&g_reader, (char)c);

		if (sentence != NULL && !handle_gps_sentence(sentence, now_us)) {
			ok = false;
		}
	}

	return ok;
}

// ---------------------------------------------------------------------------
// card handling
// ---------------------------------------------------------------------------

// reads the settings off the card, or writes a default file if there is none. runs on every
// successful mount, so swapping in a card with a different settings file takes effect
static void load_settings(void)
{
	settings_file_result_t res;
	char tz[12];
	int bad = 0;

	res = settings_file_load(&g_settings, &bad);

	if (res == SETTINGS_FILE_ERROR) {
		logger_debug("settings: '%s' could not be read or created. using the built in defaults",
			SETTINGS_FILE);
	} else if (res == SETTINGS_FILE_CREATED) {
		logger_debug("settings: no '%s' on the card, wrote one with the defaults", SETTINGS_FILE);
	}

	// applying them is separate from reading them, so the defaults take effect even after an
	// unreadable card
	wallclock_set_tz(g_settings.tz_offset_sec);

	settings_format_tz(g_settings.tz_offset_sec, tz, sizeof(tz));

	logger_debug("settings: timezone %s%s", tz,
		(bad > 0) ? " [some lines were ignored]" : "");
}

static void mount_card(void);

// the trip is finalized in exactly one place: when the ignition goes away. an earlier version
// also watched the tachometer on the CAN bus, but that needed a decode rule and a set of
// thresholds per model, and the ignition line says the same thing on every bike.
//
// grep the debug log for "trigger:" to find it
// acts on what the ignition sampler found. this is the deadline path: on power off the log is
// closed for good, on a return the next trip starts in a new file
static void handle_ignition(void)
{
	power_event_t event = g_power_event;

	if (event == POWER_EVENT_NONE) {
		return;
	}

	g_power_event = POWER_EVENT_NONE;

	if (event == POWER_EVENT_OFF) {
#if IG_OFF_SURVIVAL_LOG
		// taken before the card work, so the measurement below covers the whole shutdown
		uint64_t now_us = time_us_64();
#endif
		logger_finalize_t result = logger_shutdown();

		g_powered_off = true;

		// the debug line is written after the card work, deliberately. it opens and closes
		// another file, and the trip log has first claim on the time that is left
		if (result == LOGGER_FINALIZE_DONE) {
			logger_debug("trigger: ignition off (%dmV). log closed and renamed as '%s'",
				g_ig_mv, logger_filename());
		} else {
			logger_debug("trigger: ignition off (%dmV). %s",
				g_ig_mv, logger_finalize_text(result));
		}

#if IG_OFF_SURVIVAL_LOG
		// how long the supply actually lasts is the number every deadline here is built on, and
		// it has only ever been calculated. keep writing until it gives out: whichever line makes
		// it onto the card last is the measurement. see config.h for turning this off
		{
			uint32_t step_ms = IG_OFF_SURVIVAL_STEP_MS;

			while (step_ms <= IG_OFF_SURVIVAL_MAX_MS) {
				while (time_us_64() - now_us < (uint64_t)step_ms * 1000ULL) {
					tight_loop_contents();
				}

				logger_debug("power still up %llums after ignition off",
					(unsigned long long)((time_us_64() - now_us) / 1000ULL));

				step_ms += IG_OFF_SURVIVAL_STEP_MS;
			}
		}
#endif

		// only now. logger_shutdown() leaves the card mounted precisely so the lines above can
		// reach motoreco.log rather than only the USB port nobody is plugged into on a bike
		logger_unmount();

		return;
	}

	// ignition back while we are still alive. that means the supply never actually went away,
	// which happens on the bench over USB, or if the key was flicked off and straight back on.
	// the closed file stays closed and the next trip gets its own. mount_card() also rereads the
	// settings for the new trip
	g_powered_off = false;
	logger_debug("ignition back on (%dmV). starting a new log", g_ig_mv);
	mount_card();
}
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
int main(void)
{
	uint64_t now_us;
	uint64_t last_sync_us = 0;
	uint64_t last_status_us = 0;
	uint64_t last_retry_us = 0;
	uint64_t last_gps_report_us = 0;
	uint64_t last_overflow_us = 0;
	uint64_t last_drop_report_us = 0;
	uint32_t reported_ring_drops = 0;
	bool can_ok;

	stdio_init_all();

	led_init();
	led_set(LED_ERROR);

	wallclock_init();
	nmea_init(&g_fix);
	nmea_reader_init(&g_reader);
	// the built in default is in effect until the card is mounted and its settings file read,
	// which is a second or two later. nothing that happens in between depends on it
	settings_defaults(&g_settings);
	wallclock_set_tz(g_settings.tz_offset_sec);

	reset_log_state();

	// the receiver starts out unfixed, so the first fix counts as an acquisition and gets logged
	g_flg_nofix = true;

	adc_init();
	adc_gpio_init(PIN_IG_SENSE);
	power_init(&g_power);

	// negative period means "this often", measured from the end of the callback
	add_repeating_timer_ms(-IG_POLL_INTERVAL_MS, ig_sample, NULL, &g_ig_timer);

	sd_spi_hw_init();
	gps_uart_init();

	logger_debug("MotoRecoPico starting");

	mount_card();

#ifdef CAN_SELF_TEST
	can_ok = mcp25625_init(true);
#else
	can_ok = mcp25625_init(false);
#endif

	if (!can_ok) {
		// nothing else to do about it: without the controller there is no CAN data at all. keep
		// running so the GPS track is still recorded and the failure is visible in the log
		logger_debug("mcp25625 did not respond. check spi wiring and power");
	} else {
		logger_debug("can controller ready");
	}

#ifdef CAN_SELF_TEST
	if (can_ok) {
		can_self_test();
	}
#endif

	while (true) {
		now_us = time_us_64();

		// before anything else. every millisecond spent elsewhere comes out of the 0.4s the
		// board has left once this fires
		handle_ignition();

		if (logger_is_open()) {
			if (!handle_can_frames()) {
				drop_card("write failed");
			}

			if (logger_is_open() && !handle_gps(now_us)) {
				drop_card("write failed");
			}
		} else {
			// no card: still drain both sources, or the CAN ring fills and the UART overruns
			handle_can_frames();
			handle_gps(now_us);
		}

		if (now_us - last_sync_us >= (uint64_t)LOG_FLUSH_INTERVAL_MS * 1000ULL) {
			last_sync_us = now_us;

			if (logger_is_open() && !logger_sync()) {
				drop_card("sync failed");
			}

			// a card pulled mid ride is worth catching early, but only where the detect line has
			// proven itself by agreeing with a card that actually answered. on a board where it
			// is miswired or chattering from vibration, this check would throw away a perfectly
			// good card once a second. without it, a real removal still surfaces as a failed
			// write on the next flush
			if (logger_is_open() && sd_detect_reliable() && !sd_card_present()) {
				drop_card("card removed");
			}
		}

		if (now_us - last_overflow_us >= 1000000ULL) {
			last_overflow_us = now_us;

			// frames the controller had to drop leave no trace in the .dat file. this is the
			// only evidence, exactly like the pi version's SO_RXQ_OVFL reporting
			g_overflow_total += mcp25625_check_overflow();
		}

		if (now_us - last_drop_report_us >= (uint64_t)DROP_REPORT_INTERVAL_MS * 1000ULL) {
			uint32_t drops = mcp25625_ring_drops();

			last_drop_report_us = now_us;

			if (g_overflow_total > 0 || drops != reported_ring_drops) {
				logger_debug("can rx overflow. controller episodes:%u ring drops:%u (+%u)",
					(unsigned int)g_overflow_total, (unsigned int)drops,
					(unsigned int)(drops - reported_ring_drops));
				reported_ring_drops = drops;
				g_overflow_total = 0;
			}
		}

		// while there is no fix, say what the receiver can see. this is the difference between
		// "the antenna sees nothing" and "it sees eight satellites and is still resolving them",
		// which otherwise both look like a GPS that takes too long
		if (!g_fix.has_fix &&
		    now_us - last_gps_report_us >= (uint64_t)GPS_REPORT_INTERVAL_MS * 1000ULL) {
			last_gps_report_us = now_us;

			if (!g_gps_seen_any) {
				// the module talks as soon as it is powered, fix or no fix, so silence is a
				// wiring or power fault rather than a reception problem
				logger_debug("gps silent: nothing received on uart0 in %us. "
					"check the module's TXD reaches GP1, its power, and the common ground",
					(unsigned int)((now_us - g_gps_search_start_us) / 1000000ULL));
			} else {
				log_gps_state("searching", now_us);
			}
		}

		// the receiver went quiet after having talked: a broken wire, a browned out module, or a
		// baud rate that drifted. distinct from never having said anything at all
		if (g_gps_seen_any && !g_flg_gps_silent &&
		    now_us - g_gps_last_sentence_us >= (uint64_t)GPS_SILENT_WARN_MS * 1000ULL) {
			g_flg_gps_silent = true;
			logger_debug("gps went quiet: no sentence for %ums after %u good ones",
				(unsigned int)((now_us - g_gps_last_sentence_us) / 1000ULL),
				(unsigned int)g_gps_sentences);
		}

		// retry a missing or broken card, but not while the ignition is off: there the log was
		// closed on purpose, and reopening one would undo that a few seconds later
		if (!logger_is_open() && !g_powered_off &&
		    now_us - last_retry_us >= (uint64_t)SD_RETRY_INTERVAL_MS * 1000ULL) {
			last_retry_us = now_us;
			mount_card();
		}

		if (now_us - last_status_us >= (uint64_t)STATUS_INTERVAL_MS * 1000ULL) {
			last_status_us = now_us;
			// ig is the raw pin level, not a battery voltage. this pin cannot measure the
			// battery on this board, see config.h
			logger_debug("status: rx:%u records:%u ig:%dmV(%s) | gps fix:%d mode:%dD "
				"sats used:%d view:%d snr:%d hdop:%.1f sentences:%u bad:%u uart_lost:%u",
				(unsigned int)mcp25625_rx_count(), (unsigned int)logger_records_written(),
				g_ig_mv, g_power.off ? "off" : "on",
				g_fix.has_fix, g_fix.fix_mode, g_fix.sats_used,
				nmea_sats_in_view(&g_fix), nmea_best_snr(&g_fix), (double)g_fix.hdop,
				(unsigned int)g_gps_sentences, (unsigned int)g_gps_bad,
				(unsigned int)g_gps_drops);
		}

		if (g_powered_off) {
			// closed cleanly and waiting for the supply to go. a blink here would be a lie, and
			// on the bench it would look like a card fault
			led_set(LED_IDLE);
		} else if (!logger_is_open()) {
			led_set(LED_ERROR);
		} else if (!g_fix.has_fix) {
			led_set(LED_NO_FIX);
		} else {
			led_set(LED_LOGGING);
		}

		led_update(now_us);

		// nothing to do until the next interrupt. this is not a fixed rate loop, it just yields
		// the core between bursts of work
		tight_loop_contents();
	}

	return 0;
}

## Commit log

2026-10-01 ハードウェア設計一式を追加 (基板 v4.2)
    - cad/kicad: KiCad 10 プロジェクト (回路図・配線済み 4 層基板・自作
    フットプリント) と、ネット定義から基板・回路図・製造データを生成する
    _scripts 一式。配線済み .kicad_pcb は再配線で再現できないため成果物
    として追跡する
    - cad/kicad/fab: ガーバー/ドリル/BOM/CPL/SVG (DRC 0 違反・未接続 0)
    - cad/electronics: 元になった EAGLE 設計 (v1)
    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
    [MotoRecoPico-B_Cu.gbl, MotoRecoPico-B_Mask.gbs, MotoRecoPico-B_Paste.gbp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]
2026-10-01 ファームウェアを追加 (CAN + GPS ロガー)
    Raspberry Pi 版 mrlogger.c の Pico 2 (RP2350) 移植。.dat は Pi 版とバイナリ
    互換なので、MotoRecoViewer がそのまま開ける。
    - CAN: MCP25625 を SPI1 で駆動。受信は割込みでリングバッファへ退避する。
    SD の書き込みが数百 ms 止まる間もコントローラの 2 段 FIFO を溢れさせない
    - GPS: UART0 の NMEA を自前でパース (GGA/RMC/GSA/GSV)。gpsd の代替
    - 保存: FatFs R0.16 を同梱。SD の SPI ブロックドライバは自作
    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
2026-10-01 ルートに README を追加
    プロジェクト全体の入口が無く、トップページが LICENSE と3つのディレクトリだけ
    だったため追加した。
    - 何をするものか、Pi 版 (MotoRecoLogger) との関係
    - リポジトリ構成と、各ディレクトリの入口となる文書への導線
    - ハードウェアの要点 (基板・主要部品・電源・IG OFF 後の保持時間)
    - ファームウェアの要点
    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
2026-10-13 GPS を 10Hz 化し、測位前の時刻を信用しないようにした
    実車で 10Hz を検証したところ、受信機が 100ms を拒否していた
    ($PMTK001,220,2 = "valid command, action failed")。9600 8N1 の 960 B/s に対し
    GGA+RMC を 10Hz で出すには約 1,530 B/s 必要なため、出力しきれない周期を
    モジュール自身が蹴っていた。実測も 1Hz のままだった。
    この検証中に、10Hz とは独立した実害のあるバグ 3 件が判明したので併せて直した。
    - ファームが拒否を成功と報告していた。gps_cfg_on_ack() の `flag != 3` 枝が
    return も else も持たず、flag を見ないディスパッチャに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
2026-10-13 README: 10Hz の実測値に差し替え
    115200 で 10Hz が通ったことを実機ログで確認したので、見積りで書いていた
    スループット例を実測値（1440 B/s、20文/秒、1文 72B、115200 の 12%）に
    差し替え、結果の節と実測値の表を追記した。
    1測位あたり 144 バイトという見積りは実測と一致し、9600 の 960 B/s では
    最初から入らなかったことが裏付けられた。モジュールの拒否は正しかった。
    バックオフは1段も走らず 100ms が1発で受理され、bad:0 uart_lost:0。
    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
2026-10-13 GSA / GSV を 5分周 (2Hz) で復活させた
    115200 にして帯域が空いたので、診断用の GSA と GSV を戻した。測位の
    payload である GGA と RMC は毎測位のまま、GSA と GSV は5測位ごと。
    1Hz ではなく 2Hz なのは妥協ではなく上限。PMTK314 の各フィールドは
    測位レートの分周比で、ガイドが定義する最大は 5
    ("5 - Output once every five position fixes")。測位が 10Hz なので
    5分周の 2Hz より遅くは指定できない。衛星数を見るには十分。
    帯域は GGA+RMC 1440 B/s (実測) + GSA/GSV 約1200 B/s (概算) で
    約 2600 B/s、115200 の約23%。GLL と VTG は GGA/RMC と重複するので
    引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
2026-10-13 レコード時刻に単調性クランプを入れた
    実機ログ (GPS 10Hz + CAN 再生、27,846レコード) で時刻が 4回巻き戻って
    いた。最大 2ms。1Hz のログでは 0件だったので、GPS を10倍にして露出した。
    idx 14376: CAN 0x29C @148773ms -> GPS 0x7FF @148771ms (-2ms)
    idx 16112: CAN 0x290 @150266ms -> GPS 0x7FF @150264ms (-2ms)
    idx 22262: CAN 0x290 @155566ms -> GPS 0x7FF @155565ms (-1ms)
    idx 23078: CAN 0x290 @156266ms -> GPS 0x7FF @156264ms (-2ms)
    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
2026-10-13 .dat を CAN バスへ再送信する Python ツールを追加
    MotoReco で記録した .dat を CANable v2.0 経由で CAN バスへ流し直す
    dat_replay.py。ロガーをベンチで試すときに、実車の CAN を再現するため。
    - python-can を使う。出荷時の slcan (-c COM5) と candleLight の gs_usb
    (-i gs_usb -c 0) の両方に対応
    - 記録時刻どおりの間隔で送る。-s で速度倍率、0 で待たずに最速
    - .dat には DLC が無いので、常に 8 バイトの標準 ID で送る
    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
2026-10-13 GPS リングを 8192 バイトにし、メインループの停止を計測する
    CAN 再生 + GPS 10Hz のベンチで、GPS が 0.93 秒途切れ uart_lost:455 が
    出た。メインループが SD の書き込みで止まり、その間に 2048 バイトの
    UART リングが溢れたため。
    9.890s の次の測位が 10.816s、そこから 4 測位が 1ms 以内に並ぶ
    (止まっていた間にリングに残った分を、復帰後にまとめて処理した跡)
    約 2.7KB/s では 2048 バイトは 0.77 秒しか持たず、溢れた約 0.16 秒分が
    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
2026-10-13 起動時に 0 バイトの TMP*.DAT を削除する
    ファームを書き込むと、最初の起動が TMP00001.DAT を作った直後に Pico が
    自動で再起動する。1 レコードも書かないうちに電源が切れるので、0 バイトの
    TMP ファイルが毎回カードに残っていた (日付 2026-01-01)。
    logger_mount() で新しいログを開く前に、TMP で始まり .DAT で終わる 0 バイトの
    ファイルを消す。起動時とカード差し替え時の両方で走る。
    - 中身のある TMP*.DAT は消さない。GPS の日付が取れないまま終わった走行の
    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
2026-10-13 GPS レコードを受信時刻で記録し、CAN と時刻順に混ぜて書く
    GPS レコードの時刻は SD に書いた時刻だった。SD がメインループを止めると、
    止まっている間に届いた測位が復帰後にまとめて書かれ、同じ時刻に並んでいた
    (0.93 秒の停止で 4 測位が 1ms 以内、最大約 0.8 秒のずれ)。CAN は割り込みで
    捕捉した時刻を持つので、GPS も受信した時刻で記録するようにした。
    - UART 割り込みが '$' をリングに入れるとき、その時刻を時刻リング (256 件) に
    入れる。時刻を入れられないなら '$' も入れないので、2 つはずれない
    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
2026-10-13 CAN 再生に使うログを差し替えた
    再生元を 20200621_143634.dat (22,821 レコード、CAN 22,793 フレーム) にし、
    replay.bat もそれに合わせた。前の再生元と requirements.txt は先に削除済み。
2026-10-13 レコードを 16KB ずつセクタ境界で書く
    ベンチで計測した SD 停止 2 件 (895ms・375ms) は、どちらも records
    フェーズ、つまり 512 バイトごとの単発書き込み (CMD24) の中で起きていた。
    IG OFF 後の猶予は保証 0.4 秒で、契約は「SD ストール最悪 250ms 込み」なので、
    確定処理の最中にこの長さの停止が来ると電源が先に落ちる。
    - WRITE_BUF_RECORDS 32 -> 1024 (16KB = 32 セクタ)。ファイル位置がセクタ
    境界にあれば、FatFs は自分のセクタバッファを通さず disk_write を複数
    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
2026-10-13 壁時計を RMC の小数秒と受信時刻で合わせ、合わせ直しは 50ms 超のときだけにする
    測位した RMC が届くたびに、壁時計を RMC の整数秒とループ先頭の時刻で
    合わせ直していた。小数秒は捨てていたので、10Hz だと .100 〜 .900 の測位が
    すべて .000 として合わせられ、毎測位ごとに最大 0.9 秒戻されていた。
    2026-10-13 のログで、デバッグログの時刻が 16ms 逆戻りしたのを観測した
    (154129.105 の次が .089)。.dat の時刻には影響しない。影響するのは
    デバッグログの時刻とファイル名だけ。
    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
2026-10-17 hdop を %.1f で出すのをやめた (SDK の printf が壊す)
    一日走行のログに hdop:00000000000000000000000000000010 が4回出ていた。
    行の他の部分は完全に正常で、sentences: 以降も正しく出ている。
    原因は pico_printf の _ftoa()。丸めた小数部がちょうど .5 に乗ったとき、
    } else if ((frac == 0U) || (frac & 1U)) { ++frac; }
    という分枝を通るが、ここには隣の diff > 0.5 分枝にある
    if (frac >= pow10[prec]) { frac = 0; ++whole; }
    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
2026-10-20 Translate the remaining documentation and user-facing script text into English
    - docs/study-jlc-assembly.md and docs/polarity-check-v5.md: previously
    untracked, now added in English.
    - The parts-sourcing workbook is regenerated in English and renamed from
    MotoRecoPico-部品購入先.xlsx to MotoRecoPico-parts-sourcing.xlsx (sheets
    Sourcing / Cautions). Structure is identical to the old file: same 26
    quantity rows summing to 43, the same =SUM(D6:D31) total, the same 63
    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
2026-10-20 Rename the two board-view PDFs to ASCII names
    cad/kicad/基板表.pdf -> board-top.pdf, cad/kicad/基板裏.pdf -> board-bottom.pdf.
    These are Print-To-PDF board views with no extractable text, so only the file
    names were Japanese. Nothing in the repository referenced them.
2026-10-23 Write the GPS fix time to the .dat as pseudo ID 0x7FD
    MotoNavi needs the absolute time of each fix: the record time only counts
    from the start of the log. One 0x7FD frame per fixed RMC (status A and a
    plausible date, the same test that sets the wall clock), queued after any
    0x7FF from that sentence, and also while standing still when 0x7FF is
    skipped as a repeat. About 160 B/s at 10 Hz, under 1% of a .dat.
    Layout, as proposed in MotoNavi docs/ride-upload-format.md 2.5:
    bytes 0-5 UTC of the fix, Unix milliseconds, 48 bit little endian
    byte 6 fix kind in the high nibble (0 none, 1 2D, 2 3D,
    3 DGPS/SBAS/RTK), satellites used in the low nibble (max 15)
    byte 7 HDOP x1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
2026-10-23 Time the 0x7FD frame by the GGA instead of the RMC
    On 20261023_182158.dat every fifth 0x7FD was recorded about 45 ms late,
    on exactly the .400 and .900 fixes: the receiver sends GSA and GSV
    between GGA and RMC on those fixes, which delays the RMC. Stamping the
    RMC-built frame with the GGA's arrival is not possible either, since
    the CAN frames of those 45 ms may already be in the file and the record
    would be pinned forward.
    0x7FD is now written when the GGA arrives, right after that sentence's
    0x7FF. GGA carries the time of day, sats and HDOP of the same fix; the
    date comes from the last RMC that may also set the wall clock (status
    A, plausible date) and is at most 60 s older, with UTC midni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
2026-10-23 Put the MCP25625 in listen-only mode and pace the CANable replay for it
    The controller ran in normal mode: it never transmitted a frame, but it
    drove an ACK into every frame it received and an error frame into every
    one it judged broken, so a wrong bitrate or bad wiring could disturb the
    bike's bus. It now runs listen-only (REQOP 011) and puts nothing on the
    bus. The CAN_SELF_TEST loopback build is unchanged.
    On a bench with only a CANable and the Pico nobody acknowledges, so
    dat_replay.py now turns the CANable's automatic retransmission off (A0,
    sent while the channel is closed; canable2-fw answers no command, so
    silence is treated as accepted). --retransmit keeps it on for a bus where
    ano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
